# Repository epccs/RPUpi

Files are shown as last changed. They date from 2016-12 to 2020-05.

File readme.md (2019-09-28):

# RPUpi

From <https://github.com/epccs/RPUpi>

## Overview

Shield used to connect a Raspberry Pi Zero (or W) to serial that can be shared (multidrop). The targets presently available are [RPUno], [RPUlux], and [Irrigate7]. The hardware allows the bus to be controlled so the host sees a single target (for bootload) or any number of them.  

A [RPUadpt] shield is also available if the host SBC does not use the Raspberry Pi 40 pin header.

[RPUno]: https://github.com/epccs/RPUno
[RPUlux]: https://github.com/epccs/RPUlux
[Irrigate7]: https://github.com/epccs/Irrigate7
[RPUadpt]: https://github.com/epccs/RPUadpt
[RPUftdi]: https://github.com/epccs/RPUftdi

## Status

[Options](./Hardware#bill-of-materials)

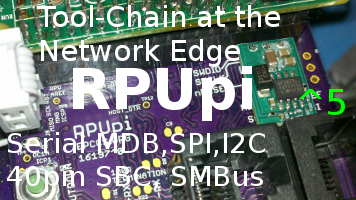
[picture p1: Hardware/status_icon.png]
Status


## [Hardware](./Hardware)

Hardware files include schematic and board images, bill of materials, and my notes on testing, evaluation, and schooling.

## Example

Both the SBC and microcontroller(s) can run simple UART serial communication software (e.g. all the RS232 software I have tried seems to work). I prefer textual commands, so my examples generally use a textual command processor which echoes back the command like an interactive terminal, the commands are used by the firmware command processor to run routines or configure state machines on the bare metal microcontrollers. The SBC host the toolchain so it can compile the firmware from the source which can be managed with git (e.g. GitHub, GitLab...) or anyway the user wishes. The toolchains uploader can be used to send the firmware to the targets bootloader. The result is one or more bare metal targets can receive updates that are compiled from source without the need for a bare metal network stack. This is not an IoT system, it is a computer hosting an operating system and toolchain connected with physical wires to bare metal embedded controllers. It is also not dependent on any cloud-based services.

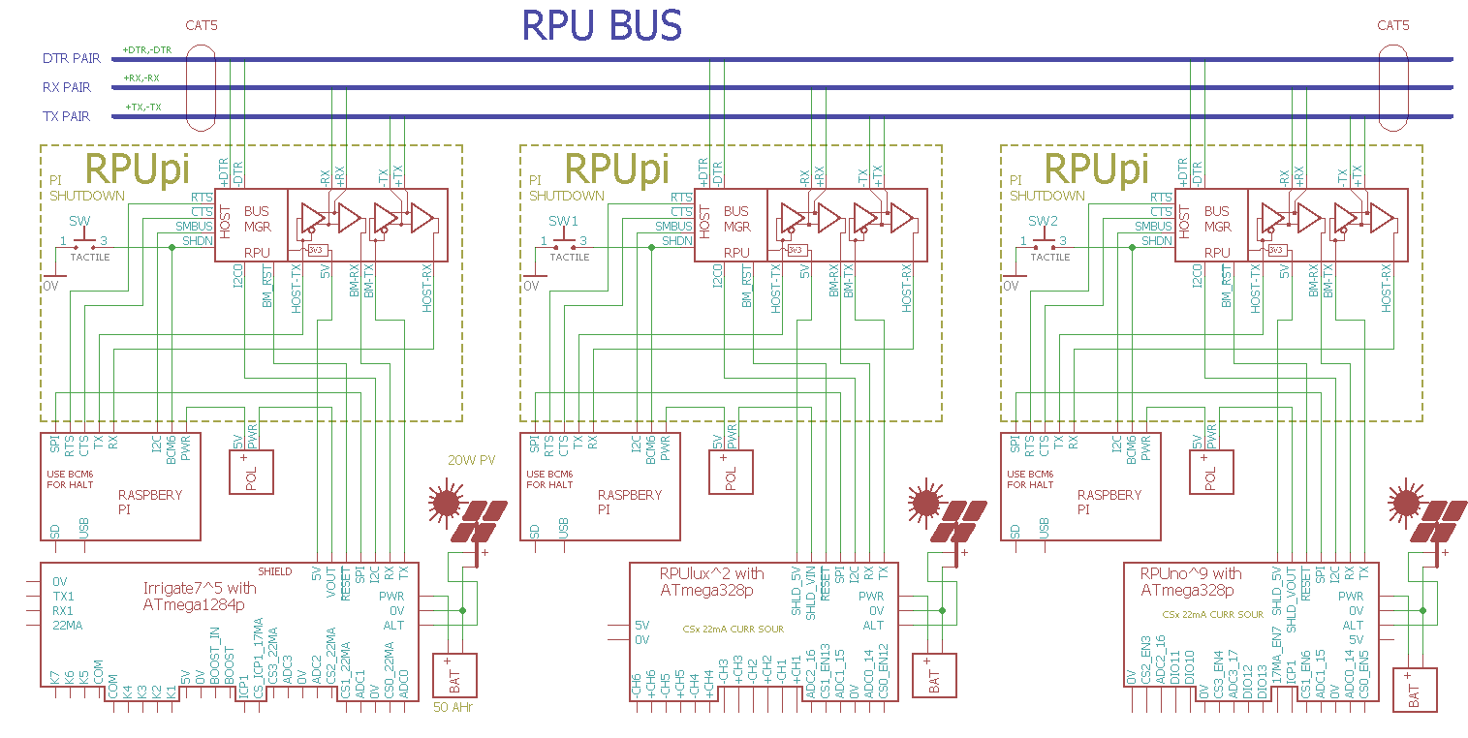
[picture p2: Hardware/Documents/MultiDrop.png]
MultiDrop


To bootload the AVR from the Raspberry Pi hardware serial port it needs to be enabled for [serial] so Linux can use the port, also the [RTS and CTS] pin functions should be enabled since nRTS is used to start the bootloader (in place of the nDTR trick used by an Arduino Uno). 

[serial]: ./Hardware/Testing/linux.md#serial
[RTS and CTS]: ./RPiRtsCts

The Pi Zero also needs a way to [halt] from a push button. When the RPUpi shield is mounted on a target board (e.g. [RPUno]) the VIN pin can be powered off with a [power management] technique.  This allows a manual shutdown and for the local target to request a halt using an I2C command. It should help with redundancy techniques, so two or more SBC's with [failover] can ensure data from the targets keep flowing. 

[failover]: https://en.wikipedia.org/wiki/Failover
[halt]: ./Shutdown
[power management]: https://github.com/epccs/RPUno/tree/master/PwrMgt

## AVR toolchain

The core files for this boards bus manager are in the /lib folder. Each example has its files and a Makefile in its own folder. The toolchain packages that I use are available on Ubuntu and Raspbian. 

```
sudo apt-get install git make gcc-avr binutils-avr gdb-avr avr-libc avrdude
git clone https://github.com/epccs/RPUpi
```

* [gcc-avr](https://packages.ubuntu.com/search?keywords=gcc-avr)
* [binutils-avr](https://packages.ubuntu.com/search?keywords=binutils-avr)
* [gdb-avr](https://packages.ubuntu.com/search?keywords=gdb-avr)
* [avr-libc](https://packages.ubuntu.com/search?keywords=avr-libc)
* [avrdude](https://packages.ubuntu.com/search?keywords=avrdude)

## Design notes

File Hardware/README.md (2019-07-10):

# Hardware

## Overview

This board connects a Pi Zero [W] to a multi-drop serial bus and a control board with a target (e.g. [RPUno], [RPUlux], [RPUicp], [Irrigate7]). 

[RPUno]: https://github.com/epccs/RPUno
[RPUlux]: https://github.com/epccs/RPUlux
[RPUicp]: https://github.com/epccs/RPUicp
[Irrigate7]: https://github.com/epccs/Irrigate7

## Inputs/Outputs/Functions

```
        Pi Zero power is from a 5V SMPS regulator powered by the Vin pin
        Pi Zero UART connects crossover style to the rpubus pairs
        rpubus pairs daisy-chain to other RPUpi or RPUadpt shields
        The UART's from multiple targets may connect to the rpubus pairs 
        An out of band management pair is used to control host to target (P2P) connection.
        SPI is available between SBC and the local target.
```

## Uses

```
        Raspberry Pi with a Raspian Linux instance is a compelling platform.
        Accessing the machine instance with SSH is prefered.
        Serving files with Samba is availalbe, but not prefered.
        The machine instance has a physical serial link (rpubus ) to the bare metal targets.
```

## Notice

```
        If the Pi Zero bootloads its local board (the one under the RPUpi) then 
        the VIN power from the local board must not turn off after a reset 
        (the defaut setup has been tested and works). 
 ```

# Table Of Contents

1. [Status](#status)
2. [Design](#design)
3. [Bill of Materials](#bill-of-materials)
4. [How To Use](#how-to-use)

# Status

Status RPUpi Status

```
        ^5  Done: Design, Layout, BOM, Review*, Order Boards, Assembly, Testing,
            WIP: Evaluation.
            Todo: 
            *during review the Design may change without changing the revision.
            AVR's nSS should goto R-Pi's nCE00 not nCE10.

        ^4  Done: Design, Layout, BOM, Review*, Order Boards, Assembly, Testing,
            WIP: Evaluation.
            Todo: 
            *during review the Design may change without changing the revision.
            IOREF is for I2C and UART
            SPI_IOREF is for SPI only
            Add SPI nSS so the Raspery Pi CE10 can use it, (it was tested with RPUadpt^6)
            remove ADC6 and ADC7.
            remove smd mounts for 100 Ohm pair termination.
            Use TI's 5V THVD1500, wich cost less and has better specs.
            Run Manager at 5V to match trancever's.
            Remove 3V3 regulator, which is no longer needed.
            Change Q1..Q3 to use K1N. 
```

Debugging and fixing problems i.e. [Schooling](./Schooling/)

Setup and methods used for [Evaluation](./Evaluation/)

# Design

The board is 0.063 thick, FR4, two layer, 1 oz copper with ENIG (gold) finish.

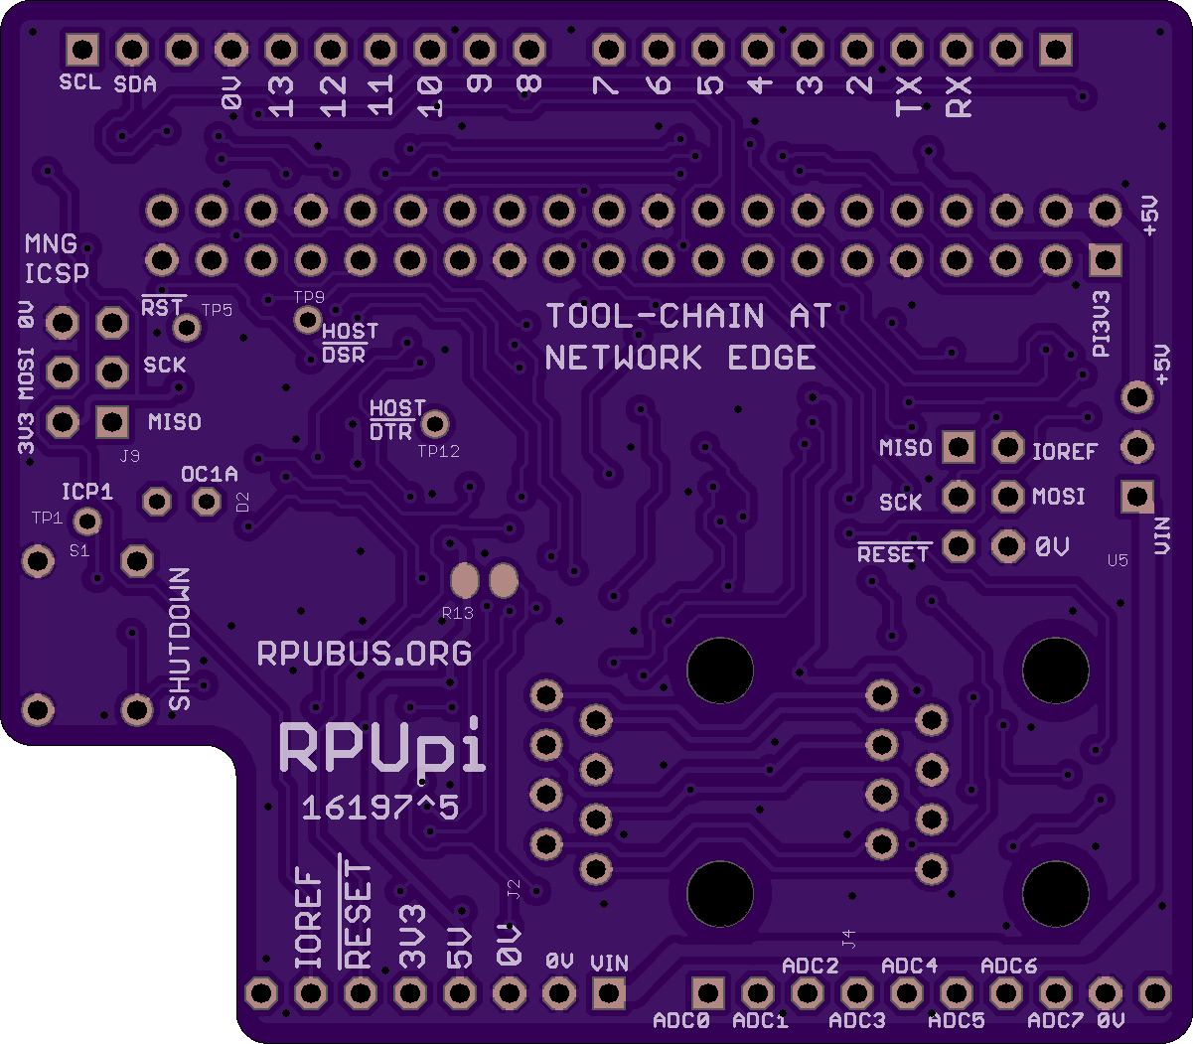
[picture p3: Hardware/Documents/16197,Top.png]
Top RPUpi Top

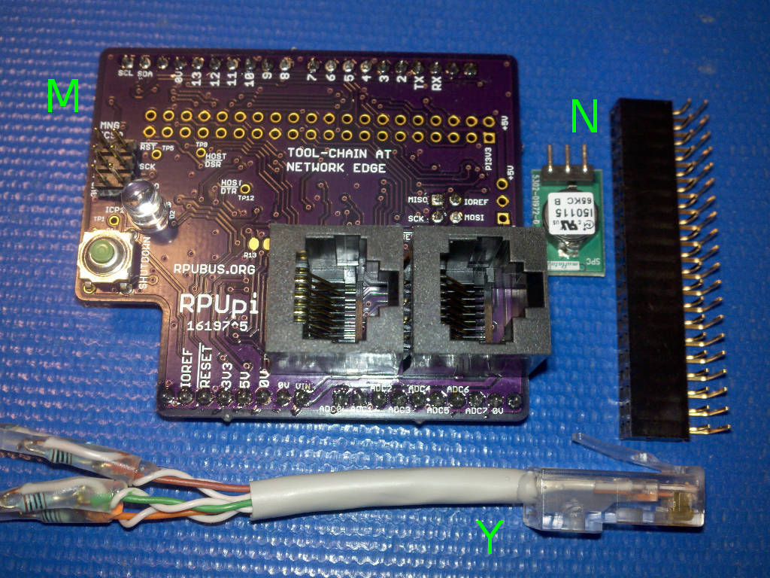
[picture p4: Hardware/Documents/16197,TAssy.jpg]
TAssy RPUpi Top Assy

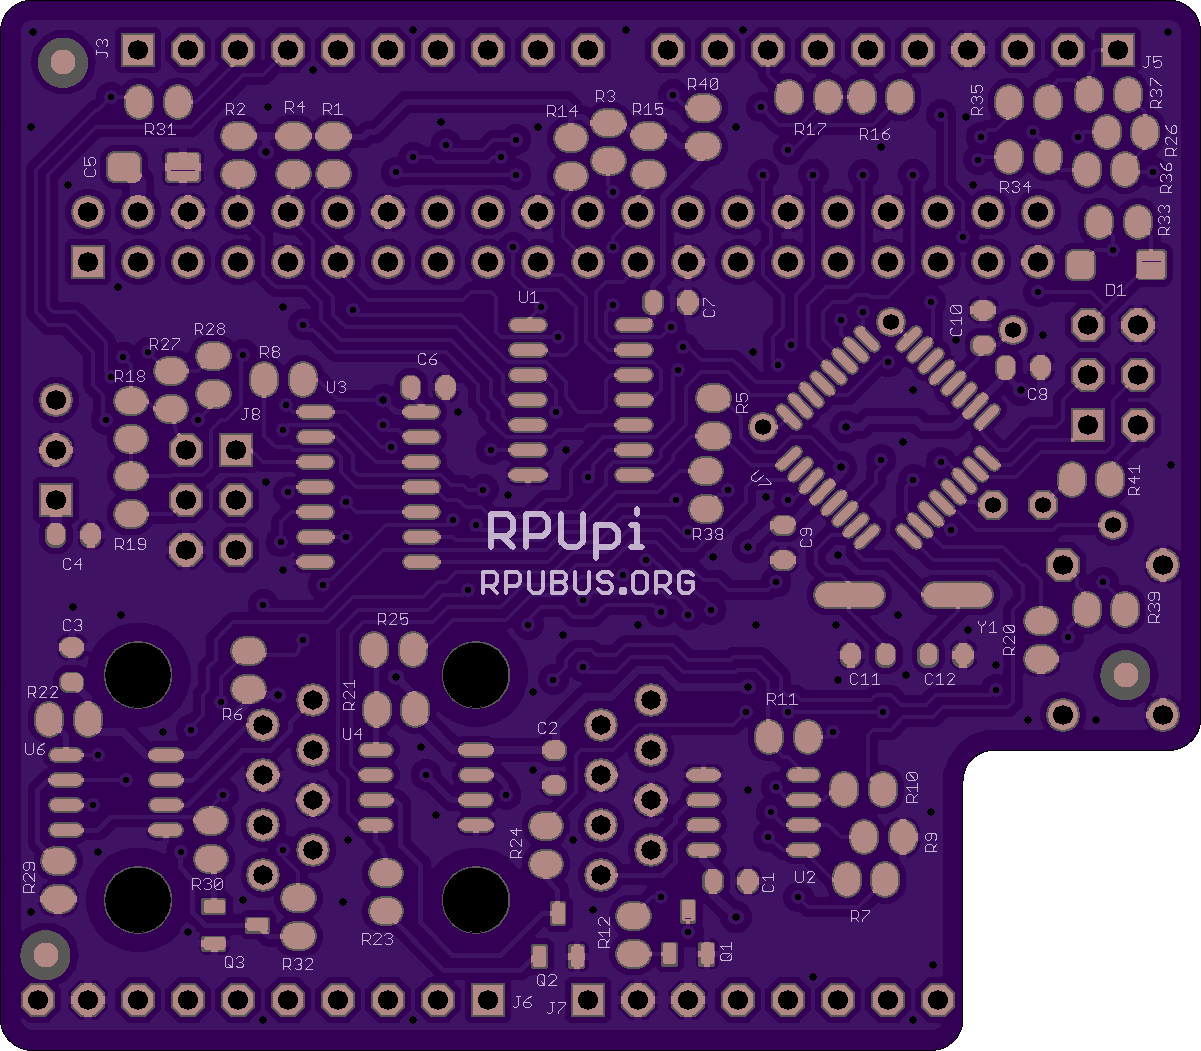
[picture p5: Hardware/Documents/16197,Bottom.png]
Bottom RPUpi Bottom

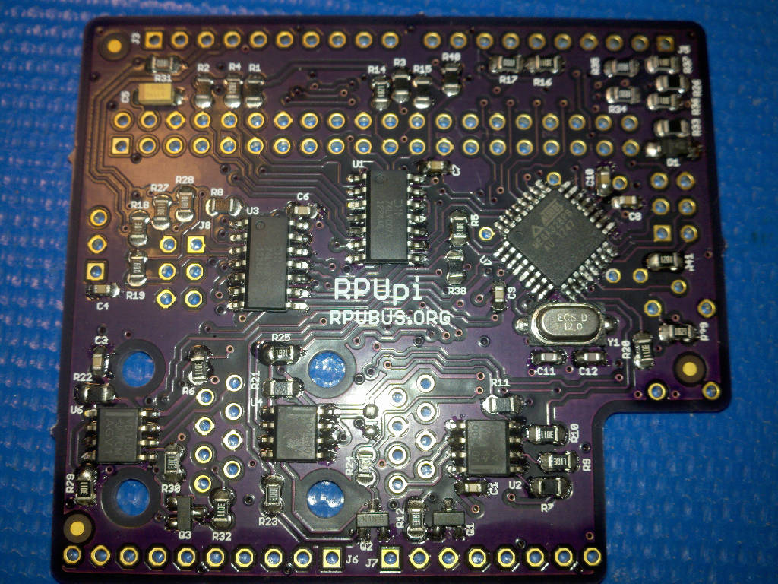
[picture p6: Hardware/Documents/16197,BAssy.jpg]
BAssy RPUpi Bottom Assy


## Electrical Parameters (Typical)

```
        VIN pin needs 7V to 30V (RPUno has 12.8V) at up to 4W for SMPS regulator to power a Pi Zero
        5V pin needs 150mA (RPUno has 1+ Amp) to power RPU_BUS
```

## Mounting

```
        Shield or Mezzanine
```

## Electrical Schematic

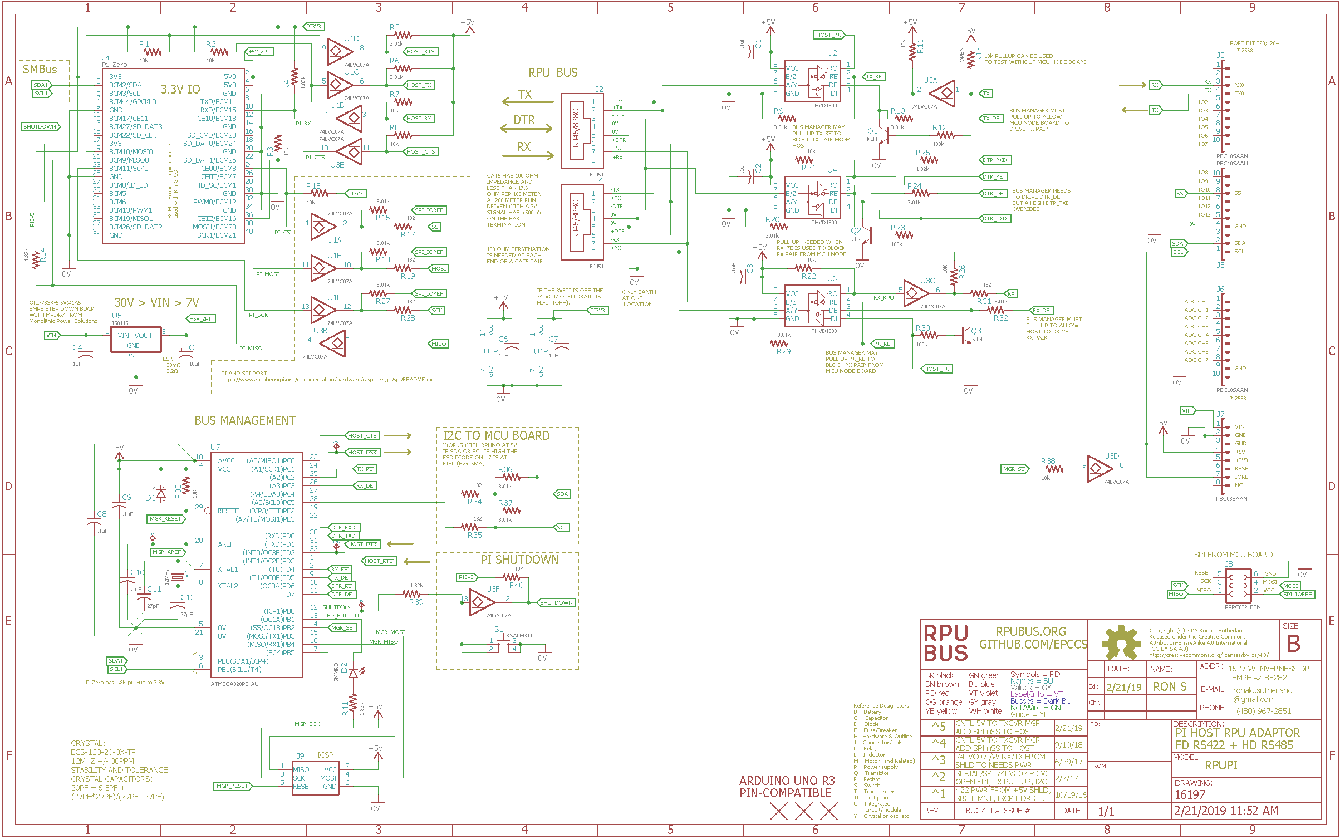
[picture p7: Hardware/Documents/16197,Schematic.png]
Schematic RPUpi Schematic


## Testing

Check correct assembly and function with [Testing](./Testing/)

# Bill of Materials

The BOM is a CVS file, import it into a spreadsheet program like LibreOffice Calc (or Excel), or use a text editor.

Option | BOM's included
----- | ----- 
A. | [BRD] 
M. | [BRD] [SMD] [HDR] 
N. | [BRD] [SMD] [HDR] [POL]
Y. | [BRD] [SMD] [HDR] [POL] [CAT5]

[BRD]: ./Design/16197BRD,BOM.csv
[SMD]: ./Design/16197SMD,BOM.csv
[HDR]: ./Design/16197HDR,BOM.csv
[POL]: ./Design/16197POL,BOM.csv
[CAT5]: ./Design/16197CAT,BOM.csv

[Order Form](https://rpubus.org/Order_Form.html)

# How To Use

Your [Raspberry Pi] is your computer, you are the expert because I am not. Don't buy an RPUpi board and expect that I can help with your computer, I can not. So far I have found that SSH works and the AVR toolchain, so I am able to serial bootload the  ATmega328p, ATmega328pb, and ATmega1284p. I have tested SMBus and found it works but it does not do clock stretching, so let's not call it I2C. I have also tested SPI somewhat. The serial console program I use is picocom, the install package is built to do standard baud rates (e.g. 38.4k bps) so that is what I have been using (250kbps may work with other programs). 

[Raspberry Pi]: https://www.raspberrypi.org/forums/

## Simplified Serial

To allow a hardware UART on a Raspberry Pi Single Board Computer to interface with an AVR UART the following connections can be used. Notice that the AVR is powered by 3.3V.

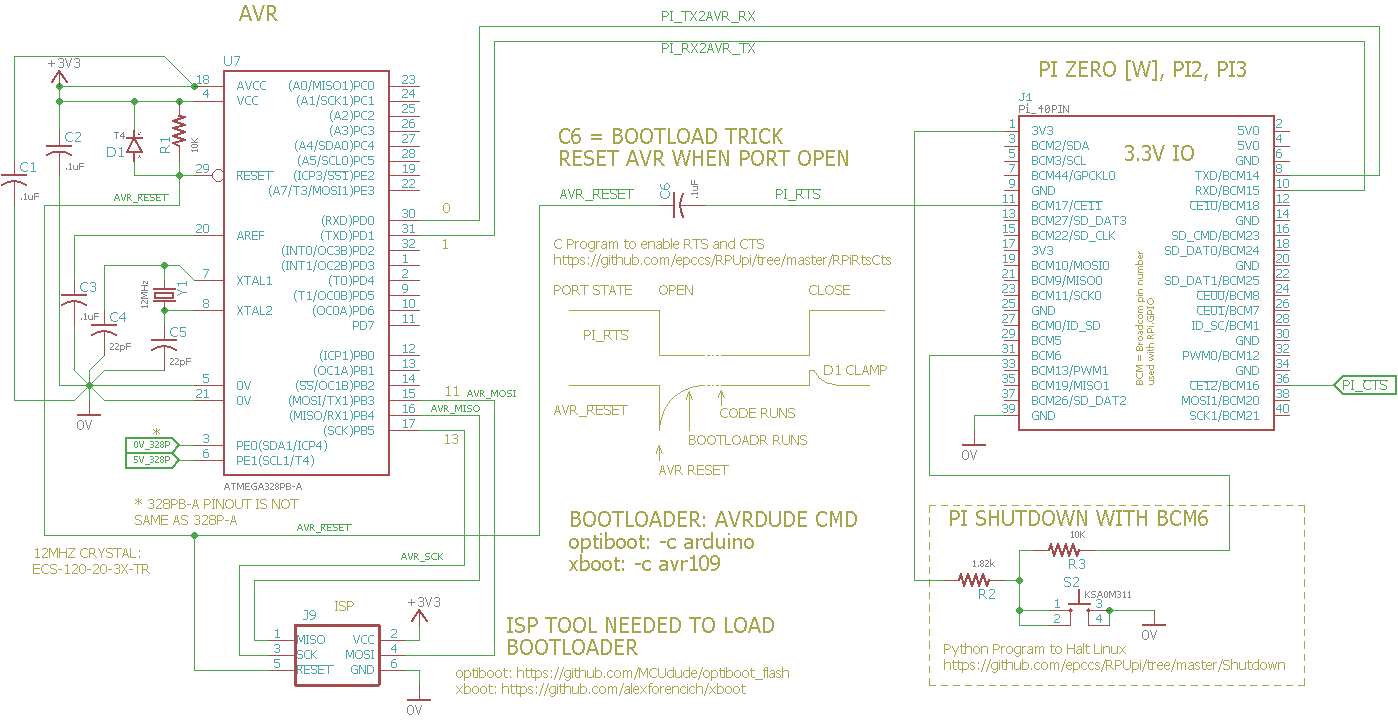
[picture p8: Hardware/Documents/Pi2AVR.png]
Pi2AVR Pi to AVR


Next, lets set things up to use an AVR at 5V. Using a buffer with IOFF for level shifting. Now I can turn off the SBC without locking (pulling down) the serial port lines (e.g. to the USB UART bridge).

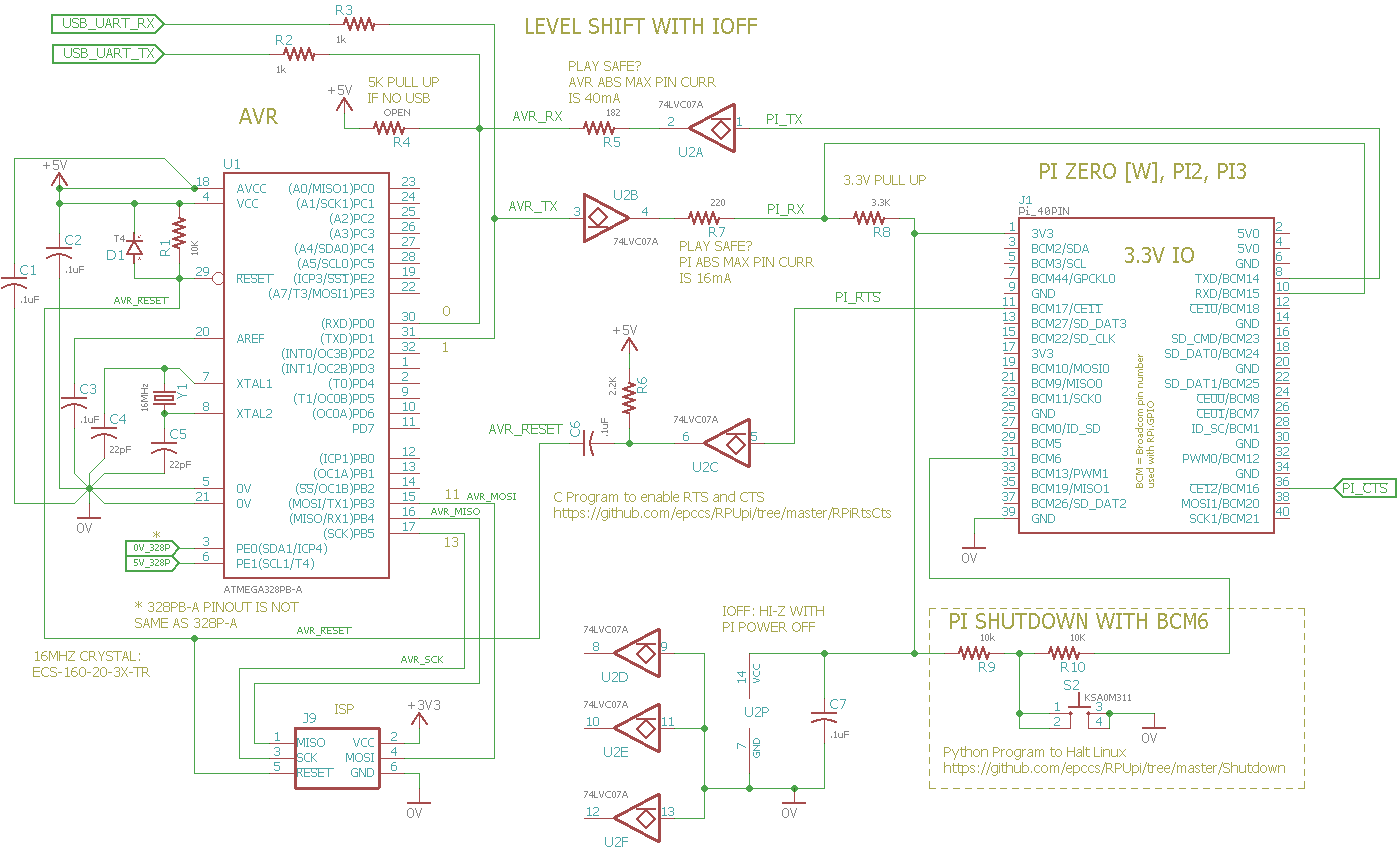
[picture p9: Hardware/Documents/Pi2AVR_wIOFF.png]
Pi2AVR_wIOFF Pi to AVR with IOFF


## ICSP

[ArduinoISP] sketch on an Uno or the [ICSP] tool is what I use to program the bus manager with the [Remote] firmware. I then plug the RPUpi onto a target board and load my application firmware (e.g. target [RPUno] can run [i2c-debug]). The RPUpi's SBC host can communicate via serial with other target boards that have an RPUBUS. The additional boards will need the [Remote] firmware (on there manager) to have a different bus address.

[ArduinoISP]: https://github.com/arduino/Arduino/blob/master/build/shared/examples/11.ArduinoISP/ArduinoISP/ArduinoISP.ino
[ICSP]: https://github.com/epccs/Driver/tree/master/ICSP
[Remote]: https://github.com/epccs/RPUpi/tree/master/Remote
[i2c-debug]: https://github.com/epccs/RPUno/tree/master/i2c-debug

## Pi Zero Setup 

The Pi Zero is a Single Board Computer (SBC) running [Linux]. I use it as a network machine and to run a toolchain at the network edge. It has enough memory and processing power for the AVR toolchain (and others that I have not tested). It also does self-hosted compiling for (e.g. compiles programs to run on itself) and has lots of applications and services. My use is sort of like a headless test bench computer embedded next to the bare metal control boards, I daisy-chain the serial to each target I want to bootload. Is it IoT, no it is not, it is a classic control system (but it is headless), but I can interact with the target boards over an SSH session (e.g. in other words it does what IoT should). 

[Linux]: ./Testing/linux.md

The BCM2835 Broadcom chip used in the Raspberry Pi Zero is an ARM11 running at 1 GHz it has good support with the [Raspbian] distribution. 

[Raspbian]: https://www.raspbian.org/

## Serial

The Pi serial port (RX is BCM 15 and TX is BCM 14) is crossover connected at the transceivers that drive the differential pairs and then connect to the shield's target header for Tx and Rx e.g. BCM Rx goes through a transceiver to the target's Tx pin on the shield. This allows the SBC to talk to the shield's target with serial as is expected as well as being copied to the other transceivers connected to the differential pairs. 

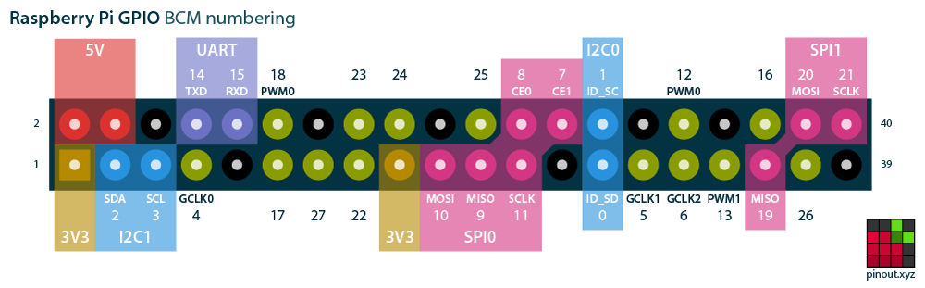
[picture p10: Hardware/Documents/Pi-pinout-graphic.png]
Pi Pinout


The Pi's handshake lines nCTS and nRTS lines are on BCM 16 and 17 when the ALT3 option is active. BCM 17 is on the original 26 pin Pi connector, but BCM 16 is on the new 40 pin connector (e.g. use a 40 pin model). I use this [rpirtscts] program as a command-line utility for enabling hardware flow control on the Pi Zero serial port. 

[rpirtscts]: https://github.com/epccs/RPUpi/tree/master/RPiRtsCts

On the RPUpi board, the Pi Zero serial lines (Rx, Tx, nRTS, and nCTS) have been interfaced through a 74LVC07A buffer which is powered from the Pi's 3V3 power. When the Pi Zero is powered off the IOFF feature of the buffer will hi-z the output (it's an open collector output) which will allow a pull-up to set the proper value on nRTS and the Tx line. This allows the RPUBUS to be used when the Pi Zero is powered off (or not plugged in). Also, a 74LVC07A buffer is used between the transceiver and the controller that the shield is pluged into so it can run at 3.3V or 5V, this buffer is powered from the controller so it works without the SBC.

When the Pi's handshake lines are enabled the nRTS line is used to start a targets bootloader. When avrdude opens the serial port the nRTS goes active, that is it pulls low the bus manager sees this and broadcast a bootload address on the DTR pair causing everything but the bootload device which is also reset to lockout and thus avrdude sees a single target running its serial bootloader. Since picocom does the same thing I have to make sure the target is one I want to reset, and then have to wait for that targets bootloader to timeout and its application to get the bus address from its shield. 

## Full Duplex Serial Management

The shield has a manager that can enable each transceiver's receiver and driver so that the targets can be isolated or connected from the serial bus; the implications are significant. The original intent was to allow boot loading with a point to point full duplex mode (e.g., target with optiboot/xboot and the host running avrdude). It supports boot loading a new executable binary image over a severely goofed up bare metal application; I have tried to retain the nearly bulletproof upload found with RS232 using optiboot and avrdude.

## Transceiver (RS-485)

The transceivers used have a built-in fail-safe bias, which is a little complicated to explain, but it makes an undriven bus (e.g., 0V is the failed condition) a defined logic state (HIGH). That is if I turn off the transceiver driving the bus (only one should steer the bus at any time), it is guaranteed to be in a defined state (e.g., HIGH). I have set up the transceivers to automatically turn off the driver while the UART output is HIGH (its default value). That means the driver will automatically drive the bus only when data is sent, so nothing needs to be done in software to turn on or off the transceivers. The bus manager may override.

## SPI

The SBC's SPI lines (MOSI, SCK, MISO, ^4 adds nSS) are interfaced through a 74LVC07A buffer. The lines MOSI, SCK, and nSS are powered from the SBC 3V3 power. When the SBC is powered off the IOFF feature of the buffer will hi-z its open collector output which will allow a pull-up to set the value on SCK and the MOSI line or allow the MCU to control them. 

Known issues: RPUno has its SPI lines run to user connectors for digital control so make sure those are free if SPI is to be used.

## I2C

The SBC has an SMBus port when it is running Linux. The Raspberry Pi Zero has 1.8k pull-ups to 3.3V, and when it is powered down those resistors pull the I2C lines and lock the bus. That is why the ^4 manager has an ATmega328pb. The second I2C port can talk to the SBC with SMBus commands, and the original I2C port can talk to the target.

## SD

SBC SD Card [corruption] can happen when the SD card is doing wear leveling operations at the time power is removed. It is possible with this setup to push the shutdown button and have that run a [Shutdown] script. Also, the local programmable controller can initiate a power down with [PwrMgt] which monitors power before killing power to the shield (VIN pin). The idea is that wear leveling will draw current somewhat randomly until all the page updates are done. The BCM2835 will be halted, and looping (it is checking one of the I2C pins) and using a steady current draw. So when the current draw is stable, the wear leveling should be done and safe to disconnect the shield VIN.

[Shutdown]: https://github.com/epccs/RPUpi/tree/master/Shutdown
[PwrMgt]: https://github.com/epccs/RPUno/tree/master/PwrMgt
[corruption]: https://hackaday.com/2016/08/03/single-board-revolution-preventing-flash-memory-corruption/

## Security

Do not bootload bare metal over links that can have adversaries in the middle.

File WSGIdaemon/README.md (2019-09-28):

# WSGIdaemon

## ToDo

Improve documentation and references

https://www.fullstackpython.com/wsgi-servers.html

Test on the R-Pi, so far this has only been used on a Ubuntu 18.04 desktop (using an RPUftdi shield).

look at [modern-web-development] ideas

[modern-web-development]: https://www.vrk.dev/2019/07/11/why-is-modern-web-development-so-complicated-a-long-yet-hasty-explanation-part-1/

also look at way to trap a hangup signal

https://hackaday.com/2019/08/26/linux-fu-its-a-trap/

## Overview

Web Server Gateway Interface (WSGI) daemon for serial

The idea is to use the gateway to convert an HTTP request into a command for the serial link, the commands I use resemble "/0/id?". The second character is an address on the serial bus (it is a multi-drop), the command is "id", and the "?" means it is a query.

The daemon has now been set to allow the origin to be from everywhere, which means Cross-Origin Resource Sharing (CORS) does not need turned off in the browser. The reference I used to do this is over seven years old so if someone has a better idea please add an issue and suggest.

## Startup

run at a terminal command line

```
python3 WSGIdaemon.py
```

run in background

```
python3 WSGIdaemon.py &
exit 0
```

run at startup, place the script in /home/my_user_name/bin and make it executable, then tell the system to run it from /etc/rc.local

```
[su my_user_name]
[mkdir bin]
cd bin
wget https://raw.githubusercontent.com/epccs/RPUpi/master/WSGIdaemon/WSGIdaemon.py
chmod ugo+x WSGIdaemon.py
sudo nano /etc/rc.local
```

Follow these rc.local [recommendations].

[recommendations]: https://www.raspberrypi.org/documentation/linux/usage/rc-local.md

To stop the daemon

```
ps aux | grep 'WSGIdaemon'
# the number in second column is the WSGIdaemon-pid
kill -TERM [WSGIdaemon-pid]
# if wsgiref.simple_server.make_server.serve_forever has ignored it
kill -KILL [WSGIdaemon-pid]
```

## Browser as Client

Place URL in a browser (the host I have the WSGIdaemon running on is at 192.168.0.7)

```
http://192.168.0.7:8000/?addr=0&cmd=id&q=true
```

Which sends the command "/0/id?" and I get back this JSON from a board on my test bench.

```
{"id":{"name":"I2Cdebug^1","desc":"RPUno (14140^9) Board /w atmega328p","avr-gcc":"5.4.0"}}
```

Now with arguments (arg1..arg5) have added.

```
http://192.168.0.7:8000/?addr=0&cmd=iaddr&q=false&arg1=41
```

Which sends the command "/0/iaddr 41" and I get back this JSON. 

```
{"address":"0x29"}
```

That is the bus manager I2C address (an I2C slave) on the RPUftdi (same for RPUadpt and RPUpi) shield mounted on the RPUno.  The RPUno is running [i2c-debug] software.

[i2c-debug]: https://github.com/epccs/RPUno/tree/master/i2c-debug

Next open the "client.html" file as a flat stand-alone HTML sourced from the disk with Edge, Chrome, or Firefox. Make sure to modify the HTML file so that the correct host address is used (e.g. it has to match the WSGIdaemon host.

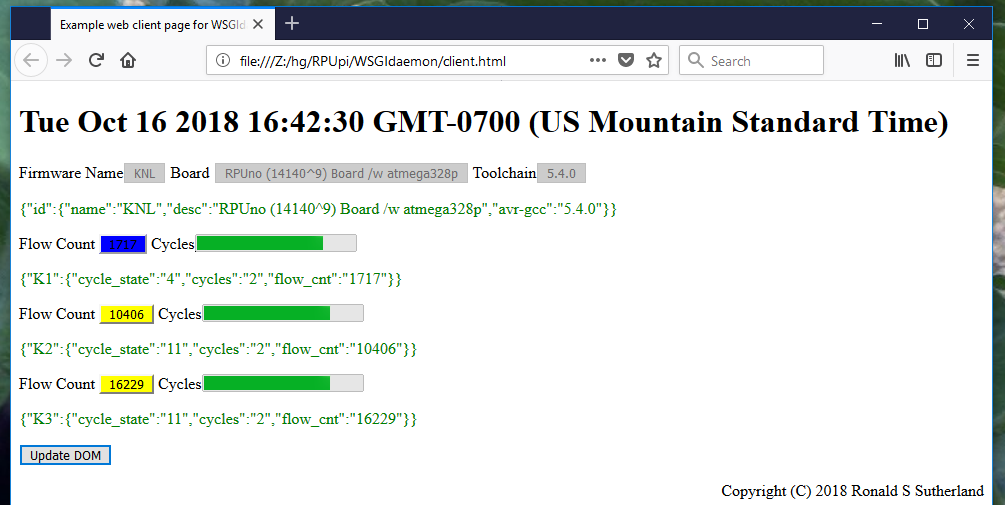
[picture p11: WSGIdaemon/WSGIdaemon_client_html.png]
client_html client html example


the blue button is from cycle_state, which means the irrigation valve is flowing. The flow count is updated as the cycle_state machine advances. The solenoid control cycle_states that are normally reported are 0,4, and 11 but others can show up and that would be like winning the lottery.

https://github.com/epccs/RPUno/blob/028b808fae9b6b1022a0e60a702f900a3815a00d/Solenoid/solenoid.c#L791

## Python as Client

A quick look at Python as the client.

https://2.python-requests.org//en/master/

```Python
#!/usr/bin/env python3
import requests

r = requests.get('http://192.168.0.7:8000/?addr=1&cmd=id&q=true')
if (r.status_code == 200):
    print( str(r.json()) )
    print( "id.name=" + str(r.json()["id"]["name"]))
```

WSGIdaemon turns "?addr=1&cmd=id&q=true" into "/1/id?" and sends that to the AVR. The AVR sends back a JSON reply: {'id': {'name': 'KNL', 'desc': 'RPUno (14140^9) Board /w atmega328p', 'avr-gcc': '5.4.0'}}, which the WSGIdaemon sends back, and requests can turn the json right into a dictionary.

## WSGI Python Referance

[PEP-3333] is a good overview, it is important to read things like that when encode and decode have pushed the wrong buttons. It is unbelievable that this stuff works at all. 

[PEP-3333]: https://www.python.org/dev/peps/pep-3333/

* For WSGI see https://docs.python.org/3.7/library/wsgiref.html
* For CGI see https://docs.python.org/3.7/library/cgi.html

## WSGI Python Frameworks (more referance)

It is not clear to me what these frameworks do, or if thay can act as a serial device gateway.

* For Flask see https://github.com/pallets/flask
* For Bottle see https://github.com/bottlepy/bottle

Flask has a lot a [documentation] and that is probably what I need to use it. If I do work on such a project I will start a separate repository for it. 

[documentation]: https://palletsprojects.com/p/flask/

## WSGI and Cross-Origin Resource Sharing (CORS)

Modern web browsers have implemented the W3C standard [CORS] that allows the browser to have a same-origin policy. This policy means the browser will only allow callbacks from URL's inside a page that has the same origin (scope), that is they have identical schemes, hosts, and ports ([RFC 6454]).

[CORS]: https://www.w3.org/TR/cors/
[RFC 6454]: https://tools.ietf.org/html/rfc6454

* Microsoft notes https://docs.microsoft.com/en-us/aspnet/core/security/cors?view=aspnetcore-2.1
* Mozilla notes https://developer.mozilla.org/en-US/docs/Web/HTTP/CORS
* Google notes https://cloud.google.com/storage/docs/cross-origin

CORS can be turned off in Firefox with this extension (check if a callback works then remove it)

* Cors Everywhere https://github.com/spenibus/cors-everywhere-firefox-addon

The Same-Origin Policy

* http://www.aosabook.org/en/500L/the-same-origin-policy.html

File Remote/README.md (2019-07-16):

# Remote

This firmware is for the bus manager on an RPUpi board, it will watch for a byte matching the local RPU_ADDRESS on the DTR pair and when seen reset the local controller placing it in bootloader mode. A non-matching byte will disconnect the RX and TX lines from the local controller and be in lockout mode until a LOCKOUT_DELAY completes or an RPU_NORMAL_MODE byte is seen on the DTR pair.

## Overview

In normal mode, the RX and TX lines (twisted pairs) are connected through transceivers to the controller board RX and TX pins while the DTR pair is connected to the bus manager UART and is used to set the system-wide bus state.

During lockout mode, the RX and TX serial lines are disconnected at the transceivers from the controller board RX and TX pins. Use LOCKOUT_DELAY to set the time in mSec.

Bootload mode occurs when a byte on the DTR pair matches the RPU_ADDRESS of the shield. It will cause a pulse on the reset pin to activate the bootloader on the local microcontroller board. After the bootloader is done, the local microcontroller will run its application, which, if it reads the RPU_ADDRESS will cause the manager to send an RPU_NORMAL_MODE byte on the DTR pair. The RPU_ADDRESS is read with a command from the controller board. If the RPU_ADDRESS is not read, the bus manager will timeout but not connect the RX and TX transceivers to the local controller board. Use BOOTLOADER_ACTIVE to set the time in mSec; it needs to be less than LOCKOUT_DELAY.

The lockout mode occurs when a byte on the DTR pair does not match the RPU_ADDRESS of the manager. It will cause the lockout condition and last for a duration determined by the LOCKOUT_DELAY or when an RPU_NORMAL_MODE byte is seen on the DTR pair.

When nRTS (or nDTR on RPUadpt) are pulled active the bus manager will connect the HOST_TX and HOST_RX lines to the RX and TX pairs, and pull the nCTS (and nDSR) lines active to let the host know it is Ok to send. If the bus is in use, the host will remain disconnected from the bus. Note the Remote firmware sets a status bit at startup that prevents the host from connecting until it is cleared with an I2C command.

Arduino Mode is a permanent bootload mode so that the Arduino IDE can connect to a specific address (e.g., point to point). It needs to be enabled by I2C or SMBus. The command will cause a byte to be sent on the DTR pair that sets the arduino_mode thus overriding the lockout timeout and the bootload timeout (e.g., lockout and bootload mode are everlasting).

Test Mode. I2C command to swithch to test_mode (save trancever control values). I2C command to recover trancever control bits after test_mode.

## Firmware Upload

Use an ICSP tool connected to the bus manager (set the ISP_PORT in Makefile) run 'make' to compile then 'make isp' to flash the bus manager.

```
sudo apt-get install make git gcc-avr binutils-avr gdb-avr avr-libc avrdude
git clone https://github.com/epccs/RPUpi/
cd /RPUpi/Remote
make
make isp
...
avrdude done.  Thank you.
```

## R-Pi Prep

```
sudo apt-get install i2c-tools python3-smbus
sudo usermod -a -G i2c your_username
# logout for the change to take
```

## Addressing

The Address '1' on the RPU_BUS is 0x31, (e.g., not 0x1 but the ASCII value for the character).

When HOST_nRTS is pulled active from a host trying to connect to the serial bus, the local bus manager will set localhost_active and send the bootloader_address over the DTR pair. If an address received by way of the DTR pair matches the local RPU_ADDRESS the bus manager will enter bootloader mode (marked with bootloader_started), and connect the shield RX/TX to the RS-422 (see connect_bootload_mode() function), all other addresses are locked out. After a LOCKOUT_DELAY time or when a normal mode byte is seen on the DTR pair, the lockout ends and normal mode resumes. The node that has bootloader_started broadcast the return to normal mode byte on the DTR pair when that node has the RPU_ADDRESS read from its bus manager over I2C (otherwise it will time out and not connect the controller RX/TX to serial).

## Bus Manager Modes

In Normal Mode, the RPU bus manager connects the local controller to the RPU bus if it is RPU aware (e.g., ask for RPU_ADDRESS over I2C). Otherwise, it will not attach the local MCU's TX to the bus but does connect RX. The host side of the transceivers connects unless it is foreign (e.g., keep out the locals when foreigners are around).

In bootload mode, the RPU bus manager connects the local controller to the serial bus. Also, the host will be connected unless it is foreign. It is expected that all other nodes are in lockout mode. Note the BOOTLOADER_ACTIVE delay is less than the LOCKOUT_DELAY, but it needs to be in bootload mode long enough to allow uploading. A slow bootloader will require longer delays.

In lockout mode, if the host is foreign, both the local controller and Host are disconnected from the bus. Otherwise, the host remains connected.

## I2C and SMBus Slave

There are two TWI interfaces one acts as an I2C slave and is used to connect with the local microcontroller, while the other is an SMBus slave and connects with the local host (e.g., an R-Pi.) The commands sent are the same in both cases, but Linux does not like repeated starts or clock stretching so the SMBus read is done as a second bus transaction. I'm not sure the method is correct, but it seems to work, I echo back the previous transaction for an SMBus read. The masters sent (slave received) data is used to size the reply, so add a byte after the command for the manager to fill in with the reply. The I2C address is 0x29 (dec 41) and SMBus is 0x2A (dec 42). It is organized as an array of commands. 

[Point To Multi-Point] commands 0..15 (Ox00..0x0F | 0b00000000..0b00001111)

[Point To Multi-Point]: ./PointToMultiPoint.md

0. read the RPU_BUS address and activate normal mode (broadcast if localhost_active).
1. set the RPU_BUS address and write it to EEPROM.
2. read the address sent when DTR/RTS toggles.
3. write the address that will be sent when DTR/RTS toggles
4. read shutdown switch (the ICP1 pin has a weak pull-up and a momentary switch).
5. set shutdown switch (pull down ICP1 for SHUTDOWN_TIME to cause the host to halt).
6. reads status bits [0:DTR readback timeout, 1:twi transmit fail, 2:DTR readback not match, 3:host lockout].
7. writes (or clears) status.

[Point To Point] commands (control unit must not read the manager address or it will set up multi-point) 64..127 (Ox10..0x1F | 0b00010000..0b00011111)

[Point To Point]: ./PointToPoint.md

16. set arduino_mode 
17. read arduino_mode

reserved (for PWR_I, PWR_V reading) 32..47 (Ox20..0x2F | 0b10000000..0b10111111)

test_mode commands 48..63 (Ox30..0x3F | 0b00110000..0b00111111)

48. save trancever control bits HOST_nRTS:HOST_nCTS:TX_nRE:TX_DE:DTR_nRE:DTR_DE:RX_nRE:RX_DE for test_mode.
49. recover trancever control bits after test_mode.
50. read trancever control bits durring test_mode, e.g. 0b11101010 is HOST_nRTS = 1, HOST_nCTS =1, DTR_nRE =1, TX_nRE = 1, TX_DE =0, DTR_nRE =1, DTR_DE = 0, RX_nRE =1, RX_DE = 0.
51. set trancever control bits durring test_mode, e.g. 0b11101010 is HOST_nRTS = 1, HOST_nCTS =1, TX_nRE = 1, TX_DE =0, DTR_nRE =1, DTR_DE = 0, RX_nRE =1, RX_DE = 0.

[Test Mode]: ./TestMode.md

Connect to i2c-debug on an RPUno with an RPU shield using picocom (or ilk). 

``` 
picocom -b 38400 /dev/ttyUSB0
``` 

## RPU /w i2c-debug scan

Scan for the I2C0 slave address of shield and address.

``` 
picocom -b 38400 /dev/ttyUSB0
/1/id?
{"id":{"name":"I2Cdebug^1","desc":"RPUno (14140^9) Board /w atmega328p","avr-gcc":"5.4.0"}}
/1/iscan?
{"scan":[{"addr":"0x29"}]}
```

## Raspberry Pi to scan the shields SMBus address

The I2C1 port is for SMBus access. A Raspberry Pi is set up as follows.

```
i2cdetect 1
WARNING! This program can confuse your I2C bus, cause data loss and worse!
I will probe file /dev/i2c-1.
I will probe address range 0x03-0x77.
Continue? [Y/n] Y
     0  1  2  3  4  5  6  7  8  9  a  b  c  d  e  f
00:          -- -- -- -- -- -- -- -- -- -- -- -- --
10: -- -- -- -- -- -- -- -- -- -- -- -- -- -- -- --
20: -- -- -- -- -- -- -- -- -- -- 2a -- -- -- -- --
30: -- -- -- -- -- -- -- -- -- -- -- -- -- -- -- --
40: -- -- -- -- -- -- -- -- -- -- -- -- -- -- -- --
50: -- -- -- -- -- -- -- -- -- -- -- -- -- -- -- --
60: -- -- -- -- -- -- -- -- -- -- -- -- -- -- -- --
70: -- -- -- -- -- -- -- --
```

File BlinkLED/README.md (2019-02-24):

# BlinkLED

## Overview

Blink the on board LED plus debug the host I2C interface (e.g. the secnond I2C port on ATmega328pb).

## Firmware Upload

Use an ICSP tool connected to the bus manager (set the ISP_PORT in Makefile) run 'make isp' and it should compile and then flash the bus manager.

```
sudo apt-get install make git gcc-avr binutils-avr gdb-avr avr-libc avrdude
git clone https://github.com/epccs/RPUpi/
cd /RPUpi/BlinkLED
make isp
...
avrdude done.  Thank you.
```

## How To Use

The [i2c-debug] firmware on an RPUno can be used to test the I2C host manager interface, its address is at 0x2A. The RPUno controler has its own manager interfac at 0x29. 

[i2c-debug]: https://github.com/epccs/RPUno/tree/master/i2c-debug

```
picocom -b 38400 /dev/ttyUSB0
...
Terminal ready
/0/iscan?
{"scan":[{"addr":"0x29"},{"addr":"0x2A"}]}
/0/iaddr 42
{"address":"0x2A"}
/0/ibuff 0,3
{"txBuffer[2]":[{"data":"0x0"},{"data":"0x3"}]}
/0/iwrite
{"returnCode":"success"}
#blinking has stopped
/0/ibuff 0
{"txBuffer[2]":[{"data":"0x0"}]}
/0/iread? 2
{"rxBuffer":[{"data":"0x0"},{"data":"0xFC"}]}
```

SMBus (???do not asume I have done this is right???): After write_i2c_block_data the 328pb holds the old data. When read_i2c_block_data occures it will put a I2C packet with the address followed by a request to read (which is the active transaction), at whcih point the slave returns the data for the previous write (e.g. the previous transaction). Now have a look at the [Python program] for a Raspery Pi.

[Python program]: https://github.com/epccs/RPUadpt/tree/master/BlinkLED/toggle.py

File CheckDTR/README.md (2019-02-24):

# Check DTR

## Overview

Use during hardware tesing after building a board, this is not an applicaiton.

``` 
delay 4000
set DTR_TXD LOW so U4 DI input has 0V.
set DTR_DE HIGH to drive DTR pair, so R12 has 3.3V.
set DTR_nRE LOW cause U4 to copy DTR pair to RO output
blink 1
test DTR_RXD == LOW
delay 1000
set DTR_TXD HIGH which should cause an undriven pair
blink 2
test DTR_RXD == HIGH
delay 1000
set DTR_DE LOW
set DTR_nRE HIGH to disconned RO so R10 pulls up DTR_RXD
set DTR_TXD LOW to drive pair low
blink 3
test DTR_RXD == HIGH
delay 1000
set DTR_DE  HIGH connect DI from DTR pair.
blink 4
test DTR_RXD == HIGH
loop
``` 

## Firmware Upload

Use an ICSP tool connected to the bus manager (set the ISP_PORT in Makefile) run 'make isp' and it should compile and then flash the bus manager.

```
sudo apt-get install make git gcc-avr binutils-avr gdb-avr avr-libc avrdude
git clone https://github.com/epccs/RPUpi/
cd /RPUpi/CheckDTR
make isp
...
avrdude done.  Thank you.
```

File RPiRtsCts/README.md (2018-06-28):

# rpirtsrtc

[rpirtscts] makes a linux command for enabling the hardware flow control pins for the `ttyAMA0` serial port on a [Raspberry Pi].

[rpirtscts]: https://github.com/mholling/rpirtscts
[Raspberry Pi]: http://www.raspberrypi.org/

## Usage

Building the program:

```
sudo apt-get install git
# I like to put my git repos in a samba share
[mkdir Samba]
[cd Samba]
git clone git://github.com/epccs/RPUpi.git
```

Set the working directory, build the executable, and place it in the bin directory (a convenient place for that sort of stuff):

```
cd RPUpi/RPiRtsCts
make
cp rpirtscts ~/bin/rpirtscts
make clean
cd ~
chmod ugo+x ~/bin/rpirtscts
```

Follow these rc.local [recommendations].

[recommendations]: https://www.raspberrypi.org/documentation/linux/usage/rc-local.md

Startup with RTS handshacking on.

```
/home/rsutherland/bin/rpirtscts on &
exit 0
```

Now when I use picocom or avrdude it will pull RTS active.

```
picocom -b 38400 /dev/ttyAMA0
```

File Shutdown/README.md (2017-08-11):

# Shutdown

## Overview

This program will shutdown the Pi Zero when the switch on BCM6 is pressed.

I place the script in /home/rsutherland/bin and make it executable, then tell the system to run it from /etc/rc.local

```
[su rsutherland]
[mkdir bin]
cd bin
wget https://raw.githubusercontent.com/epccs/RPUpi/master/Shutdown/shutdown-sw.py
chmod ugo+x shutdown-sw.py
sudo nano /etc/rc.local
```

Follow these rc.local [recommendations].

[recommendations]: https://www.raspberrypi.org/documentation/linux/usage/rc-local.md

```
...
python /home/rsutherland/bin/shutdown-sw.py &
exit 0
```

To test run it sudo is needed.

``` 
sudo python /home/rsutherland/bin/shutdown-sw.py &
``` 

## Notes

The bus management on RPUpi should set its PB0 pin to have a weak pull-up (which is about 60k Ohm to +3V3) so it can also see the shutdown switch pressed. It can also actively pull the Pi shutdown low if PB0 is set as an output (LOW).

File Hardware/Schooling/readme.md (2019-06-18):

# Description

Some lessons I learned doing RPUpi.

# Table Of Contents:

1. ^5 SMBus Confusion
1. ^4 Bootload Speed
1. ^4 nSS to CE10 WTF
1. ^3 Connect nSS to SBC CE10
1. ^2 Protect I2C With 182 Ohm 
1. ^2 RS-422 Buffer needs Power
1. ^1 Serial When Powered Down
1. ^1 Pi Zero Placement
1. ^1 Open SCK and MOSI
1. ^1 Pi Tx Pull-Up
1. ^1 I2C
1. ^0 U3 Placed Backward

## ^5 SMBus Confusion

I have been using the Python write_i2c_block_data and read_i2c_block_data. It is from:

https://git.kernel.org/pub/scm/utils/i2c-tools/i2c-tools.git/

at this time the read function is at line 519.

https://git.kernel.org/pub/scm/utils/i2c-tools/i2c-tools.git/tree/py-smbus/smbusmodule.c#n519

Looking at the SMBus_read_i2c_block_data function, I see nothing about an OFFEST; in fact, I see nothing about OFFSET anywhere so I guess that idea was from looking at the smbus2 implementation which does say it is a drop-in replacement. Anyway, it is a command byte, not an offset; it is sent as data just before a repeated start after which the slave address is repeated and data bytes are read back. 

This is an example of reading a 32bit value from an SMBus device with Wire that I found.

```
uint32_t read32u(uint8_t device_comand)
{
	uint32_t registerValue;
      Wire.beginTransmission(I2C_Address);
	Wire.write(device_comand);
	Wire.endTransmission();
	Wire.requestFrom(I2C_Address,4,true);
	registerValue = Wire.read();
        registerValue |= (Wire.read()<<8);
        registerValue |= (Wire.read() << 16);
        registerValue |= (Wire.read() << 24);
	Wire.endTransmission();
        return registerValue;
}
```

My thinking is that a write_i2c_block_data(42, 192, [1]) does this. 

``` 
/1/iaddr 42
{"address":"0x2A"}
/1/ibuff 192,1
{"txBuffer[2]":[{"data":"0xC0"},{"data":"0x01"}]}
/1/iwrite
{"returnCode":"success"}
```

And that read_i2c_block_data(42, 192, 2) does this.

```
/1/ibuff 192
{"txBuffer[2]":[{"data":"0xC0"}]}
/1/iread? 2
{"rxBuffer":[{"data":"0xC0"},{"data":"0x01"}]}
```

Unfortunately, the return value is [64,0x1] shows that clock-stretching has corrupted that data. It is a known bug; the BCM2835 (e.g., R-Pi 0) picks up on a stretched clock only during the second half of the clock cycle. It only work at the end of I2C-read-ACK-phases (after reading ACK/NACK), not at the beginning. 

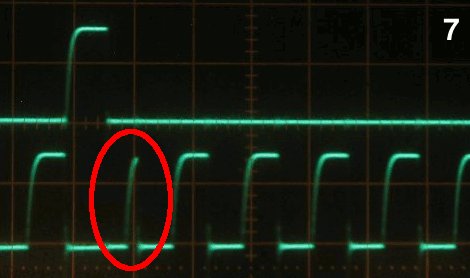
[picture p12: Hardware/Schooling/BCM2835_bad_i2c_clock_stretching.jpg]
RPiBadI2C R-Pi bad clock stretching


Clock-stretching at the end/directly after an I2C-read-ACK-phase only works correctly, if the slave stretches SCL by more than 0.5 I2C clock periods. 

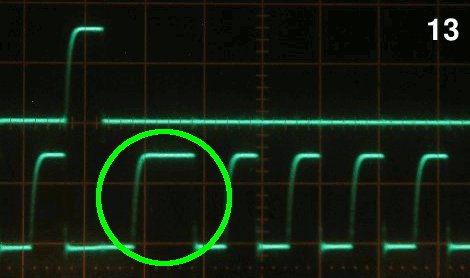
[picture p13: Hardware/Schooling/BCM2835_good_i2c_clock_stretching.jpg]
RPiGoodI2C R-Pi good clock stretching


http://www.advamation.com/knowhow/raspberrypi/rpi-i2c-bug.html

Linux notest:

https://git.kernel.org/pub/scm/linux/kernel/git/torvalds/linux.git/plain/Documentation/i2c/smbus-protocol

https://www.kernel.org/doc/Documentation/i2c/dev-interface

Some R-Pi notes:

https://www.raspberrypi.org/forums/viewtopic.php?f=44&t=15840&start=25

https://www.raspberrypi.org/forums/viewtopic.php?p=146272

Known bug?; the BCM2835 (e.g., R-Pi 0) picks up on a stretched clock only during the second half of the clock cycle. Hmm... so I could try a 10uSec delay in the receive event which is what causes clock stretching. I have an RPUno and RPUpi combination that seems to work over the SMBus, however after adding a delay in the slave events the working one has problems now. 

https://github.com/raspberrypi/firmware/issues/828

```
dtoverlay=i2c1-bcm2708,combine=no
```

```
sudo apt-get install python3-smbus i2c-tools
```

The package i2c-tools, for exampel "i2cdetect -r -y 1" can scan. Its man page is easy to read on the Linux machine but anyway.

https://git.kernel.org/pub/scm/utils/i2c-tools/i2c-tools.git/tree/tools/i2cdetect.8

```
     0  1  2  3  4  5  6  7  8  9  a  b  c  d  e  f
00:          -- -- -- -- -- -- -- -- -- -- -- -- --
10: -- -- -- -- -- -- -- -- -- -- -- -- -- -- -- --
20: -- -- -- -- -- -- -- -- -- -- 2a -- -- -- -- --
30: -- -- -- -- -- -- -- -- -- -- -- -- -- -- -- --
40: -- -- -- -- -- -- -- -- -- -- -- -- -- -- -- --
50: -- -- -- -- -- -- -- -- -- -- -- -- -- -- -- --
60: -- -- -- -- -- -- -- -- -- -- -- -- -- -- -- --
70: -- -- -- -- -- -- -- --
```

and "i2cdetect -F 1" will list of functionalities implemented by the adapter

```
I2C                              yes
SMBus Quick Command              yes
SMBus Send Byte                  yes
SMBus Receive Byte               yes
SMBus Write Byte                 yes
SMBus Read Byte                  yes
SMBus Write Word                 yes
SMBus Read Word                  yes
SMBus Process Call               yes
SMBus Block Write                yes
SMBus Block Read                 no
SMBus Block Process Call         no
SMBus PEC                        yes
I2C Block Write                  yes
I2C Block Read                   yes
```

The next man page I see has "i2cdump -V" and on my R-Pi zero it shows

https://git.kernel.org/pub/scm/utils/i2c-tools/i2c-tools.git/tree/tools/i2cdump.8

```
i2cdump version 3.1.2
```

But I don't see anything that looks like what I think SMBus_read_i2c_block_data does.  This "i2cdump 1 0x2a i" does not send a command byte.

The next man page I see is for "i2cget [-f] [-y] i2cbus chip-address [data-address [mode]]"

https://git.kernel.org/pub/scm/utils/i2c-tools/i2c-tools.git/tree/tools/i2cget.8

```
i2cget 1 0x2a 0x00
WARNING! This program can confuse your I2C bus, cause data loss and worse!
I will read from device file /dev/i2c-1, chip address 0x2a, data address
0x00, using read byte data.
Continue? [Y/n] Y
0x00
```

Another tool is i2ctransfer but it is not yet on the R-Pi.

https://git.kernel.org/pub/scm/utils/i2c-tools/i2c-tools.git/tree/tools/i2ctransfer.8

Also it does not do what I though SMBus_read_i2c_block_data does, sadness.

https://oscarliang.com/raspberry-pi-arduino-connected-i2c/

https://github.com/xmos/vocalfusion-rpi-setup/issues/13

Linux 4.19 will soon be the new OS, but it seems to have new or changed clock stretching problems with these BCM SoC. I need to try and do away with I2C clock stretching. I am going to try interleaving the buffer returned with the receive event, so the user will have to work with it befor the next receive event. The interleaving buffer will need to be added to the twi1.c lib file (e.g., a core file that is complex). While I was struggling with the SMBus, the Linux gurus are dealing with never-ending networking issues. 

https://news.ycombinator.com/item?id=20205566

How long before these updates are on the R-Pi? I don't know, but I do know that the R-Pi and Linux is not my product, and I will not provide support for them. The R-Pi will be the customer's computer, and they are responsible for keeping it up to data and making it work on their network if that sounds like attitude then sorry, guess I struggled with SMBus for too long.

## ^4 Bootload Speed

I have been using Optiboot at 115.2k bps but was not able to do that reliably with picocom (or any other serial). I think it was just on the edge of working with the 3172EIBZ at both ends, but placing the THVD1500 at one end adds to much delay so the THVD1500 and AVR UART clock at 111.1k bps is not able to work reliably with the 3172EIBZ and FTDI UART at 115.2k. 

Changing the AVR to 38.461k is a much better match to the FTDI's speed of 38.4k. I changed the speed for applications serial communication ages ago, and that has been reliable. Communication at 115.2k bps with picocom was getting the wrong values back so I have been confused for some time about the magic trick optiboot and avrdude were doing, I have dug through the source somewhat but did not see anything obvious so this is frankly comforting to see. 

Arduino's Uno is living on a bootload speed edge, I guess it works for them but I want a robust serial link for both communication and bootload. This will make my boards less compatible with Arduino's, but [MiniCore] can be used on there IDE and it has a 38.4k bps Optiboot. Now that I have seen this issue I will move my other boards to this speed also. Note that I am not using the Arduino IDE, the makefile is used in its place, it has the rules used to build the software so I can build the firmware remotely over an SSH login. 

[MiniCore]: https://github.com/MCUdude/MiniCore

## ^4 nSS to CE10 WTF

No no no... that is not what was tested, it was tested with nCE00 the RPUadpt test setup photo clearly shows it was nCE00. So I assembled one ^4 board and will rework it then finish testing.

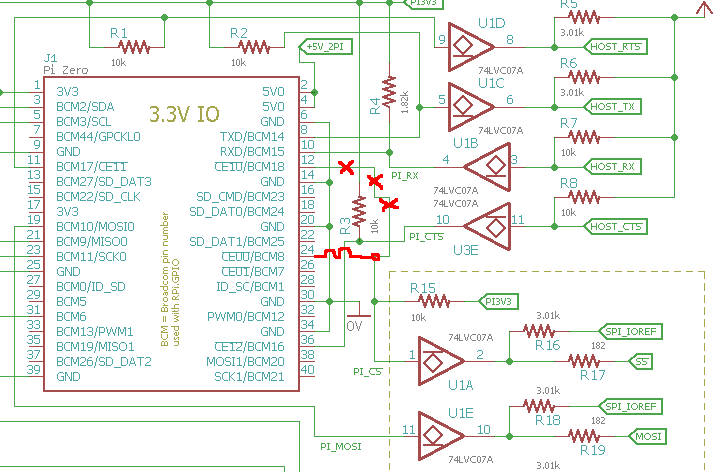
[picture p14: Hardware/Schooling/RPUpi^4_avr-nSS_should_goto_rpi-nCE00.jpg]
AVR-nSS To R-pi nCE00 RPUpi^4 AVR-nSS To R-pi nCE00


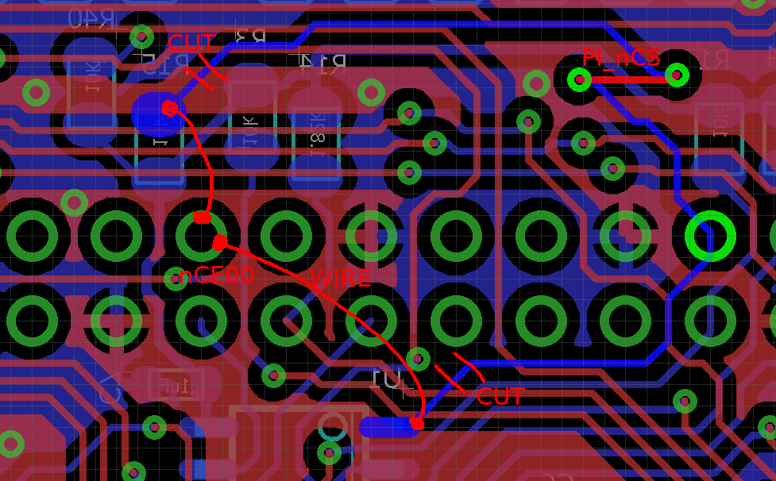
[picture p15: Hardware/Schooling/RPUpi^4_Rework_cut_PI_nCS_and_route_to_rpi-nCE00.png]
RPUpi^4 Rework PI_nCS


## ^3 Connect nSS to SBC CE10

When SPI uses chip enable it tells the slave to start a transaction, and the slave can align the data to the start.

This was tested with RPUadpt^6, and needs added to the next revision.

## ^2 Protect I2C With 182 Ohm

Add 182 Ohm in-line between shield pins and bus manager.

## ^2 RS-422 Buffer needs Power

When U3 (74LVC07) does not have power the serial RX and TX from shield can not reach RS-422 transceivers. 

For testing, I need to cut U3 power from the PI3V3 node and bridge it to +3V3 node.

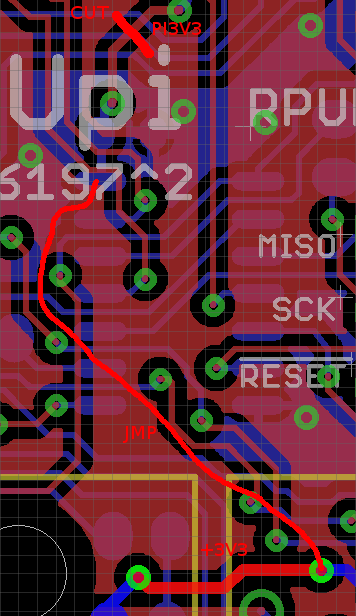
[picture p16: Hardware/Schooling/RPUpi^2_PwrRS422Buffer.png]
Power RS-422 Buffer


If U3E and U3F can be flipped with U1E and U1F that would also be helpful, U3B is fine as is.

## ^1 Serial When Powered Down

When the Pi is powered down the nRTS line, which is active low seems to become active. Also, HOST_TX pulls down and causes a bus lock-up. Finally nCTS, HOST_RX sinks too much current from the transceivers without some sort of protection when Pi is powered down.

 Another 74LVC07 with Pi as target is needed to fix all this.

## ^1 Pi Zero Placement

The Pi Zero fits but if it can be moved in that would be helpful. I think the SMPS can rotate and I can ditch the SWD port.

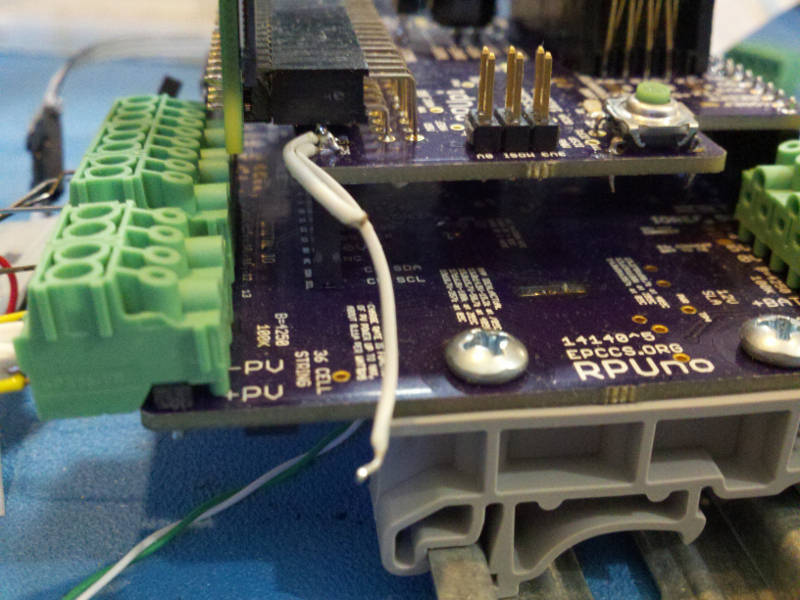
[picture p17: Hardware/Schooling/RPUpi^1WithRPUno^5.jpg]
Pi Zero Placement


## ^1 Target Should Power 74LVC07 

In this case the Pi is the target, and it should power the 74LVC07 buffer I used for level shifting. If the target is off it disables the IC (and the open drain is hi-z). If the target has 3.3V the IC is on and tolerant of 5V on its inputs. The outputs can be pulled up to 5V or 3.3V as needed. Also the inputs are tolerant of 5V when power is off.

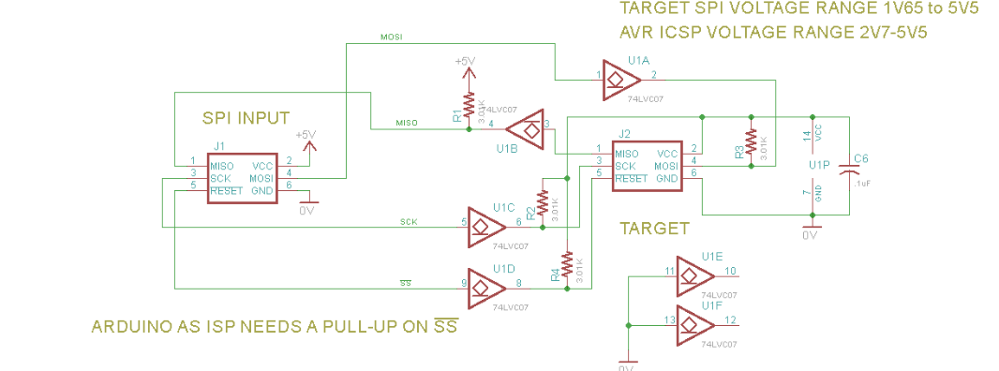
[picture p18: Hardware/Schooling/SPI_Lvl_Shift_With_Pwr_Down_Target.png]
SPI Level Shift SPI Level Shift With Power Down Target


Note: I am using the term target sort of like how I view ICSP, which is to say the thing that will get powered off. In this case oddly enough the bare metal  board (RPUno) will not power off, and is therefor not what I'm calling the target (I need to find a better way to say this...).

## ^1 Open SCK and MOSI

The 74LVC07 can damage the AVR by sinking current, therefore I need to open these traces and place a 10k Ohm resistor. This will allow the AVR to drive without causing damage when the 74LVC07's open drain output is sinking.

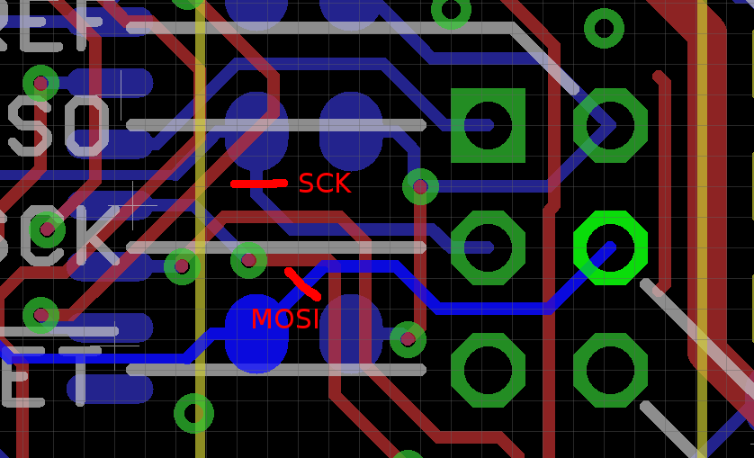
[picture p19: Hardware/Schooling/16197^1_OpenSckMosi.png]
Open SCK MOSI


Some nasty rework to add the 10k for more evaluation.

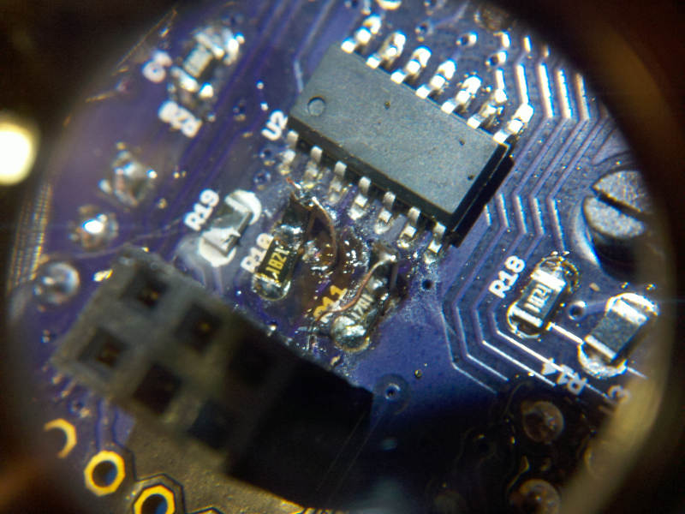
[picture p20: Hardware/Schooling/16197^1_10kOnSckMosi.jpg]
10k ON SCK MOSI


## ^1 Pi Tx Pull-Up

Add a 10k pull up to the Pi Zero Tx line. This will automatically disable the transceiver driver when the Pi is not powered or is absent.

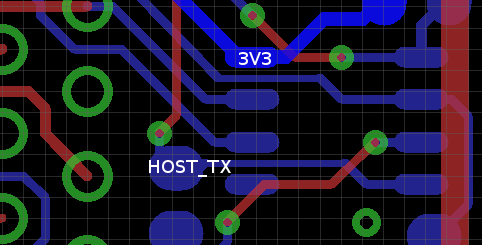
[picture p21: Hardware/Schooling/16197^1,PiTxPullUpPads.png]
Pi Tx Pull Up Pads

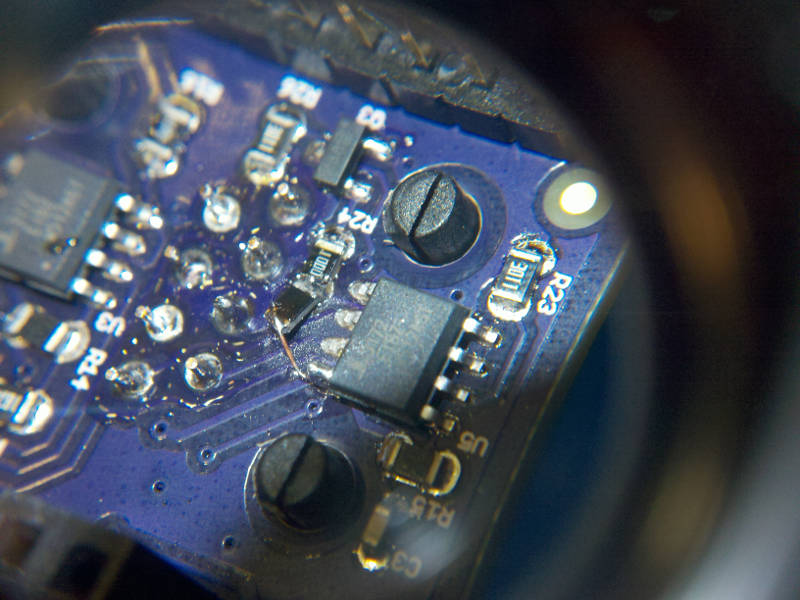
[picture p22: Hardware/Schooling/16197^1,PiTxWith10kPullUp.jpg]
Pi Tx With 10k Pull Up


## ^1 I2C

Cut I2C from Pi Zero and use a 1.8k pull-up to the bus manager 3V3. I am using I2C between the RPUno and bus manager to pass the rpu_bus address, I would prefer the RPUno programs work with an RPUpi shield without change. So the I2C from Pi to bus manager needs removed. Also when the RPUno kills power to the Pi that will pull down the I2C lines and block the bus manager from I2C communication with the RPUno.

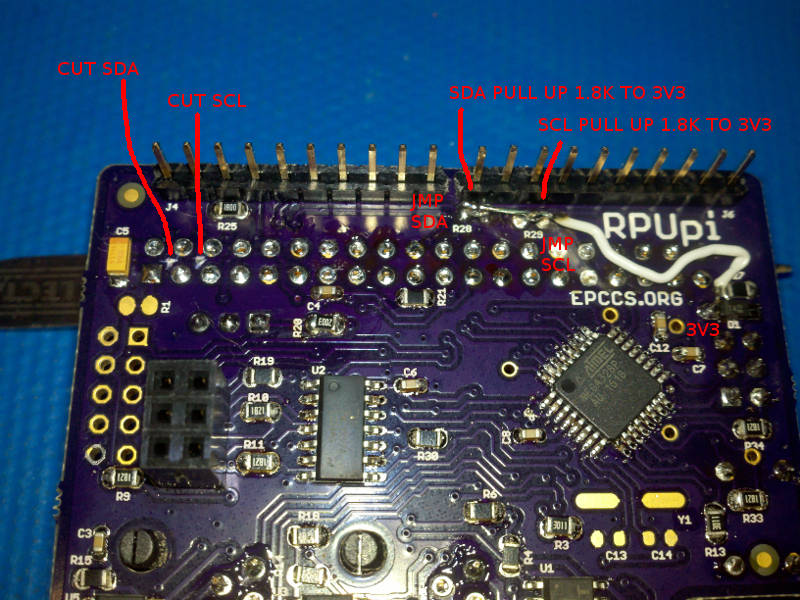
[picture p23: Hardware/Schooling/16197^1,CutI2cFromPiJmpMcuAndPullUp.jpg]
Cut I2C Cut I2C From Pi


## ^0 U3 Placed Backward

I though the via was my mark for pin one, need to fix the packages so this does not happen again.

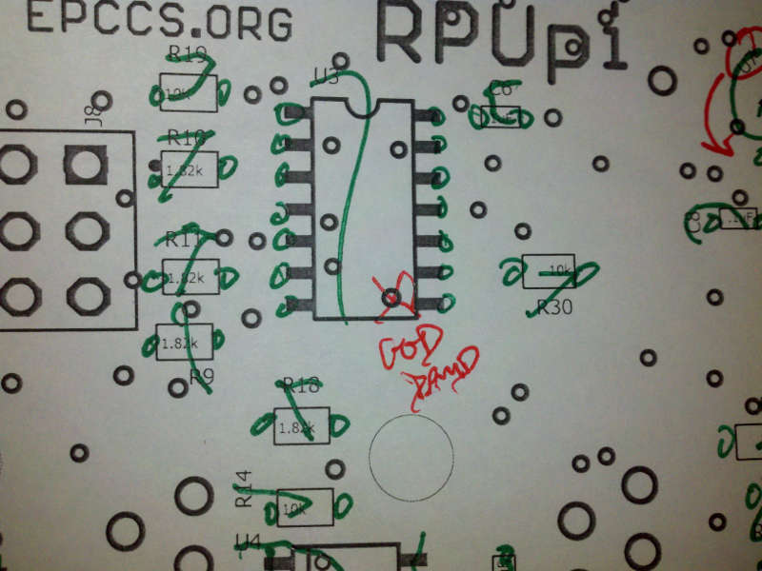
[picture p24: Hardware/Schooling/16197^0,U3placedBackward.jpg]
Via vs Pin Mark


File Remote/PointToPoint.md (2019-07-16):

# Point To Point Commands

16..31 (Ox10..0x1F | 0b00010000..0b00011111)

16. set arduino_mode 
17. read arduino_mode

## Cmd 16 from a controller /w i2c-debug set p2p mode

set arduino_mode so LOCKOUT_DELAY and BOOTLOADER_ACTIVE last forever when the host RTS toggles active. Arduino IDE can then make p2p connections to the bootload address.

``` 
picocom -b 38400 /dev/ttyUSB0
/1/iaddr 41
{"address":"0x29"}
/1/ibuff 16,1
{"txBuffer[2]":[{"data":"0x10"},{"data":"0x01"}]}
/1/iread? 2
{"rxBuffer":[{"data":"0x10"},{"data":"0x01"}]}
``` 

That was silly since i2c-debug will read the RPUbus address over I2C and cause the manager to send a normal mode (e.g., point to multi-point) on the DTR pair. 

## Cmd 16 from a Raspberry Pi set p2p mode

An R-Pi host can do it with SMBus, lets try with two RPUpi boards.

``` 
python3
import smbus
bus = smbus.SMBus(1)
#write_i2c_block_data(I2C_ADDR, I2C_COMMAND, DATA)
#read_i2c_block_data(I2C_ADDR, I2C_COMMAND, NUM_OF_BYTES)
# what is the bootload address
bus.write_i2c_block_data(42, 2, [255])
bus.read_i2c_block_data(42, 2, 2)
[2, 48]
# what is my address
bus.write_i2c_block_data(42, 0, [255])
bus.read_i2c_block_data(42, 0, 2)
[0, 50]
# set the bootload address to my address
bus.write_i2c_block_data(42, 3, [ord('2')])
bus.read_i2c_block_data(42, 3, 2)
[3, 50]
# clear the host lockout status bit so serial from this host can work
bus.write_i2c_block_data(42, 7, [0])
print(bus.read_i2c_block_data(42, 7, 2))
[7, 0]
exit()
# on an RPUno load the blinkLED application which does not read the bus address
git clone https://github.com/epccs/RPUno
cd /RPUno/BlinkLED
make
make bootload
# now back to 
python3
import smbus
bus = smbus.SMBus(1)
# and set the arduino_mode
bus.write_i2c_block_data(42, 16, [1])
print(bus.read_i2c_block_data(42, 16, 2))
[16, 1]
# the R-Pi host can now connect by serial so LOCKOUT_DELAY and BOOTLOADER_ACTIVE last forever
``` 

Now the R-Pi can connect to serial in P2P mode.

``` 
picocom -b 38400 /dev/ttyAMA0
``` 

At this time, the point to point mode persists, I will sort out more details when they are needed.

## Cmd 17 from a Raspberry Pi read p2p mode

An R-Pi host can use SMBus to check for p2p mode.

```
python3
import smbus
bus = smbus.SMBus(1)
#write_i2c_block_data(I2C_ADDR, I2C_COMMAND, DATA)
#read_i2c_block_data(I2C_ADDR, I2C_COMMAND, NUM_OF_BYTES)
# is it in p2p mode (a zero shows that the running app has read the rpubus address)
bus.write_i2c_block_data(42, 17, [255])
print(bus.read_i2c_block_data(42, 17, 2))
[65, 0]
```

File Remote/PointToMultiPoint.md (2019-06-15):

# Point To Multi-Point Commands

0..15 (Ox00..0xF | 0b00000000..0b00001111)

0. read the shields RPU_BUS address and activate normal mode (broadcast if localhost_active).
1. set the shields RPU_BUS address and write it to EEPROM.
2. read the address sent when RTS toggles active (e.g. the bootload address).
3. write the address that will be sent when RTS toggles active (e.g. the bootload address).
4. read RPUpi shutdown detected (it is from the ICP1 pin which has a weak pull-up to a momentary switch).
5. set RPUpi shutdown (pull down the ICP1 pin for SHUTDOWN_TIME to cause the host to halt, set shutdown detected).
6. reads status bits [0:DTR readback timeout, 1:twi transmit fail, 2:DTR readback not match, 3:host lockout].
7. writes (or clears) status.

## Cmd 0 from a controller /w i2c-debug read the shield address

The local RPU address can be read.

``` 
picocom -b 38400 /dev/ttyUSB0
/1/iaddr 41
{"address":"0x29"}
/1/ibuff 0,255
{"txBuffer[2]":[{"data":"0x0"},{"data":"0xFF"}]}
/1/iread? 2
{"rxBuffer":[{"data":"0x0"},{"data":"0x31"}]}
``` 

## Cmd 0 from a Raspberry Pi read the shield address

The host can read the local RPU_ADDRESS with the I2C1 port.

``` 
python3
import smbus
bus = smbus.SMBus(1)
#write_i2c_block_data(I2C_ADDR, I2C_COMMAND, DATA)
#read_i2c_block_data(I2C_ADDR, I2C_COMMAND, NUM_OF_BYTES)
bus.write_i2c_block_data(42, 0, [255])
print(bus.read_i2c_block_data(42, 0, 2))
[0, 49]
``` 

## Cmd 1 from a controller /w i2c-debug set RPU_BUS address

__Warning:__ this changes eeprom, flashing with ICSP does not clear eeprom due to fuse setting.

Using an RPUno and an RPUftdi shield, connect another RPUno with i2c-debug firmware to the RPUpi shield that needs its address set. The default RPU_BUS address can be changed from '1' to any other value. 

``` 
picocom -b 38400 /dev/ttyUSB0
/1/iaddr 41
{"address":"0x29"}
/1/ibuff 1,50
{"txBuffer[2]":[{"data":"0x1"},{"data":"0x32"}]}
/1/iread? 2
{"rxBuffer":[{"data":"0x1"},{"data":"0x32"}]}
``` 

The RPU program normally reads the address during setup in which case it needs a reset to get the update. The reset can be done by setting its bootload address (bellow).

```
/2/id?
{"id":{"name":"I2Cdebug^1","desc":"RPUno (14140^9) Board /w atmega328p","avr-gcc":"5.4.0"}}
``` 

## Cmd 2 from a controller /w i2c-debug read the address sent when DTR/RTS toggles

I2C0 can be used by the RPU to Read the local bootload address that it will send when a host connects to it.

``` 
picocom -b 38400 /dev/ttyUSB0
/1/iaddr 41
{"address":"0x29"}
/1/ibuff 2,255
{"txBuffer[2]":[{"data":"0x2"},{"data":"0xFF"}]}
/1/iread? 2
{"rxBuffer":[{"data":"0x2"},{"data":"0x30"}]}
``` 

Address 0x30 is ascii '0' so the RPU at that location will be reset and connected to the serial bus when a host connects to the shield at address '1'. 

## Cmd 2 from a Raspberry Pi read the address sent when DTR/RTS toggles

I2C1 can be used by the host to Read the local bootload address that it will send when a host connects to it.

``` 
python3
import smbus
bus = smbus.SMBus(1)
#write_i2c_block_data(I2C_ADDR, I2C_COMMAND, DATA)
#read_i2c_block_data(I2C_ADDR, I2C_COMMAND, NUM_OF_BYTES)
bus.write_i2c_block_data(42, 2, [255])
print(bus.read_i2c_block_data(42, 2, 2))
[2, 48]
``` 

Address 48 is 0x30 or ascii '0' so the RPU at that location will be reset and connected to the serial bus when the Raspberry Pi connects to the shield at this location (use command 1 to find the local address).

## Cmd 3 from a controller /w i2c-debug set the bootload address

__Note__: this valuse is not saved in eeprom so a power loss will set it back to '0'.

I2C0 can be used by the RPU to set the local bootload address that it will send when a host connects to it. When DTR/RTS toggles send ('2' is 0x32 is 50).

```
picocom -b 38400 /dev/ttyUSB0
/1/iaddr 41
{"address":"0x29"}
/1/ibuff 3,50
{"txBuffer[2]":[{"data":"0x3"},{"data":"0x32"}]}
/1/iread? 2
{"rxBuffer":[{"data":"0x3"},{"data":"0x32"}]}
``` 

exit picocom with C-a, C-x. 

Connect with picocom again. 

``` 
picocom -b 38400 /dev/ttyUSB0
``` 

This will toggle RTS on the RPUpi shield and the manager will send 0x32 on the DTR pair. The RPUpi shield should blink slow to indicate a lockout, while the shield with address '2' blinks fast to indicate bootloader mode. The lockout timeout LOCKOUT_DELAY can be adjusted in firmware.

## Cmd 3 from a Raspberry Pi set the bootload address

__Note__: this valuse is not saved in eeprom so a power loss will set it back to '0'.

I2C1 can be used by the host to set the local bootload address that it will send when a host connects to it. When DTR/RTS toggles send ('2' is 0x32 is 50).

``` 
python3
import smbus
bus = smbus.SMBus(1)
#write_i2c_block_data(I2C_ADDR, I2C_COMMAND, DATA)
#read_i2c_block_data(I2C_ADDR, I2C_COMMAND, NUM_OF_BYTES)
bus.write_i2c_block_data(42, 3, [50])
print(bus.read_i2c_block_data(42, 3, 2))
[3, 50]
``` 

## Cmd 4 from a controller /w i2c-debug read if HOST shutdown detected

To check if host got a manual hault command (e.g. if the shutdown button got pressed) send the I2C shutdown command 4 (first byte), with place holder data (second byte). This clears shutdown_detected flag that was used to keep the LED_BUILTIN from blinking.

``` 
picocom -b 38400 /dev/ttyUSB0
/1/iaddr 41
{"address":"0x29"}
/1/ibuff 4,255
{"txBuffer[2]":[{"data":"0x4"},{"data":"0xFF"}]}
/1/iread? 2
{"rxBuffer":[{"data":"0x4"},{"data":"0x1"}]}
/1/ibuff 4,255
{"txBuffer[2]":[{"data":"0x4"},{"data":"0xFF"}]}
/1/iread? 2
{"rxBuffer":[{"data":"0x4"},{"data":"0x0"}]}
``` 

The above used a remote host and shield.

Second value in rxBuffer has shutdown_detected value 0x1, it is cleared after reading.

## Cmd 5 from a controller /w i2c-debug set HOST to shutdown

To hault the host send the I2C shutdown command 5 (first byte), with data 1 (second byte) which sets shutdown_started, clears shutdown_detected and pulls down the SHUTDOWN (ICP1) pin. The shutdown_started flag is also used to stop blinking of the LED_BUILTIN to reduce power usage noise so that the host power usage can be clearly seen.

``` 
picocom -b 38400 /dev/ttyUSB0
/1/iaddr 41
{"address":"0x29"}
/1/ibuff 5,1
{"txBuffer[2]":[{"data":"0x5"},{"data":"0x1"}]}
/1/iread? 2
{"rxBuffer":[{"data":"0x5"},{"data":"0x1"}]}
``` 

The above used a remote host and shield.

## Cmd 6 from a controller /w i2c-debug read status bits

I2C0 can be used by the RPU to read the local status bits.

0. DTR readback timeout
1. twi transmit fail 
2. DTR readback not match
3. host lockout

``` 
picocom -b 38400 /dev/ttyUSB0
/1/iaddr 41
{"address":"0x29"}
/1/ibuff 6,255
{"txBuffer[2]":[{"data":"0x6"},{"data":"0xFF"}]}
/1/iread? 2
{"rxBuffer":[{"data":"0x6"},{"data":"0x8"}]}
``` 

## Cmd 6 from a Raspberry Pi read status bits

I2C1 can be used by the host to read the local status bits.

0. DTR readback timeout
1. twi transmit fail 
2. DTR readback not match
3. host lockout

``` 
python3
import smbus
bus = smbus.SMBus(1)
#write_i2c_block_data(I2C_ADDR, I2C_COMMAND, DATA)
#read_i2c_block_data(I2C_ADDR, I2C_COMMAND, NUM_OF_BYTES)
bus.write_i2c_block_data(42, 6, [255])
print(bus.read_i2c_block_data(42, 6, 2))
[6, 8]
``` 

Bit 3 is set so the host can not connect until that has been cleared.

## Cmd 7 from a controller /w i2c-debug set status bits

I2C0 can be used by the RPU to set the local status bits.

0. DTR readback timeout
1. twi transmit fail 
2. DTR readback not match
3. host lockout

``` 
picocom -b 38400 /dev/ttyUSB0
/1/iaddr 41
{"address":"0x29"}
/1/ibuff 7,8
{"txBuffer[2]":[{"data":"0x7"},{"data":"0x0"}]}
/1/iread? 2
{"rxBuffer":[{"data":"0x7"},{"data":"0x0"}]}
``` 

## Cmd 7 from a Raspberry Pi sets status bits

I2C1 can be used by the host to set the local status bits.

0. DTR readback timeout
1. twi transmit fail 
2. DTR readback not match
3. host lockout

``` 
python3
import smbus
bus = smbus.SMBus(1)
#write_i2c_block_data(I2C_ADDR, I2C_COMMAND, DATA)
#read_i2c_block_data(I2C_ADDR, I2C_COMMAND, NUM_OF_BYTES)
bus.write_i2c_block_data(42, 7, [0])
print(bus.read_i2c_block_data(42, 7, 2))
[7, 0]
exit()
picocom -b 38400 /dev/ttyAMA0
...
Terminal ready
/1/id?
# C-a, C-x.
``` 

The Raspberry Pi can bootload a target on the RPU serial bus.

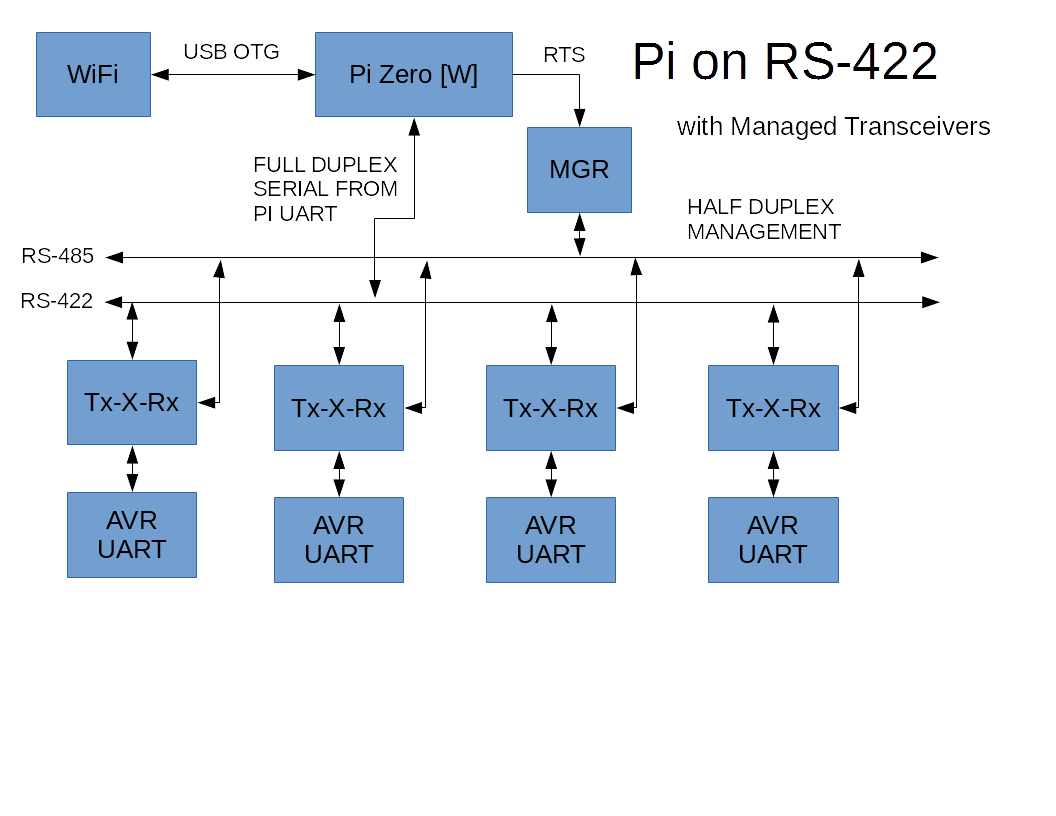
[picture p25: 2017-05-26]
Hardware/Documents/SimplifiedBlockDiag.png

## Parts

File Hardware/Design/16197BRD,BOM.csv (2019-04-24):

LINE | REF | QTY | TYP | PN | MFG@PN | DESCRIPTION | NOTES | COST EA | LINE COST | BIN
 |  |  |  |  |  | RPUpi Board |  |  | TOTAL
 |  |  |  |  |  | 4/8/19 (16197^5) |  |  | =SUM(J5:J100)
1 |  | =1/3 | BOARD | OSHPARK |  | PCB 2 LAYER ENIG 3 COPY | () | 25.20 | =C5*I5 | RPUPI
 |  |  |  |  |  | NOTES

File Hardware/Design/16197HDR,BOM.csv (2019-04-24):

LINE | REF | QTY | TYP | PN | MFG@PN | DESCRIPTION | NOTES | COST EA | LINE COST | BIN
 |  |  |  |  |  | RPUpi Headers |  |  | TOTAL
 |  |  |  |  |  | 4/8/19 (16197^5) |  |  | =SUM(J5:J100)
1 | D2 | 1 | D-LED | 5MMRD | CREE@C503B-RCN-CW0Z0AA1 | LED RED 5MM 2.1V@20MA | (1) | 0.129 | =C5*I5 | ONESHOT
2 | J2 J4 | 2 | J-RJ45 | RJ45J | WSW@A-2014-2-4-R | JACK MODULAR VERT PCB 8P8C UNSHIELD | (1) | 0.6164 | =C6*I6 | ADPT
3 | J3 J5 J6 | =3*10/36 | J-HDR2.54mm | PBC36SAAN | SULLINS@PBC36SAAN | HEADER MALE BRKWAY .1IN AA 36POS 3 SETS OF 10 | (1 4) | 2.091 | =C7*I7 | SHLD
4 | J7 | =1*8/36 | J-HDR2.54mm | PBC36SAAN | SULLINS2PBC36SAAN | HEADER MALE BRKWAY .1IN AA 36POS 1 SET OF 8 | (1 4) | 2.091 | =C8*I8 | SHLD
5 | J8 | 1 | J-HDR2.54mm | PPPC032LFBN | SULLINS@PPPC032LFBN-RC | CONN HEADER FEMALE .1IN 3X2POS | (1) | .5968 | =C9*I9 | RPUPI
6 | J9 | =1*3/36 | J-HDR2.54mm | PBC36DAAN | SULLINS@PBC36DAAN | CONN HEADER MALE BRKWAY .1IN AA 36X2POS 1 SET OF 3X2 | (1 4) | 3.774 | =C10*I10 | IRRIGATE7
7 | S1 | 1 | S-TACTILE | KSA0M311 | C&K@KSA0M311LFT | SWITCH TACTILE SEALED SPST-NO 50MA 32V THRU | (1) | 0.54 | =C11*I11 | RPUPI
 |  |  |  |  |  | NOTES
 |  |  |  |  |  | (1) Alternate part with same or better rating allowed
 |  |  |  |  |  | (4) Cut 36 pin to needed size

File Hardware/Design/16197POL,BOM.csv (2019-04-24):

LINE | REF | QTY | TYP | PN | MFG@PN | DESCRIPTION | NOTES | COST EA | LINE COST | BIN
 |  |  |  |  |  | RPUpi POL |  |  | TOTAL
 |  |  |  |  |  | 4/8/19 (16197^5) |  |  | =SUM(J5:J100)
1 | J1 | 1 | J-HDR2.54mm | PPPC202LJBN | SULLINS@PPPC202LJBN-RC | CONN HEADER FEMALE RIGHT ANGLE 20X2POS .1IN | (1) | 2.466 | =C5*I5 | RPUPI
2 | U5 | 1 | U-DCDC | I50115H | MURATA PS@OKI-78SR-5/1.5-W36-C | SMPS 5V 1500MA H SIP3 | (1) | 4.26 | =C6*I6 | RPUPI
 |  |  |  |  |  | NOTES
 |  |  |  |  |  | (1) Alternate part with same or better rating allowed
 |  |  |  |  |  | (4) Cut 36 pin to needed size

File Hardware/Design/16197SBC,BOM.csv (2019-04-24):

LINE | REF | QTY | TYP | PN | MFG@PN | DESCRIPTION | NOTES | COST EA | LINE COST | BIN
 |  |  |  |  |  | RPUpi SBC |  |  | TOTAL
 |  |  |  |  |  | 4/8/19 (16197^5) |  |  | =SUM(J5:J100)
1 |  | 1 |  | 3708 | ADAFRUIT@3708 | SBC BCM2835 512MB 40PIN PI ZERO WH | (4) | 14.0 | =C5*I5 | RPUPI
2 |  | 0 |  | 814 | ADAFRUIT@814 | USB WIFI FOR PI | (1) | 11.95 | =C6*I6 | RPUPI
3 |  | 0 |  | 1099 | ADAFRUIT@1099 | USB OTG HOST CABLE | (1) | 2.50 | =C7*I7 | RPUPI
4 |  | 0 |  | 3446 | ADAFRUIT@3446 | SBC CASE PI ZERO | (1) | 5.95 | =C8*I8 | RPUPI
 |  |  |  |  |  | NOTES
 |  |  |  |  |  | (1) parts may be needed with PI ZERO e.g. without WiFi
 |  |  |  |  |  | (4) ADAFRUIT@2885 without WiFi | ADAFRUIT@3400 with WiFi

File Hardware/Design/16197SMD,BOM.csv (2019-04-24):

LINE | REF | QTY | TYP | PN | MFG@PN | DESCRIPTION | NOTES | COST EA | LINE COST | BIN
 |  |  |  |  |  | RPUpi SMD |  |  | TOTAL
 |  |  |  |  |  | 4/8/19 (16197^5) |  |  | =SUM(J5:J100)
1 | C1 C2 C3 C4 C6 C7 C8 C9 C10 | 9 | C-C | 0603X7R50V104K | TDK@C1608X7R1H104K080AA | CAP CER 0.1UF 50V 10% X7R 0603 | (1) | 0.0055 | =C5*I5 | ADPT
2 | C5 | 1 | C-T | 106A | AVX@TPSA106K010R0900 | CAP TANT 10UF 10V 10% ESR .9OHM 1206 | (1) | 0.3575 | =C6*I6 | ADPT
3 | C11 C12 | 2 | C-C | 0603NPO50V270J | SAMSUNG@CL10C270JB8NNNC | CAP CER 27PF 50V 5% NPO 0603 | (1) | 0.0067 | =C7*I7 | RPUNO
4 | D1 | 1 | D-GP | T4 | DIODES@1N4148W-7-F | DIODE SWITCH 100V 0.15A SOD123 | (1) | 0.0601 | =C8*I8 | CC01
5 | Q1 Q2 Q3 | 3 | Q-NPN | K1N | DIODES@MMBT3904-7-F | TRANSISTOR NPN GP 40V 200MA SOT23 | (1) | 0.0204 | =C9*I9 | IRRIGATE7
6 | R1 R2 R3 R7 R8 R11 R15 R21 R22 R26 R33 R38 R40 | 13 | R-C | 0805KX1002 | YAGEO@RC0805FR-0710KL | RESISTOR CHIP 1% 10KOHM 0805 | (1) | 0.0025 | =C10*I10 | ADPT
7 | R4 R14 R25 R39 R41 | 5 | R-C | 0805KX1821 | YAGEO@RC0805FR-071K82L | RESISTOR CHIP 1% 1K82OHM 0805 | (1) | 0.0064 | =C11*I11 | RPUPI
8 | R5 R6 R9 R10 R16 R18 R20 R24 R27 R29 R32 R36 R37 | 13 | R-C | 0805KX3011 | YAGEO@RC0805FR-073K01L | RESISTOR CHIP 1% 3K01OHM 0805 | (1) | 0.0064 | =C12*I12 | ADPT
9 | R12 R23 R30 | 3 | R-C | 0805KX1003 | YAGEO@RC0805FR-07100KL | RESISTOR CHIP 1% 100KOHM 0805 | (1) | 0.0025 | =C13*I13 | IRRIGATE7
10 | R13 | 0 | R-C | OPEN |  |  | () | 0.0 | =C14*I14 | NA
11 | R17 R19 R28 R31 R34 R35 | 6 | R-C | 0805KX182R | YAGEO@RC0805FR-07182RL | RESISTOR CHIP 1% 182OHM 0805 | (1) | 0.0025 | =C15*I15 | IRRIGATE7
12 | U1 U3 | 2 | U-7400 | 74LVC07A | DIODES@74LVC07AS14-13 | LOGIC BUFFER OPEN DRAIN 14SOIC | (1) | 0.1978 | =C16*I16 | ADPT
13 | U2 U4 U6 | 3 | U-TRANSCEIVER | THVD1500 | TI@THVD1500DR | TRANSCEIVER RS485 5V HALFDPLX 8SOIC | (1) | 1.2567 | =C17*I17 | RPUPI
14 | U7 | 1 | U-AVR | ATMEGA328PB | ATMEL@ATMEGA328PB-AU | MCU AVR8 32KB FLASH 20MHZ 32TQFP | (1) | 1.27 | =C18*I18 | ADPT
15 | Y1 | 1 | Y-XTL | 12MHZ20 | ECS@ECS-120-20-3X-TR | CRYSTAL 12MHZ 20PF 30PPM CSM-3X | (1) | 0.315 | =C19*I19 | ADPT
 |  |  |  |  |  | NOTES
 |  |  |  |  |  | (1) Alternate part with same or better rating allowed

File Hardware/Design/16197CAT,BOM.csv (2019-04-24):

LINE | REF | QTY | TYP | PN | MFG@PN | DESCRIPTION | NOTES | COST EA | LINE COST | BIN
 |  |  |  |  |  | RPUpi CAT5 Term |  |  | TOTAL
 |  |  |  |  |  | 4/8/19 (16197^5) |  |  | =SUM(J5:J100)
1 |  | 3 | R-MF | 18FD100R | STACKPOLE@RNF18FTD100R | RES METAL FILM 1% 100ROHM | (1 4) | 0.0171 | =C5*I5 | ADPT
2 |  | 1 | J-RJ45 | RJ45P | WSW@A-MO 8/8 F50 | PLUG 8P8C | (1 4) | 0.2852 | =C6*I6 | ADPT
 |  |  |  |  |  | NOTES
 |  |  |  |  |  | (1) Alternate part with same or better rating allowed
 |  |  |  |  |  | (4) bus termination

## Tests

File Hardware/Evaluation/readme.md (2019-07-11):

# Description

This shows the setup and methods used for evaluation of RPUpi.

# Table of References

# Table Of Contents:

1. ^5 Test Mode Self-Test Style From RPUno
1. ^5 Test Mode
1. ^5 Point To Point Mode
1. ^4 I2C1 Checked With Raspberry Pi Zero
1. ^4 SPI 2MHz Checked With Raspberry Pi Zero
1. ^3 Life Test
1. ^3 SPI Interface
1. ^3 Power Data
1. ^3 Bootload Remote AVR
1. ^2 Clearance IDE Connector For ICSP Tool
1. ^2 Clearance Between Pi and Plugable
1. ^1 Vertical Mounting
1. ^0 Mounting

## ^5 Test Mode Self-Test Style From RPUno

If the RPUpi were to be integrated onto an RPUno, I would want it tested with a self-test.

https://github.com/epccs/RPUno/tree/master/XcvrTest

That was a lot of effort; the good news is that it should mostly copy to my other boards which I plan to gradually integrate this into (and then ditch all sorts of headers). The 40 pin R-Pi interface will be my path forward, I have grown comfortable with what the R-Pi foundation is doing. 

```
picocom -b 38400 /dev/ttyUSB0
picocom v2.2
...
Terminal ready
RPUpi Transceiver Test date: Jul 11 2019
avr-gcc --version: 5.4.0
I2C provided address 0x31 from manager
SMBUS cmd 0 provided address 49 from manager
MISO loopback to MOSI == HIGH
MISO loopback to MOSI == LOW
SCK with Shutdown loopback == HIGH
I2C Shutdown cmd is clean {5, 1}
SCK with Shutdown loopback == LOW
I2C Shutdown Detect cmd is clean {4, 1}

Testmode: default trancever control bits
I2C Start Test Mode cmd was clean {48, 1}
I2C End Test Mode hex is Xcvr cntl bits {49, 0xD5}
Testmode: read  Xcvr cntl bits {50, 0xE2}
PWR_I /w no load using INTERNAL_1V1: 0.024 A

Testmode: nCTS loopback to nRTS
I2C Start Test Mode cmd was clean {48, 1}
I2C End Test Mode hex is Xcvr cntl bits {49, 0xD5}
Testmode: set  Xcvr cntl bits {51, 0xA2}
Testmode: read  Xcvr cntl bits {50, 0x22}

Testmode: Enable TX pair driver
I2C Start Test Mode cmd was clean {48, 1}
I2C End Test Mode hex is Xcvr cntl bits {49, 0xD5}
Testmode: set  Xcvr cntl bits {51, 0xF2}
Testmode: read  Xcvr cntl bits {50, 0xF2}
PWR_I /w TX pair load: 0.044 A

Testmode: Enable TX & RX(loopback) pair drivers
I2C Start Test Mode cmd was clean {48, 1}
I2C End Test Mode hex is Xcvr cntl bits {49, 0xD5}
Testmode: set  Xcvr cntl bits {51, 0xD1}
Testmode: read  Xcvr cntl bits {50, 0xD1}
PWR_I /w TX and RX pairs loaded: 0.066 A
RX loopback checked

Testmode: Enable DTR pair driver
I2C Start Test Mode cmd was clean {48, 1}
I2C End Test Mode hex is Xcvr cntl bits {49, 0xD5}
Testmode: set  Xcvr cntl bits {51, 0xE6}
Testmode: read  Xcvr cntl bits {50, 0xE6}
PWR_I /w DTR pair load: 0.044 A
[PASS]
```

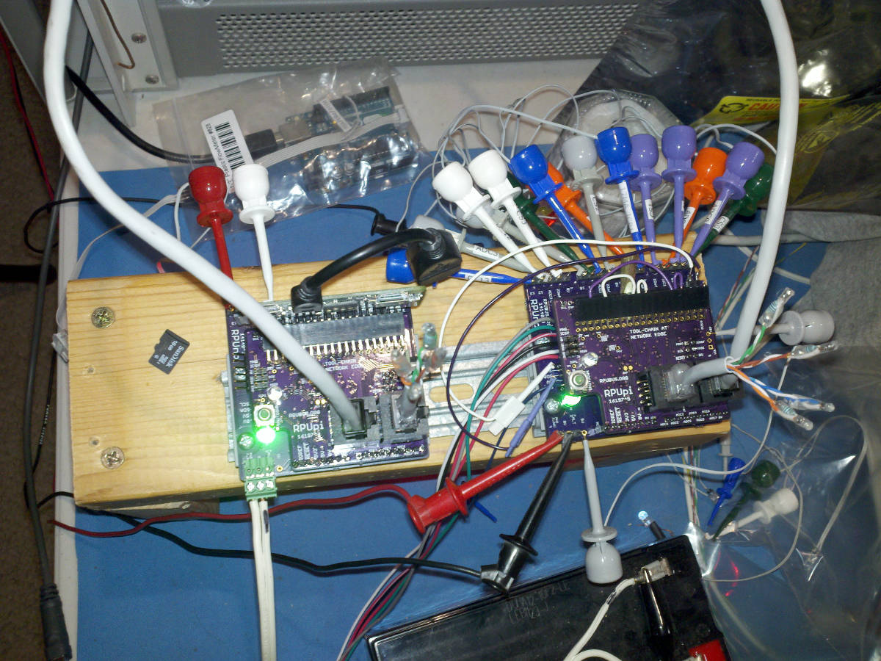
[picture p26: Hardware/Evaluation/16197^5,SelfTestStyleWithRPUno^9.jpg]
RPUpi^5 Self-Test Style RPUpi^5 Self-Test Style With RPUno^9


## ^5 Test Mode

The test mode commands from an RPUno's I2C running i2c-test

```
/1/iaddr 41
{"address":"0x29"}
/1/ibuff 48,1
{"txBuffer[2]":[{"data":"0x30"},{"data":"0x1"}]}
/1/iread? 2
{"rxBuffer":[{"data":"0x30"},{"data":"0x1"}]}
/1/ibuff 49,1
{"txBuffer[2]":[{"data":"0x31"},{"data":"0x1"}]}
/1/iread? 2
{"rxBuffer":[{"data":"0x31"},{"data":"0x15"}]}
/1/ibuff 48,1
{"txBuffer[2]":[{"data":"0x30"},{"data":"0x1"}]}
/1/iread? 2
{"rxBuffer":[{"data":"0x30"},{"data":"0x1"}]}
/1/ibuff 50,255
{"txBuffer[2]":[{"data":"0x32"},{"data":"0xFF"}]}
/1/iread? 2
{"rxBuffer":[{"data":"0x32"},{"data":"0x22"}]}
/1/ibuff 51,38
{"txBuffer[2]":[{"data":"0x33"},{"data":"0x26"}]}
/1/iread? 2
{"rxBuffer":[{"data":"0x33"},{"data":"0x26"}]}
```

The test mode commands from an RPUno's I2C running i2c-test on the SMBus interface.

```
/0/id?
{"id":{"name":"I2Cdebug^1","desc":"RPUno (14140^9) Board /w atmega328p","avr-gcc":"5.4.0"}}
/0/iscan?
{"scan":[{"addr":"0x2A"}]}
/0/iaddr 42
{"address":"0x2A"}
/0/ibuff 48,1
{"txBuffer[2]":[{"data":"0x30"},{"data":"0x1"}]}
/0/iwrite
{"returnCode":"success"}
/0/ibuff 48
{"txBuffer[1]":[{"data":"0x30"}]}
/0/iread? 2
{"rxBuffer":[{"data":"0x30"},{"data":"0x1"}]}
/0/ibuff 49,1
{"txBuffer[2]":[{"data":"0x31"},{"data":"0x1"}]}
/0/iwrite
{"returnCode":"success"}
/0/ibuff 49
{"txBuffer[1]":[{"data":"0x31"}]}
/0/iread? 2
{"rxBuffer":[{"data":"0x31"},{"data":"0x15"}]}
/0/ibuff 48,1
{"txBuffer[2]":[{"data":"0x30"},{"data":"0x1"}]}
/0/iwrite
{"returnCode":"success"}
/0/ibuff 48
{"txBuffer[1]":[{"data":"0x30"}]}
/0/iread? 2
{"rxBuffer":[{"data":"0x30"},{"data":"0x1"}]}
/0/ibuff 50,255
{"txBuffer[2]":[{"data":"0x32"},{"data":"0xFF"}]}
/0/iwrite
{"returnCode":"success"}
/0/ibuff 50
{"txBuffer[1]":[{"data":"0x32"}]}
/0/iread? 2
{"rxBuffer":[{"data":"0x32"},{"data":"0x22"}]}
/0/ibuff 51,38
{"txBuffer[2]":[{"data":"0x33"},{"data":"0x26"}]}
/0/iwrite
{"returnCode":"success"}
/0/ibuff 51
{"txBuffer[1]":[{"data":"0x33"}]}
/0/iread? 2
{"rxBuffer":[{"data":"0x33"},{"data":"0x26"}]}
```

The SMBus test mode commands from a R-Pi Zero mounted on the RPUpi itself.

```
>>> import smbus
>>> bus = smbus.SMBus(1)
>>> bus.write_i2c_block_data(42, 0, [255])
>>> bus.read_i2c_block_data(42, 0, 2)
[0, 50]
>>> bus.write_i2c_block_data(42, 48, [1])
>>> print(bus.read_i2c_block_data(42, 48, 2))
[48, 1]
>>> bus.write_i2c_block_data(42, 49, [1])
>>> print(bus.read_i2c_block_data(42, 49, 2))
[49, 21]
>>> bus.write_i2c_block_data(42, 48, [1])
>>> print(bus.read_i2c_block_data(42, 48, 2))
[48, 1]
>>> bus.write_i2c_block_data(42, 50, [255])
>>> print(bus.read_i2c_block_data(42, 50, 2))
[50, 34]
>>> bus.write_i2c_block_data(42, 51, [38])
>>> print(bus.read_i2c_block_data(42, 51, 2))
[51, 38]
>>> bus.write_i2c_block_data(42, 49, [1])
>>> print(bus.read_i2c_block_data(42, 49, 2))
[49, 21]
>>> exit()
```

## ^5 Point To Point Mode

An arduino_mode so LOCKOUT_DELAY and BOOTLOADER_ACTIVE last forever when the host RTS toggles active. At this time an R-Pi is needed.

``` 
python3
import smbus
bus = smbus.SMBus(1)
#write_i2c_block_data(I2C_ADDR, I2C_COMMAND, DATA)
#read_i2c_block_data(I2C_ADDR, OFFSET, NUM_OF_BYTES)
# OFFSET is not implemented
# what is the bootload address
bus.write_i2c_block_data(42, 2, [255])
print("'"+chr(bus.read_i2c_block_data(42, 0, 2)[1])+"'" )
'0'
# what is my address
bus.write_i2c_block_data(42, 0, [255])
print("'"+chr(bus.read_i2c_block_data(42, 0, 2)[1])+"'" )
'2'
# set the bootload address to my address
bus.write_i2c_block_data(42, 3, [ord('2')])
print("'"+chr(bus.read_i2c_block_data(42, 0, 2)[1])+"'" )
'2'
# clear the host lockout status bit so serial from this host can work
bus.write_i2c_block_data(42, 7, [0])
print(bus.read_i2c_block_data(42,0, 2))
[7, 0]
exit()
# on an RPUno load the blinkLED application which does not read the bus address
git clone https://github.com/epccs/RPUno
cd /RPUno/BlinkLED
make
make bootload
# now back to 
python3
import smbus
bus = smbus.SMBus(1)
# and set the arduino_mode
bus.write_i2c_block_data(42, 64, [1])
print(bus.read_i2c_block_data(42, 0, 2))
[64, 1]
# the R-Pi host can now connect by serial so LOCKOUT_DELAY and BOOTLOADER_ACTIVE last forever
``` 

Now the R-Pi can connect to serial in P2P mode.

``` 
picocom -b 38400 /dev/ttyAMA0
``` 

## ^4 I2C1 Checked With Raspberry Pi Zero

Scan the smbus (I2C1) with Raspberry Pi.

```
sudo apt-get install i2c-tools python3-smbus
sudo usermod -a -G i2c rsutherland
# logout for the change to take
i2cdetect 1
WARNING! This program can confuse your I2C bus, cause data loss and worse!
I will probe file /dev/i2c-1.
I will probe address range 0x03-0x77.
Continue? [Y/n] Y
     0  1  2  3  4  5  6  7  8  9  a  b  c  d  e  f
00:          -- -- -- -- -- -- -- -- -- -- -- -- --
10: -- -- -- -- -- -- -- -- -- -- -- -- -- -- -- --
20: -- -- -- -- -- -- -- -- -- -- 2a -- -- -- -- --
30: -- -- -- -- -- -- -- -- -- -- -- -- -- -- -- --
40: -- -- -- -- -- -- -- -- -- -- -- -- -- -- -- --
50: -- -- -- -- -- -- -- -- -- -- -- -- -- -- -- --
60: -- -- -- -- -- -- -- -- -- -- -- -- -- -- -- --
70: -- -- -- -- -- -- -- --
```

The [Remote] firmware has the host (Raspberry Pi Zero) locked out from using the serial connection, but with I2C1 it can be enabled. One of the status bits is for host lockout. The SMBus command 7 is used to set that status bit.

[Remote]: https://github.com/epccs/RPUpi/tree/master/Remote

``` 
python3
import smbus
bus = smbus.SMBus(1)
# use SMBus command 0 to show the local address 
#write_i2c_block_data(I2C_ADDR, I2C_COMMAND, DATA)
bus.write_i2c_block_data(42, 0, [0])
#read_i2c_block_data(I2C_ADDR, OFFSET, NUM_OF_BYTES)
#OFFSET is not implemented
chr(bus.read_i2c_block_data(42,0, 2)[1])
'1'
# use SMBus command 2 to show the bootload address 
bus.write_i2c_block_data(42, 2, [0])
chr(bus.read_i2c_block_data(42,0, 2)[1])
'0'
# use SMBus command 3 to change the bootload address (49 is ascii '1')
bus.write_i2c_block_data(42, 3, [49])
chr(bus.read_i2c_block_data(42,0, 2)[1])
'1'
# use SMBus command 7 to clear the lockout bit in the status bits that was set at power up.
bus.write_i2c_block_data(42, 7, [0])
print(bus.read_i2c_block_data(42,0, 2))
[7, 0]
exit()
picocom -b 38400 /dev/ttyAMA0
...
Terminal ready
/1/id?
# C-a, C-x.
``` 

Once the host lockout is clear the Raspberry Pi can bootload the address set with command 3 (see [Remote]). The Raspberry Pi will need to use its [RTS] handshack lines for avrdude to work.

[RTS]: https://github.com/epccs/RPUpi/tree/master/RPiRtsCts

## ^4 SPI 2MHz Checked With Raspberry Pi Zero

Note: AVR's nSS that went to Pi's nCE10 was changed to nCE00 for this test, it needs to be fixed on next board version.

The unit under test is at address '1'. So first I need to bootload its controller (an RPUno^9) with [SpiSlv].

[SpiSlv]:https://github.com/epccs/RPUno/tree/master/SpiSlv

To do that I set the booload address on the shield that is connected to the host which will build [SpiSlv] and upload the firmware. 

``` 
# first set user premision to use the SPI port
sudo usermod -a -G spi rsutherland
# logout for the change to take
# Write the address '1' (0x31) that will be sent when nRTS enables.
# Next clear the lockout bit to alow the Pi Zero to use the RPUBUS as a host (e.g. from the Pi Zero in sneaky mode)
picocom -b 38400 /dev/ttyAMA0
...
Terminal ready
/1/iaddr 41
{"address":"0x29"}
/1/ibuff 3,49
{"txBuffer[2]":[{"data":"0x3"},{"data":"0x31"}]}
/1/iread? 2
{"rxBuffer":[{"data":"0x3"},{"data":"0x31"}]}
/1/ibuff 7,0
{"txBuffer[2]":[{"data":"0x7"},{"data":"0x0"}]}
/1/iread? 2
# ASCII character glitch may show now since the local controller has just reset
# C-a, C-x.

# next check that RPU '1' is blinking fast
picocom -b 38400 /dev/ttyAMA0
...
Terminal ready
# C-a, C-x.

# now change the working directory to where SpiSlv is and then build and upload
cd ~/wher_you_told_git_to_clone/RPUno/SpiSlv
make bootload
...
avrdude done.  Thank you.

# 
gcc -o spidev_test spidev_test.c
chmod ugo+x ./spidev_test
# trun on the RPU SPI port
picocom -b 38400 /dev/ttyAMA0
...
Terminal ready
/1/id?
{"id":{"name":"SpiSlv","desc":"RPUno (14140^9) Board /w atmega328p","avr-gcc":"5.4.0"}}
/1/spi UP
{"SPI":"UP"}
# C-a, C-x.
# test with
./spidev_test -s 1000 -D /dev/spidev0.0
./spidev_test -s 10000 -D /dev/spidev0.0
./spidev_test -s 100000 -D /dev/spidev0.0
./spidev_test -s 250000 -D /dev/spidev0.0
./spidev_test -s 500000 -D /dev/spidev0.0
./spidev_test -s 1000000 -D /dev/spidev0.0
./spidev_test -s 2000000 -D /dev/spidev0.0
# 4MHz fails on this RPUpi^4 setup with nCE10 swaped to nCE00.
```

The test output should look like this

```
spi mode: 0
bits per word: 8
max speed: 500000 Hz (500 KHz)

0D FF FF FF FF FF
FF 40 00 00 00 00
95 FF FF FF FF FF
FF FF FF FF FF FF
FF FF FF FF FF FF
FF DE AD BE EF BA
AD F0
``` 

The maximum speed seen is 2MegHz.

## ^3 Life Test

A Pi Zero has been in operation on a RPUlux from April 2018 to March 2019. 

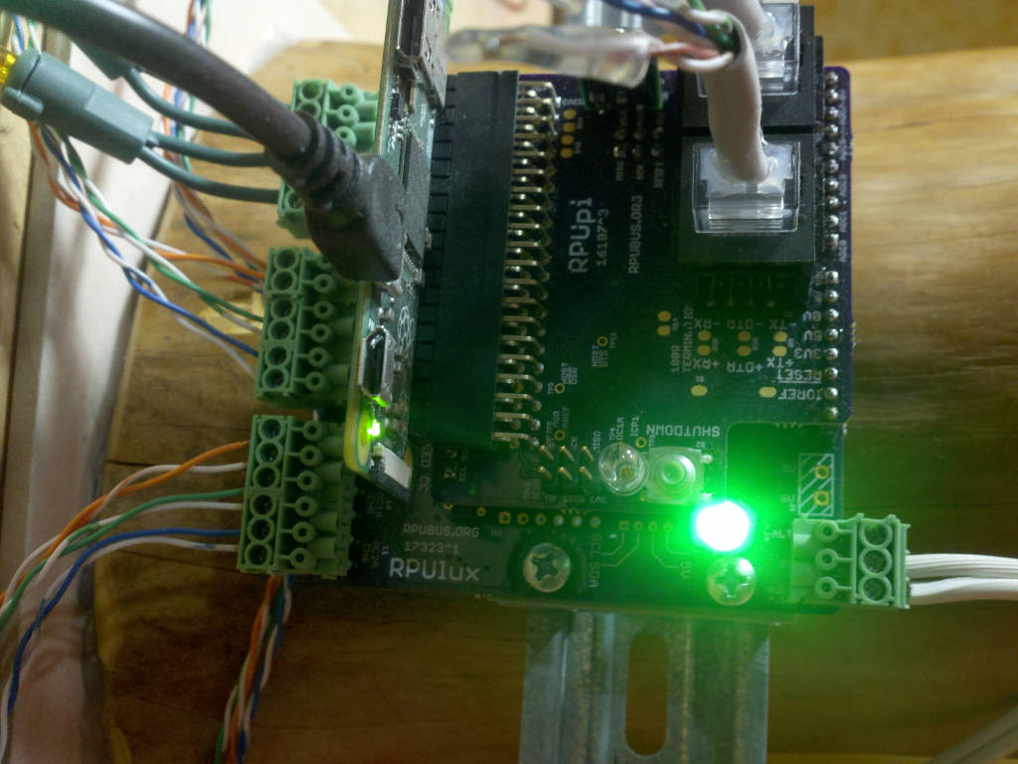
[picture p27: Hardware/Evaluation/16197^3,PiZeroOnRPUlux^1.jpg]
RPUpi^3 with Zero on RPUlux


An SD card failed after an OS update in June 2018 but it was replaced and has operated fine since. The card was a PNY 16GB Prime microSD with marking C10 and A0577 (PN:P-SDU16GU160G-GE)

https://www.newegg.com/Product/Product.aspx?Item=9SIAJ628HH6760

It was a low cost SD card.

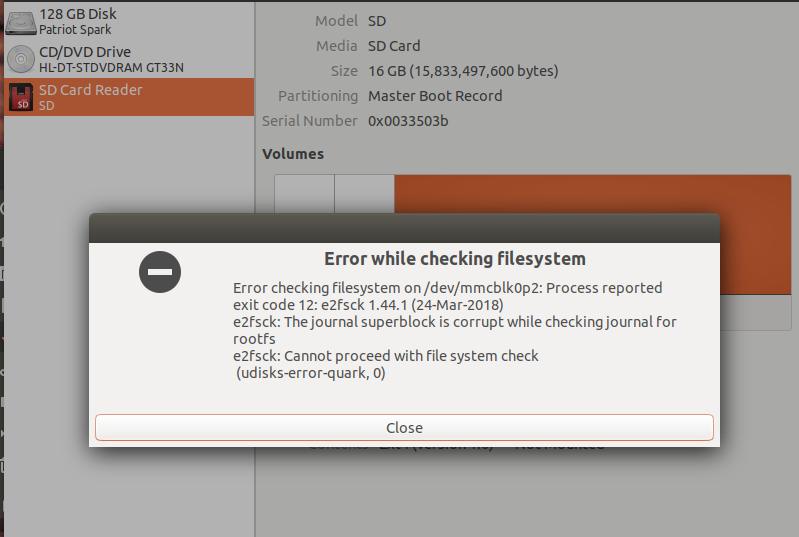
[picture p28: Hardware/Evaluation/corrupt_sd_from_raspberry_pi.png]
Corrupt SD


There are industrially rated SD cards if needed, but as a rule, don't use the single board computer to keep important data. Figure out a way to push the data into a reliable data storage system. Another option may be to use redundant SBC and keep the data on them synchronizing.

## ^3 SPI Interface

Firmware [SpiSlv] is used to enable the SPI port on a RPUno (ATmega328p).

[SpiSlv]: https://github.com/epccs/RPUno/tree/master/SpiSlv

After loading the firmware on an RPUno and enabling the AVR's SPI I next need the Raspberry Pi [SPI] hardware setup. Raspian needs its interface master driver enabled (e.g. [raspi-config]).

[SPI]: https://www.raspberrypi.org/documentation/hardware/raspberrypi/spi/README.md
[raspi-config]: https://www.raspberrypi.org/documentation/configuration/raspi-config.md

Raspibin has an spi group setup in /etc/udev/rules.d/99-com.rules. So I can add my user name to that group for the system to allow me to use the interface.

``` 
sudo usermod -a -G spi rsutherland
# logout for the change to take
``` 

Next I compile and run spidev_test.c on the Pi with:

``` 
wget https://raw.githubusercontent.com/raspberrypi/linux/rpi-3.10.y/Documentation/spi/spidev_test.c
gcc -o spidev_test spidev_test.c
# run with
./spidev_test -s 100000 -D /dev/spidev0.0
./spidev_test -s 500000 -D /dev/spidev0.0
./spidev_test -s 1000000 -D /dev/spidev0.0
./spidev_test -s 2000000 -D /dev/spidev0.0

spi mode: 0
bits per word: 8
max speed: 500000 Hz (500 KHz)

0D FF FF FF FF FF
FF 40 00 00 00 00
95 FF FF FF FF FF
FF FF FF FF FF FF
FF FF FF FF FF FF
FF DE AD BE EF BA
AD F0
``` 

Note: The output is offset a byte since it was sent back from the AVR. I see errors at 1MHz and 2MHz. The RPUpi^3 has a 74LVC07 buffer that pulls down through a 10kOhm resistor on SCK and MOSI. The circuit between that resistor and the AVR has some capacitance which will limit the speed (if there is a need for higher speed it may be possible to swap in a 1k resistor).

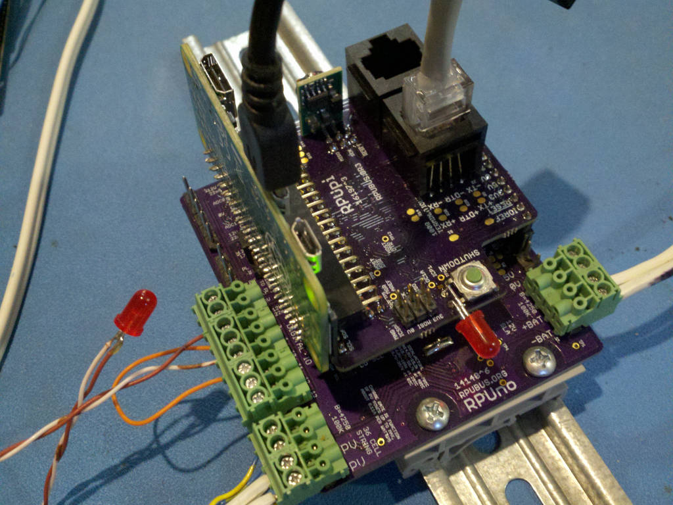
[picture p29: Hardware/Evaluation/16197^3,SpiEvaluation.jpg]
SPI Evaluation


## ^3 Power Data

PV input to RPUno is at 200mA in Constant Current mode

```
/1/analog? 7,6,3,2
{"PWR_V":"14.15","PV_V":"16.88","DISCHRG_A":"0.003","CHRG_A":"0.024"}
{"PWR_V":"14.15","PV_V":"16.88","DISCHRG_A":"0.000","CHRG_A":"0.052"}
{"PWR_V":"14.15","PV_V":"16.85","DISCHRG_A":"0.000","CHRG_A":"0.036"}
{"PWR_V":"14.15","PV_V":"16.83","DISCHRG_A":"0.000","CHRG_A":"0.030"}
{"PWR_V":"14.15","PV_V":"16.93","DISCHRG_A":"0.000","CHRG_A":"0.030"}
{"PWR_V":"14.15","PV_V":"16.85","DISCHRG_A":"0.000","CHRG_A":"0.039"}
{"PWR_V":"14.10","PV_V":"16.93","DISCHRG_A":"0.000","CHRG_A":"0.062"}
{"PWR_V":"14.16","PV_V":"16.83","DISCHRG_A":"0.000","CHRG_A":"0.080"}
{"PWR_V":"14.15","PV_V":"16.88","DISCHRG_A":"0.000","CHRG_A":"0.066"}
{"PWR_V":"14.15","PV_V":"16.88","DISCHRG_A":"0.000","CHRG_A":"0.014"}
```

Readings were taken every 30 seconds, this should give an idea how the Pi Zero power usage fluctuates.

PV to RPUno is now turned off so all power is from the 12 SLA Battery (18Ahr AGM). Note 20mA is used on some status LED's controlled by DIO 4 and DIO 13. 

```
/1/analog? 7,6,3,2
{"PWR_V":"13.91","PV_V":"0.16","DISCHRG_A":"0.142","CHRG_A":"0.000"}
{"PWR_V":"13.78","PV_V":"0.36","DISCHRG_A":"0.123","CHRG_A":"0.000"}
{"PWR_V":"13.69","PV_V":"0.34","DISCHRG_A":"0.122","CHRG_A":"0.000"}
{"PWR_V":"13.68","PV_V":"0.29","DISCHRG_A":"0.154","CHRG_A":"0.000"}
{"PWR_V":"13.62","PV_V":"0.31","DISCHRG_A":"0.162","CHRG_A":"0.000"}
{"PWR_V":"13.58","PV_V":"0.31","DISCHRG_A":"0.156","CHRG_A":"0.000"}
{"PWR_V":"13.53","PV_V":"0.31","DISCHRG_A":"0.175","CHRG_A":"0.000"}
{"PWR_V":"13.49","PV_V":"0.31","DISCHRG_A":"0.154","CHRG_A":"0.000"}
{"PWR_V":"13.44","PV_V":"0.34","DISCHRG_A":"0.136","CHRG_A":"0.000"}
```

Readings were taken every 30 seconds.

The [PwrMgt] firmware running on the board under RPUpi can show how many mAHr is used from the battery.

[PwrMgt]: https://github.com/epccs/RPUno/tree/master/PwrMgt

```
/1/charge?
{"CHRG_mAHr":"316.96","DCHRG_mAHr":"19.99","RMNG_mAHr":"0.00","ACCUM_Sec":"14884.78"}
{"CHRG_mAHr":"316.96","DCHRG_mAHr":"21.86","RMNG_mAHr":"0.00","ACCUM_Sec":"14944.78"}
{"CHRG_mAHr":"316.96","DCHRG_mAHr":"23.73","RMNG_mAHr":"0.00","ACCUM_Sec":"15004.78"}
{"CHRG_mAHr":"316.96","DCHRG_mAHr":"25.61","RMNG_mAHr":"0.00","ACCUM_Sec":"15064.78"}
{"CHRG_mAHr":"316.96","DCHRG_mAHr":"27.49","RMNG_mAHr":"0.00","ACCUM_Sec":"15124.78"}
# I ran this befor going out to do some work in the garden, but this is a far as it got.
# Did the AVR mcu reset? 
# The mcu seems to have lost the CHRG mAHr thought the ssh connection never broke
# I bet this has to do with the Night_AttachWork callback that is not implemented 
/1/charge?
{"CHRG_mAHr":"0.00","DCHRG_mAHr":"549.85","RMNG_mAHr":"0.00","ACCUM_Sec":"16483.48"}
{"CHRG_mAHr":"0.00","DCHRG_mAHr":"551.86","RMNG_mAHr":"0.00","ACCUM_Sec":"16543.48"}
{"CHRG_mAHr":"0.00","DCHRG_mAHr":"553.86","RMNG_mAHr":"0.00","ACCUM_Sec":"16603.48"}
{"CHRG_mAHr":"0.00","DCHRG_mAHr":"555.87","RMNG_mAHr":"0.00","ACCUM_Sec":"16663.48"}
{"CHRG_mAHr":"0.00","DCHRG_mAHr":"557.88","RMNG_mAHr":"0.00","ACCUM_Sec":"16723.48"}
{"CHRG_mAHr":"0.00","DCHRG_mAHr":"559.88","RMNG_mAHr":"0.00","ACCUM_Sec":"16783.48"}
{"CHRG_mAHr":"0.00","DCHRG_mAHr":"561.89","RMNG_mAHr":"0.00","ACCUM_Sec":"16843.48"}
{"CHRG_mAHr":"0.00","DCHRG_mAHr":"563.89","RMNG_mAHr":"0.00","ACCUM_Sec":"16903.48"}
{"CHRG_mAHr":"0.00","DCHRG_mAHr":"565.90","RMNG_mAHr":"0.00","ACCUM_Sec":"16963.48"}
{"CHRG_mAHr":"0.00","DCHRG_mAHr":"567.90","RMNG_mAHr":"0.00","ACCUM_Sec":"17023.48"}
{"CHRG_mAHr":"0.00","DCHRG_mAHr":"569.91","RMNG_mAHr":"0.00","ACCUM_Sec":"17083.48"}
{"CHRG_mAHr":"0.00","DCHRG_mAHr":"571.91","RMNG_mAHr":"0.00","ACCUM_Sec":"17143.48"}
{"CHRG_mAHr":"0.00","DCHRG_mAHr":"573.92","RMNG_mAHr":"0.00","ACCUM_Sec":"17203.48"}
{"CHRG_mAHr":"0.00","DCHRG_mAHr":"575.93","RMNG_mAHr":"0.00","ACCUM_Sec":"17263.48"}
/1/analog? 7,6,3,2
{"PWR_V":"12.92","PV_V":"0.31","DISCHRG_A":"0.152","CHRG_A":"0.000"}
```

Charge readings were taken every 60 seconds. The ACCUM Sec is about 4.8 Hr during which it used .6 AHr. That is more power than I would like it to use, but it seems reasonable based on the static current readings. The best charge I've seen so far is about .3AHr per day for a Watt of PV so this is saying I need a minim of 10 Watt of PV to run the Pi, and it needs to always be the best day for charging that I've seen the data for.

These were all done over SSH and WiFi (ohterwise the Pi had no load)

```
sudo iwlist wlan0 scan
TBD
```
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

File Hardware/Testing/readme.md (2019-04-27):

# Description

This is a list of Test preformed on each RPUpi after assembly.

# Table of References

# Table Of Contents:

1. Basics
2. Assembly check
3. IC Solder Test
4. Bias +5V
5. Set MCU Fuse
6. Load CheckDTR Firmware
7. Check Differential Bias
8. Differential Loopback with TX Driver
9. Differential Loopback with RX Driver
10. Bias VIN and Check +5V_2PI from SMPS
11. Host Lockout
12. Pi Zero without SD card
13. Boot Headless Pi Zero
14. SPI 

## Basics

These tests are for an assembled RPUpi board 16197^4 which may be referred to as a Unit Under Test (UUT). If the UUT fails and can be reworked then do so, otherwise it needs to be scraped. 

**Warning: never use a soldering iron to rework ceramic capacitors due to the thermal shock.**
    
Items used for test.

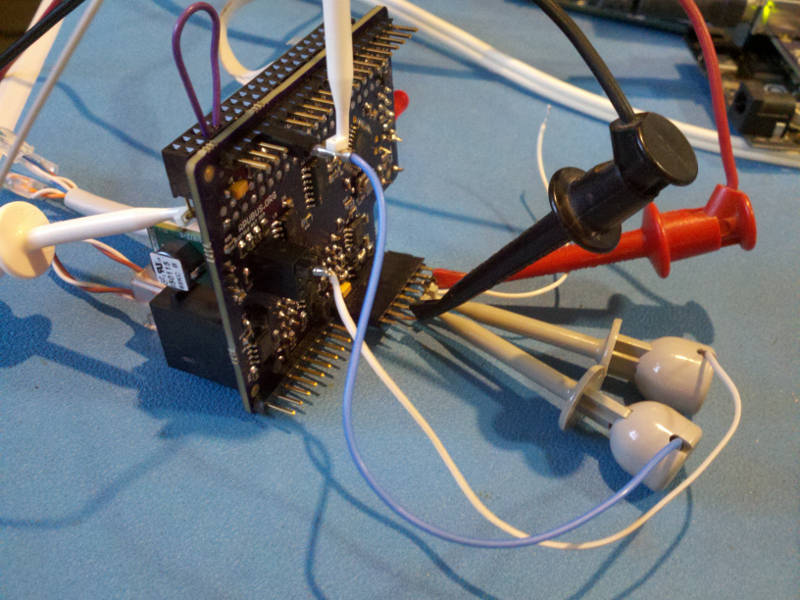
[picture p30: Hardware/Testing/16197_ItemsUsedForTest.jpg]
ItemsUsedForTest RPUpi Items Used For Test


## Assembly check

After assembly check the circuit carefully to make sure all parts are soldered and correct. The device marking is used as the part name on the schematic and assembly drawing. Check the bill of materials to figure out what the device is.

## IC Solder Test

Check continuity between pin and pad by measuring the reverse body diode drop from 0V (aka ground) and all other IC pads not connected to 0V. This value will vary somewhat depending on what the pin does, but there is typically an ESD diode to ground or sometimes a body diode (e.g. open drain MOSFET), thus a value of .4V to .7V is valid to indicate a solder connection. Note the RS485 drivers will show high impedance on the differential lines, so skip those.

## Bias +5V

Apply a 30mA current limited (CC mode) supply set at 5V to the +5V (J7 pin 4) and 0V (J7 pin 2) header pins. Check that the input current is for the blank MCU. Turn off power.

```
^5 
{  "I_IN_BLANKMCU_mA":[4.2,] }
^4 removed LDO
{  "I_IN_BLANKMCU_mA":[5.2,] }
^3
{  "I_IN_BLANKMCU_mA":[2.1,1.8,2.2,2.2,],
    "LDO_V":[3.302,3.282,3.276,3.292,] }
```

## Set MCU Fuse

Install Git and AVR toolchain on Ubuntu (I use 18.04). 

```
sudo apt-get install git make gcc-avr binutils-avr gdb-avr avr-libc avrdude
```

Clone the RPUpi repository.

```
git clone https://github.com/epccs/RPUpi
cd RPUpi/Bootload
```

Connect a 5V supply with CC mode set at 30mA to the +5V (J7 pin 4) and  0V (J7 pin 2). Connect the ICSP tool (J9). The MCU needs its fuses set, so run the Makefile rule to do that. 

```
make fuse
```

Note: There is not a bootloader, it just sets fuses.

Disconnect the ICSP tool and measure the input current for 12Mhz crystal. It takes a long time to settle.

```
^5
{  "I_IN_MCU_12MHZ_LP-CRYSTAL_mA":[13.8,]}
^4
{  "I_IN_MCU_12MHZ_LP-CRYSTAL_mA":[14.9,]}
^3
{  "I_IN_MCU_12MHZ_LP-CRYSTAL_mA":[4.9,5.1,5.0,5.1,]}
```

## Load CheckDTR Firmware

Plug a header (or jumper) onto the +5V pin so that IOREF is jumpered to +5V, also jumper it to SPI_IOREF (J8 pin 2) with ez-hook. Connect TX pin to IOREF to pull it up (the RPUno/Irrigate7 normaly does his). Plug a CAT5 RJ45 stub with 100 Ohm RX, TX and DTR pair terminations. Connect the 5V supply with CC mode set at 90mA to the +5V (J7 pin 4) and  0V (J7 pin 2). Connect the ICSP tool (J9).

Use the command line to select the CheckDTR source working directory. Run the makefile rule used to load CheckDTR firmware that verifies DTR control is working:

```
cd ~RPUpi/CheckDTR
make isp
```

The program loops through the test. It blinks the red LED to show which test number is setup. If it keeps repeating a test then that test has failed.

As the firmware loops, the input current can be measured, it should have two distinct levels, one when the DTR pair is driven low and one when the DTR pair is not driven. The blinking LED leaves the DMM unsettled. Turn off the power.

```
^5
{  "DTR_HLF_LD_mA":[49.7,],
    "DTR_NO_LD_mA":[21.4,] }
^4
{  "DTR_HLF_LD_mA":[35.6,],
    "DTR_NO_LD_mA":[19.9,] }
^3
{  "DTR_HLF_LD_mA":[33.4,33.8,33.6,33.7,],
    "DTR_NO_LD_mA":[10.0,10.5,10.5,10.5,] }
```

Note: the ICSP tool is pluged in and has some pullups with the level shift.

## Check Differential Bias

Plug a header (or jumper) onto the +5V pin so that IOREF is jumpered to +5V. Plug a CAT5 RJ45 stub with 100 Ohm RX, TX and DTR pair terminations. Connect TX pin to 0V to pull it down to simulate the MCU sending data. Connect a 5V supply with CC mode set at 100mA to the +5V that was jumpered to IOREF (J8 pin 2) and 0V (J7 pin 2).

Hold down the shutdown switch while running the CheckDTR firmware to set TX_DE and RX_DE high.

Check  that the input current is cycling with a lower value and higher value. At the higher value is when the TX driver is driving the TX pair with half load and DTR driver is driving the DTR pair with a half load, while ony the TX pair is driven at the lower value. 

```
^5
{  "DTR_TX_HLF_LD_mA":[78.9,],
    "TX_HLF_LD_mA":[50.1,] }
^4
{  "DTR_TX_HLF_LD_mA":[50.5,],
    "TX_HLF_LD_mA":[35.0,] }
^3
{  "DTR_TX_HLF_LD_mA":[56.0,56.9,57.0,56.8,],
    "TX_HLF_LD_mA":[33.0,33.7,33.7,33.7,] }
```

## Differential Loopback with TX Driver

Plug a header (or jumper) onto the +5V pin so that IOREF is jumpered to +5V. Plug a CAT5 RJ45 stub with 100 Ohm RX, TX and DTR pair terminations. Connect TX pin to 0V to pull it down to simulate the MCU sending data. Connect a 5V supply with CC mode set at 130mA to the +5V that was jumpered to IOREF (J8 pin 2) and 0V (J7 pin 2).

NOTE: IOREF J7 pin 4 is not connected

Connect a RJ45 loopback connector to allow the TX differential pair to drive RX differential pair and measure the input current. The TX driver is now driving 50 Ohms, which is the normal load. Verify that RX has 0V on it now.

```
^5
{  "DTR_HLF_LD_TX_FL_LD_mA":[97.9,],
    "TX_FL_LD_mA":[69.3,] }
^4
{  "DTR_HLF_LD_TX_FL_LD_mA":[60.8,],
    "TX_FL_LD_mA":[45.7,] }
^3
{  "DTR_HLF_LD_TX_FL_LD_mA":[72.4,73.9,74.0,74.3,],
    "TX_FL_LD_mA":[49.1,50.7,50.9,51.0,] }
```

Turn off power.

## Differential Loopback with RX Driver

Continuing from previous test, now disconnect TX from ground and Connect it to IOREF, which will disable the TX driver (U2) so that the RX driver (U6) can operate through the RJ45 loopback. Keep the CAT5 RJ45 stub with 100 Ohm RX, TX and DTR pair terminations and the RJ45 loopback connector so the TX pair is looped back to the RX pair. 

Bias PI3V3 (J1 pin 1) with IOREF (The Pi will power this with 3.3V but it will work with the 5V on IOREF).

Connect PI_TX (J1 pin 8) to 0V (J1 pin 6) to cause the RX driver to drive the RX pair. 

ItemsUsedForTest9 RPUpi Items Used For Test 9

Power on 5V supply at 100mA. Hold down the shutdown switch while running the CheckDTR firmware to set TX_DE and RX_DE high.

Measure the supply current when RX is driven and when a DTR half load is added.

```
^4
{  "DTR_HLF_LD_RX_FL_LD_mA":[107.7,],
    "RX_FL_LD_mA":[79.7,] }
^4
{  "DTR_HLF_LD_RX_FL_LD_mA":[67.8,],
    "RX_FL_LD_mA":[52.0,] }
^3
{  "DTR_HLF_LD_RX_FL_LD_mA":[83.3,88.0,88.3,88.0,],
    "RX_FL_LD_mA":[60.0,65.0,65.1,65.0,] }
```

Turn off power. Disconnect everything.

## Bias VIN and Check +5V_2PI from SMPS

Apply a 30mA current limited (CC mode) supply set at 12.8V to the VIN (J7 pin 1) and 0V (J7 pin 3) header pins. Measure the SMPS providing +5V_2PI (J1 pin 2). Check that the input current is for no load. Turn off power.

```
^5
TBD
^4
{  "VIN@NOLD_mA":[0.2,],
    +5V2PI_V":[4.97*,] }
^3 * same SMPS
{  "VIN@NOLD_mA":[0.2,0.2,0.2,0.2,],
    +5V2PI_V":[4.97*,4.99,5.00,5.00,] }
```

## Host Lockout

The Remote firmware will ignore the host nRTS signal until the status bit is cleared.

Plug an [RPUftdi] shield with [Host2Remote] firmware onto an [RPUno] or Uno board (not the UUT but a separate board) connect the USB to computer and load [I2C-Debug] on it. Note that the default bootload address allows this to work.

[RPUftdi]: https://github.com/epccs/RPUftdi
[Host2Remote]: https://github.com/epccs/RPUftdi/tree/master/Host2Remote
[RPUno]: https://github.com/epccs/RPUno
[I2C-Debug]: https://github.com/epccs/RPUno/tree/master/i2c-debug

```
cd ~RPUno/i2c-debug
make bootload
```

Use picocom to set the bootload address. The RPUftdi is at address 0x30 and the UUT will be at address 0x31.

```
picocom -b 38400 /dev/ttyUSB0
...
Terminal ready
/0/iaddr 41
{"address":"0x29"}
/0/ibuff 3,49
{"txBuffer":[{"data":"0x3"},{"data":"0x31"}]}
/0/iread? 2
{"rxBuffer":[{"data":"0x3"},{"data":"0x31"}]}
```

Exit picocom (Cntl^a and Cntl^x). 

Plug the UUT (the [RPUpi] shield) onto a second RPUno board. Connect the ICSP tool to UUT (J9). Power the RPUno (e.g. connect supply set with 12.8V at 180mA CC).

Load the Remote firmware onto UUT. Use the command line to select the source working directory for the UUT bus manager firmware to use (i.e. [Remote]). Run the makefile rule used to load it:

[Remote]: https://github.com/epccs/RPUadpt/tree/master/Remote

```
cd ~RPUpi/Remote
make isp
```

The UUT RPU_ADDRESS defaults to 0x31 with that firmware, so the RPUno under the UUT will bootload when the computer opens the serial port on the RPUftdi. Now install [PwrMgt] on the RPUno under UUT. 

[PwrMgt]: https://github.com/epccs/RPUno/tree/master/PwrMgt

```
cd ~RPUno/PwrMgt
make bootload
```

Read the status byte from I2C with command 6, and check that it shows the host lockout bit 3 is set. A dumy byte (255) is put in the buffer to tell the slave to size the reply with one data byte.

```
picocom -b 38400 /dev/ttyUSB0
...
Terminal ready
/1/iaddr 41
{"address":"0x29"}
/1/ibuff 6,255
{"txBuffer":[{"data":"0x6"},{"data":"0xFF"}]}
/1/iread? 2
{"rxBuffer":[{"data":"0x6"},{"data":"0x8"}]}
```

Measure the analog values. The charge data is accumulated from the time the RPUno started.

```
/1/analog? 6,7
{"PWR_I":"0.017","PWR_V":"12.76"}
/1/charge?
{"CHRG_mAHr":"1.06","ACCUM_Sec":"224.58"}
```

Disconnect the Power.

## Pi Zero without SD card

Plug in a Pi Zero without an SD card. Power the RPUno with 12.8V and 250mA.

The Pi Zero takes about 15mA for a second and then 23mA without an SD card. Verify the Pi's zero used for test has a 3V3 output.

Note: pi-bench is 3.309V,

Measure the analog values from Ubuntu host over the RPUftid connection.

```
picocom -b 38400 /dev/ttyUSB0
...
Terminal ready
/1/analog? 6,7
{"PWR_I":"0.043","PWR_V":"12.66"}
```

Turn off the VIN pin

```
/1/vin DOWN
{"VIN":"ALT_DWN?"}
{"VIN":"I2C_HAULT"}
{"VIN":"AT_HAULT_CURR"}
{"VIN":"DELAY"}
{"VIN":"WEARLEVELINGCLEAR"}
{"VIN":"DOWN"}
/1/analog? 6,7
{"PWR_I":"0.017","PWR_V":"12.66"}
```

The Pi Zero is using about 26mA from 12.8V (which is converted to 5V befor going to the Pi Zero).

## Boot Headless Pi Zero

Connect a 12V8@250mA power supply to an RPUno (not yet on). Plug a Pi Zero into the RPUpi board. Plug an SD card setup with Raspbian and these headless [Linux] settings (e.g. pi2.local was pi-bench). Power the RPUno. Wait for the green LED on the Pi Zero to be uninterrupted.

[Linux]: ./linux.md

```
ssh pi2.local
```

The [RTS/CTS] functions should enable if these [Linux] settins have been used (e.g. pi-bench).

[RTS/CTS]: https://github.com/epccs/RPUpi/tree/master/RPiRtsCts

```
sudo ./bin/rpirtscts on
Pi Zero Rev 1.3 with 40 pin GPIO header detected
Enabling CTS0 and RTS0 on GPIOs 16 and 17
```

Write the address '1' (0x31) that will be sent when nRTS enables. Next clear the lockout bit to alow the Pi Zero to use the RPUBUS as a host (e.g. from the Pi Zero in sneaky mode).

```
picocom -b 38400 /dev/ttyAMA0
...
Terminal ready
/1/iaddr 41
{"address":"0x29"}
/1/ibuff 3,49
{"txBuffer[2]":[{"data":"0x3"},{"data":"0x31"}]}
/1/iread? 2
{"rxBuffer":[{"data":"0x3"},{"data":"0x31"}]}
/1/ibuff 7,0
{"txBuffer[2]":[{"data":"0x7"},{"data":"0x0"}]}
/1/iread? 2
# ASCII character glitch may show now since the local controller has just reset
```

After the local bus manager is at address '1' and will reset its local controler. Wait for the RPUBUS to start working again and then measure the analog values.

```
/1/analog? 6,7
{"PWR_I":"0.099","PWR_V":"12.62"}
/1/charge?
{"CHRG_mAHr":"15.12","ACCUM_Sec":"551.90"}
```

exit picocom

```
Ctrl-a and Ctrl-x
Thanks for using picocom
```

## SPI

Now install [SpiSlv] on the RPUno under the UUT (note bus manager was setup to broadcast its own bootload address in the previous test).

[SpiSlv]: https://github.com/epccs/RPUno/tree/master/SpiSlv

```
cd ~RPUno/SpiSlv
make bootload
```

Enable the AVR SPI interface and exit picocom

```
picocom -b 38400 /dev/ttyAMA0
...
Terminal ready
/1/spi UP
{"SPI":"UP"}
Ctrl-a and Ctrl-x
Thanks for using picocom
```

Compile spidev_test.c and run it (see [SpiSlv]) on the Pi Zero:

```
gcc -o spidev_test spidev_test.c
./spidev_test -s 500000 -D /dev/spidev0.0

spi mode: 0
bits per word: 8
max speed: 500000 Hz (500 KHz)

00 FF FF FF FF FF
FF 40 00 00 00 00
95 FF FF FF FF FF
FF FF FF FF FF FF
FF FF FF FF FF FF
FF DE AD BE EF BA
AD F0

./spidev_test -s 500000 -D /dev/spidev0.0

spi mode: 0
bits per word: 8
max speed: 500000 Hz (500 KHz)

0D FF FF FF FF FF
FF 40 00 00 00 00
95 FF FF FF FF FF
FF FF FF FF FF FF
FF FF FF FF FF FF
FF DE AD BE EF BA
AD F0
``` 

Note the SPI output is offset a byte since it was sent back from the AVR. Close SSH.

```
exit
```

Press the shutdown button and wait for the green LED on the Pi Zero to be off uninterrupted. For referance another host (e.g. from a RPUftdi or another RPUpi) can take the RPUBUS and use it to restart this Pi Zero (but it needs [PwrMgt] on the local controller). 

```
picocom -b 38400 /dev/ttyUSB0
...
Terminal ready
/1/vin DOWN
{"VIN":"ALT_DWN?"}
{"VIN":"I2C_HAULT"}
{"VIN":"AT_HAULT_CURR"}
{"VIN":"DELAY"}
{"VIN":"WEARLEVELINGCLEAR"}
{"VIN":"DOWN"}
/1/in
/1/vin UP
{"VIN":"UP"}
Ctrl-a and Ctrl-x
Thanks for using picocom
# wait for Pi led to be uninterrupted
ssh pi-bench.local
```

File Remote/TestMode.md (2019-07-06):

# Test Mode Commands

48..63 (Ox30..0x3F | 0b00110000..0b00111111)

48. save trancever control bits HOST_nRTS:HOST_nCTS:TX_nRE:TX_DE:DTR_nRE:DTR_DE:RX_nRE:RX_DE for test_mode.
49. recover trancever control bits after test_mode.
50. read trancever control bits durring test_mode, e.g. 0b11101010 is HOST_nRTS = 1, HOST_nCTS =1, DTR_nRE =1, TX_nRE = 1, TX_DE =0, DTR_nRE =1, DTR_DE = 0, RX_nRE =1, RX_DE = 0.
51. set trancever control bits durring test_mode, e.g. 0b11101010 is HOST_nRTS = 1, HOST_nCTS =1, TX_nRE = 1, TX_DE =0, DTR_nRE =1, DTR_DE = 0, RX_nRE =1, RX_DE = 0.

## Cmd 48 from a controller /w i2c-debug set transceiver test mode

Set test_mode, use the bootload port interface since the RPUbus transceivers are turned off.

``` 
picocom -b 38400 /dev/ttyUSB0
/1/iaddr 41
{"address":"0x29"}
/1/ibuff 48,1
{"txBuffer[2]":[{"data":"0x30"},{"data":"0x1"}]}
/1/iread? 2
{"rxBuffer":[{"data":"0x30"},{"data":"0x1"}]}
``` 

on the second I2C channel that is for SMBus's i2c block commands

``` 
picocom -b 38400 /dev/ttyUSB0
/0/iaddr 42
{"address":"0x2A"}
/0/ibuff 48,1
{"txBuffer[2]":[{"data":"0x30"},{"data":"0x1"}]}
/0/iwrite
{"returnCode":"success"}
/0/ibuff 48
{"txBuffer[1]":[{"data":"0x30"}]}
/0/iread? 2
{"rxBuffer":[{"data":"0x30"},{"data":"0x1"}]}
```

The first read does a write. SMBus then does a second write with the command and then a repeated start followed by reading the data. I am using a old buffer to supply the data from the first write. The command byte needs to match to setup the old buffer data for use by the transmit event callback. 

## Cmd 48 from a Raspberry Pi set transceiver test mode

Set test_mode with an R-Pi over SMBus.

``` 
python3
import smbus
bus = smbus.SMBus(1)
#write_i2c_block_data(I2C_ADDR, I2C_COMMAND, DATA)
#read_i2c_block_data(I2C_ADDR, I2C_COMMAND, NUM_OF_BYTES)
# what is my address
bus.write_i2c_block_data(42, 0, [255])
bus.read_i2c_block_data(42, 0, 2)
[0, 50]
# set the bootload address to my address
bus.write_i2c_block_data(42, 3, [50])
bus.read_i2c_block_data(42, 3, 2)
[3, 50]
# clear the host lockout status bit so serial from this host can work
bus.write_i2c_block_data(42, 7, [0])
print(bus.read_i2c_block_data(42,7, 2))
[7, 0]
exit()
# on an RPUno load the blinkLED application which uses the UART
git clone https://github.com/epccs/RPUno
cd /RPUno/BlinkLED
make
make bootload
# now back to 
python3
import smbus
bus = smbus.SMBus(1)
# and set the test_mode
bus.write_i2c_block_data(42, 48, [1])
print(bus.read_i2c_block_data(42, 48, 2))
[48, 1]
``` 

I had picocom in another SSH connection to see how the test mode was working (e.g., it turns off the transceivers and serial stops operating). 

``` 
picocom -b 38400 /dev/ttyAMA0
a

``` 

Use  command 50 to set the transceiver control bits and check them with picocom.

## Cmd 49 from a controller /w i2c-debug recover after transceiver test

Recover trancever control bits after test_mode.

data returned is the recoverd trancever control bits: HOST_nRTS:HOST_nCTS:TX_nRE:TX_DE:DTR_nRE:DTR_DE:RX_nRE:RX_DE

``` 
picocom -b 38400 /dev/ttyUSB0
/1/iaddr 41
{"address":"0x29"}
/1/ibuff 49,1
{"txBuffer[2]":[{"data":"0x31"},{"data":"0x1"}]}
/1/iread? 2
{"rxBuffer":[{"data":"0x31"},{"data":"0x15"}]}
``` 

on the second I2C channel that is for SMBus's i2c block commands

``` 
picocom -b 38400 /dev/ttyUSB0
/0/iaddr 42
{"address":"0x2A"}
/0/ibuff 49,1
{"txBuffer[2]":[{"data":"0x31"},{"data":"0x1"}]}
/0/iwrite
{"returnCode":"success"}
/0/ibuff 49
{"txBuffer[1]":[{"data":"0x31"}]}
/0/iread? 2
{"rxBuffer":[{"data":"0x31"},{"data":"0x15"}]}
``` 

The read has the old buffer from the write command, it show data that can be seen after power up e.g., 0x15 or 0b00010101. The trancever control bits are: HOST_nRTS:HOST_nCTS:TX_nRE:TX_DE:DTR_nRE:DTR_DE:RX_nRE:RX_DE

## Cmd 49 from a Raspberry Pi recover after transceiver test

Set test_mode with an R-Pi over SMBus.

``` 
python3
import smbus
bus = smbus.SMBus(1)
#write_i2c_block_data(I2C_ADDR, I2C_COMMAND, DATA)
#read_i2c_block_data(I2C_ADDR, I2C_COMMAND, NUM_OF_BYTES)
# end the test_mode data byte is replaced with the recoverd trancever control
bus.write_i2c_block_data(42, 49, [1])
print(bus.read_i2c_block_data(42, 49, 2))
[49, 21]
bin(21)
'0b10101'
``` 

The trancever control bits are: HOST_nRTS:HOST_nCTS:TX_nRE:TX_DE:DTR_nRE:DTR_DE:RX_nRE:RX_DE

So everything was enabled, it is sort of a stealth mode after power-up, and can allow a host to talk to new controllers on the bus if they don't toggle there RTS lines (e.g., the test case is an R-Pi on an RPUpi shield on an RPUno, all freshly powered.) Stealth mode ends when a byte is seen on the DTR pair, that is what will establish an accurate bus state, so stealth mode is an artifact of laziness after power up and may need to change. 

## Cmd 50 from a controller /w i2c-debug read trancever control bits

Read trancever control bits (HOST_nRTS:HOST_nCTS:TX_nRE:TX_DE:DTR_nRE:DTR_DE:RX_nRE:RX_DE) durring test_mode on bootload port with i2c-debug.

``` 
picocom -b 38400 /dev/ttyUSB0
/1/iaddr 41
{"address":"0x29"}
/1/ibuff 50,255
{"txBuffer[2]":[{"data":"0x32"},{"data":"0xFF"}]}
/1/iread? 2
{"rxBuffer":[{"data":"0x32"},{"data":"0x22"}]}
``` 

on the second I2C channel that is for SMBus's i2c block commands

``` 
picocom -b 38400 /dev/ttyUSB0
/0/iaddr 42
{"address":"0x2A"}
/0/ibuff 50,255
{"txBuffer[2]":[{"data":"0x32"},{"data":"0xFF"}]}
/0/iwrite
{"returnCode":"success"}
/0/ibuff 50
{"txBuffer[1]":[{"data":"0x32"}]}
/0/iread? 2
{"rxBuffer":[{"data":"0x32"},{"data":"0x22"}]}
```

## Cmd 50 from a Raspberry Pi read trancever control bits

Read trancever control bits (HOST_nRTS:HOST_nCTS:TX_nRE:TX_DE:DTR_nRE:DTR_DE:RX_nRE:RX_DE) durring test_mode with an R-Pi over SMBus.

``` 
python3
import smbus
bus = smbus.SMBus(1)
#write_i2c_block_data(I2C_ADDR, I2C_COMMAND, DATA)
#read_i2c_block_data(I2C_ADDR, I2C_COMMAND, NUM_OF_BYTES)
# end the test_mode data byte is replaced with the recoverd trancever control
bus.write_i2c_block_data(42, 50, [255])
print(bus.read_i2c_block_data(42, 50, 2))
[50, 34]
``` 

## Cmd 51 from a controller /w i2c-debug set trancever control bits

Set trancever control bits (HOST_nRTS:HOST_nCTS:TX_nRE:TX_DE:DTR_nRE:DTR_DE:RX_nRE:RX_DE) durring test_mode on bootload port with i2c-debug.

``` 
picocom -b 38400 /dev/ttyUSB0
/1/iaddr 41
{"address":"0x29"}
/1/ibuff 51,38
{"txBuffer[2]":[{"data":"0x33"},{"data":"0x26"}]}
/1/iread? 2
{"rxBuffer":[{"data":"0x33"},{"data":"0x26"}]}
``` 

0x26 = HOST_nRTS==0:HOST_nCTS=0:TX_nRE==1:TX_DE==0:DTR_nRE==0:DTR_DE==1:RX_nRE==1:RX_DE==0 e.g., DTR trancever is on.

on the second I2C channel that is for SMBus's i2c block commands

``` 
picocom -b 38400 /dev/ttyUSB0
/0/iaddr 42
{"address":"0x2A"}
/0/ibuff 51,38
{"txBuffer[2]":[{"data":"0x33"},{"data":"0x26"}]}
/0/iwrite
{"returnCode":"success"}
/0/ibuff 51
{"txBuffer[1]":[{"data":"0x33"}]}
/0/iread? 2
{"rxBuffer":[{"data":"0x33"},{"data":"0x26"}]}
```

## Cmd 51 from a Raspberry Pi read trancever control bits

Set trancever control bits (HOST_nRTS:HOST_nCTS:TX_nRE:TX_DE:DTR_nRE:DTR_DE:RX_nRE:RX_DE) durring test_mode with an R-Pi over SMBus.

``` 
python3
import smbus
bus = smbus.SMBus(1)
#write_i2c_block_data(I2C_ADDR, I2C_COMMAND, DATA)
#read_i2c_block_data(I2C_ADDR, I2C_COMMAND, NUM_OF_BYTES)
# end the test_mode data byte is replaced with the recoverd trancever control
bus.write_i2c_block_data(42, 51, [38])
print(bus.read_i2c_block_data(42, 51, 2))
[51, 38]
```

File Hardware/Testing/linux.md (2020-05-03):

# Description

This is a list of notes regarding Raspbin (Linux) things for RPUpi.

# Table Of Contents:

1. Prepare SD Card
1. Headless Setup
1. Network Setup
1. SSH
1. Samba
1. Web Server
1. Python 3
1. Serial
1. Packages used for the AVR toolchain
1. SPI, I2C and IO
1. WiFi Dropout
1. Package Updates
1. Editor

## Prepare SD Card

Download the latest [Raspbin] image.
        
[Raspbin]: https://www.raspberrypi.org/downloads/raspbian/

Download [Etcher] (note, I have only used this on Ubuntu)
        
[Etcher]: https://etcher.io/

or new Pi [Imager]
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

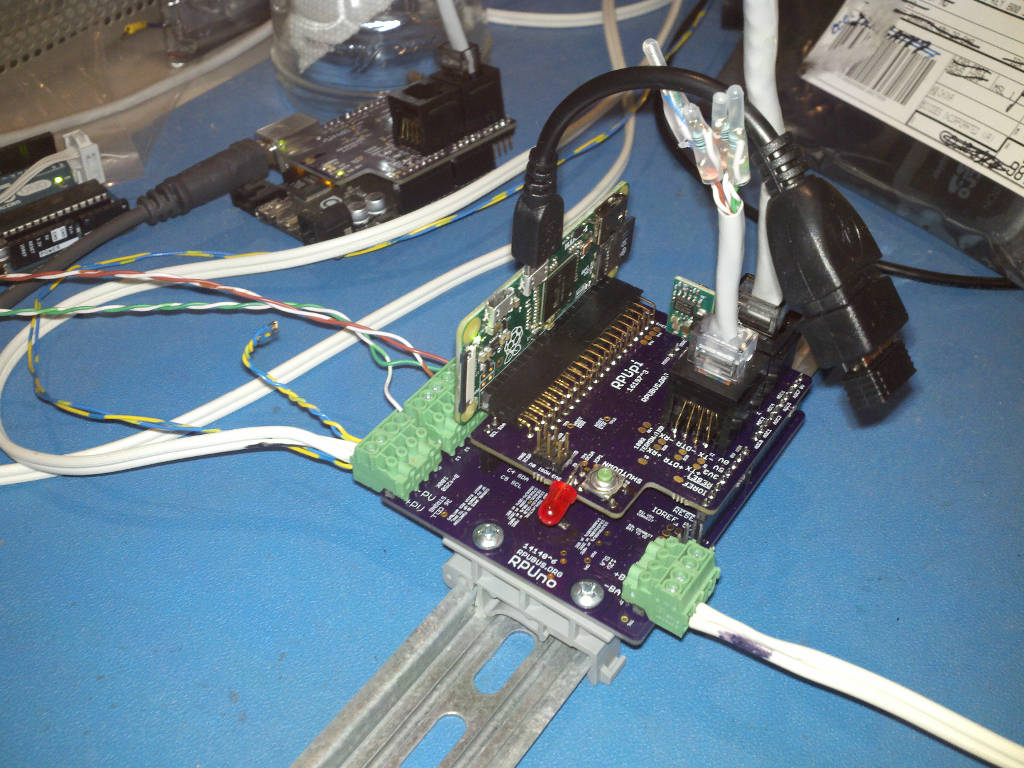
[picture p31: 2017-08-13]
Hardware/Evaluation/16197^3,PiZeroUsedToBootloadATmega328pUnderRPUftdi^4.jpg

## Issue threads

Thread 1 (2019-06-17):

Clock-stretching has corrupted SMBus data.

epccs, 2019-06-17:
The twi1 interface of the Atmega328pb is connected to the R-Pi Zero host. I am using write_i2c_block_data(42, 48, [1]) and read_i2c_block_data(42, 48, 2) python commands which are from:

https://git.kernel.org/pub/scm/utils/i2c-tools/i2c-tools.git/tree/py-smbus

The problem with R-Pi (BCM2835) and clock-stretching is well known.

http://www.advamation.com/knowhow/raspberrypi/rpi-i2c-bug.html

epccs, 2019-06-17:
Interleaving between two buffers (A and B) within the ISR used by SMBus seems to have done the trick.

https://github.com/epccs/RPUpi/commit/089455a040c1aaae76031a735f9558047b78a573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

The buffer used by the ISR is swapped after passing it to the user (e.g., with receive callback function). The user receive function runs within the ISR context, but now it can be concise (e.g., save the pointer and byte count). Then all the work can be done outside of ISR context since the buffer is no longer in the risk of being changed, at least until a subsequent receive event when it will be swapped back into service.

https://github.com/epccs/RPUpi/commit/089455a040c1aaae76031a735f9558047b78a573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

The quick receive event seems to be tolerated by the R-Pi's clock, but more testing is needed. The handle_smbus function is run in the main loop if there are SMBus bytes available.

I have read about a lot of I2C problems over the years; I guess it is difficult to do the hardware.

epccs, 2019-08-09:
A fair amount of SMBus commands have been sent without any errors, so I am going to call this fixed.

Closed 2019-08-09.

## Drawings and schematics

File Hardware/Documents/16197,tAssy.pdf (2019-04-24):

5V IN | uUSB | HDMI

# uSD

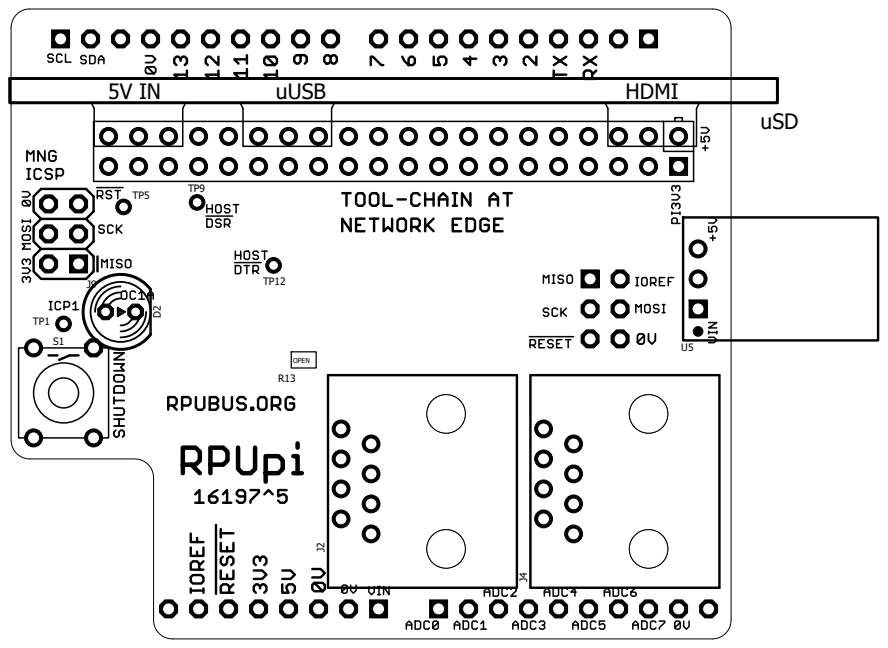
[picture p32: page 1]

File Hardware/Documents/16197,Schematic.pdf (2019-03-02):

# RPU_BUS

TX

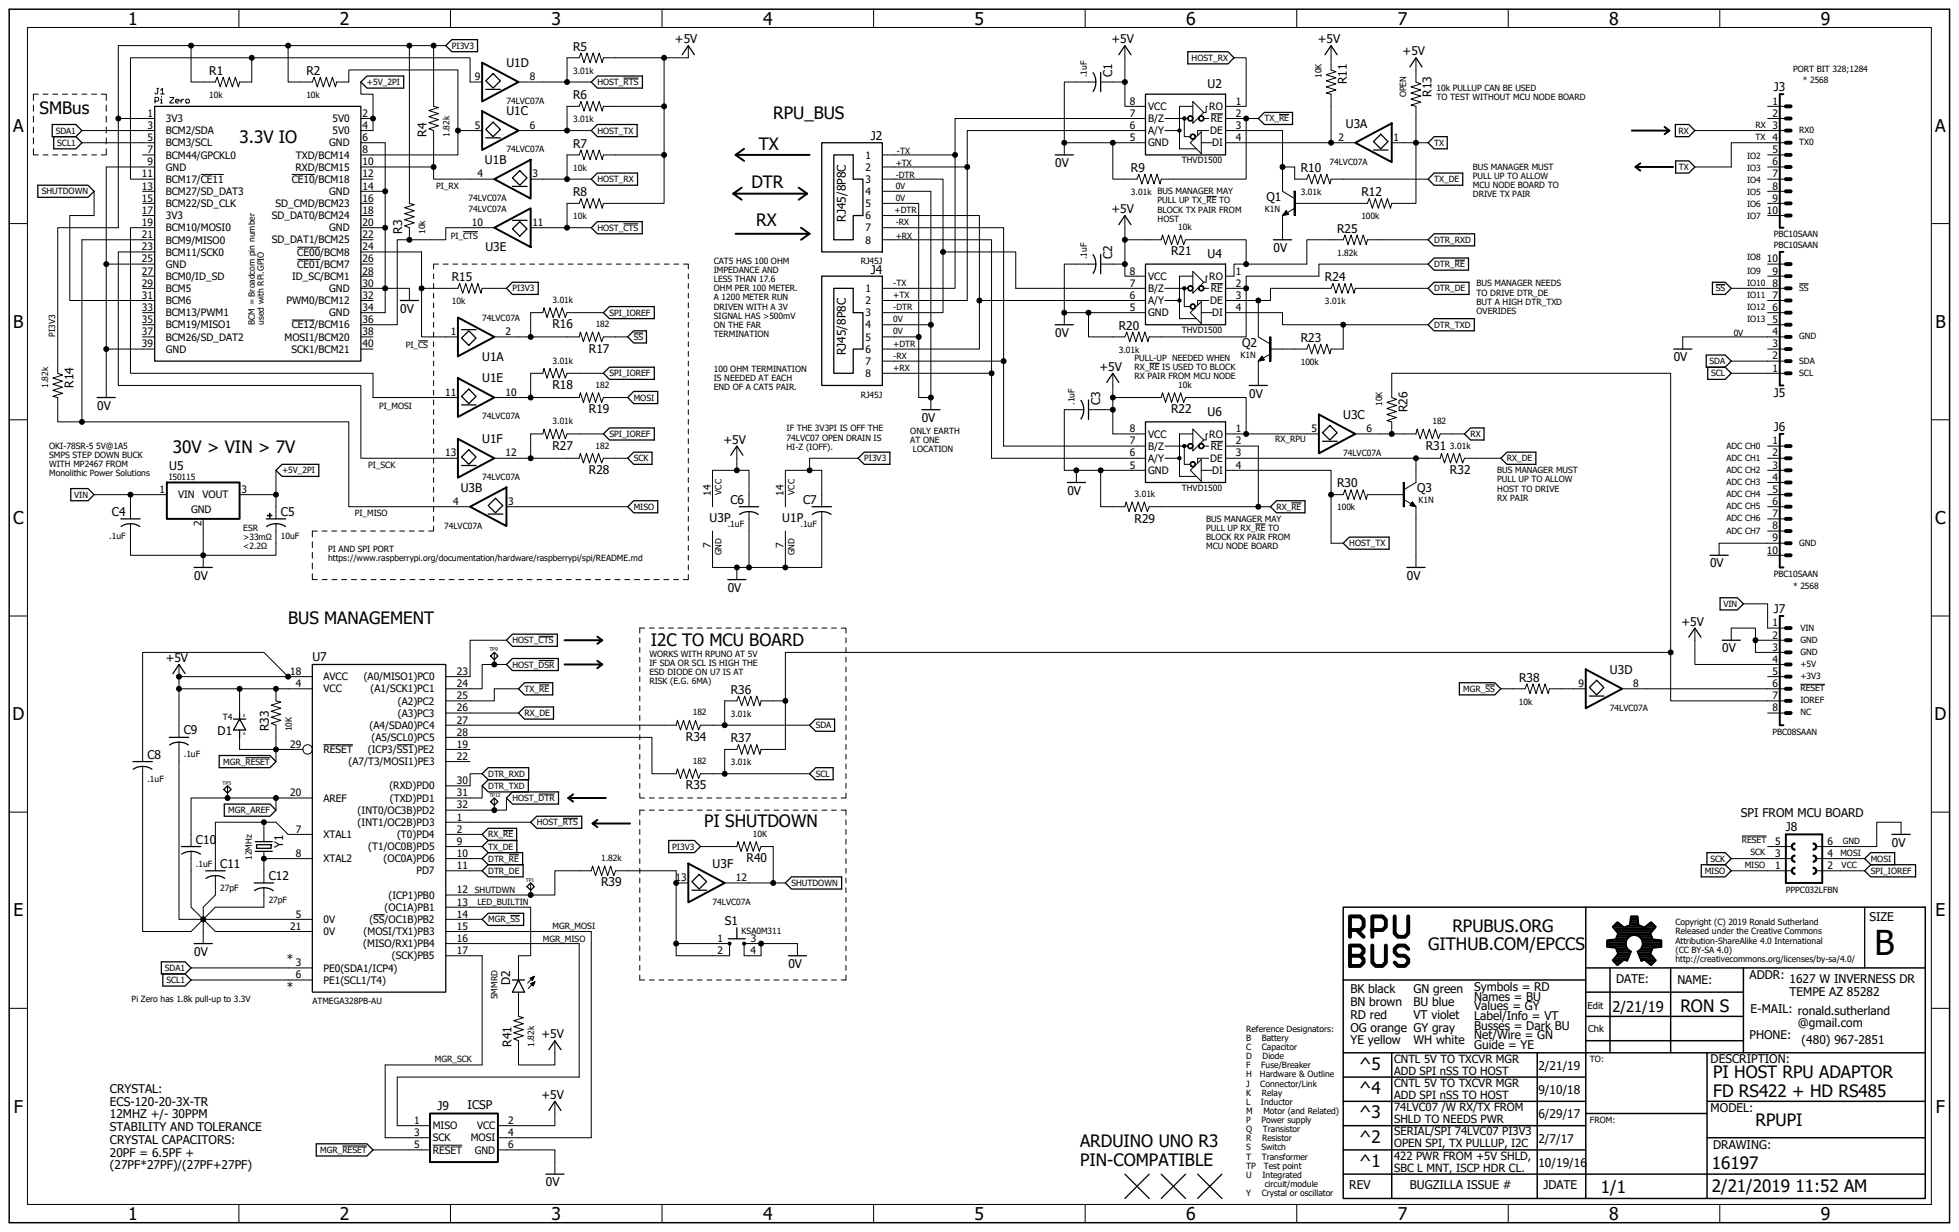
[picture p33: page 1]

10k PULLUP CAN BE USED
TO TEST WITHOUT MCU NODE BOARD

BUS MANAGER MUST
PULL UP TO ALLOW
MCU NODE BOARD TO
DRIVE TX PAIR

BCM = Broadcom pin number

used with RPi.GPIO

100 OHM TERMINATION
IS NEEDED AT EACH
END OF A CAT5 PAIR.

RX_RE IS USED TO BLOCK
RX PAIR FROM MCU NODE

IF THE 3V3PI IS OFF THE
74LVC07 OPEN DRAIN IS
HI-Z (IOFF).

OKI-78SR-5 5V@1A5
SMPS STEP DOWN BUCK
WITH MP2467 FROM
Monolithic Power Solutions

HOST TO DRIVE
RX PAIR

BUS MANAGER MAY
PULL UP RX_RE TO
BLOCK RX PAIR FROM
MCU NODE BOARD

PI AND SPI PORT
https://www.raspberrypi.org/documentation/hardware/raspberrypi/spi/README.md

I2C TO MCU BOARD
WORKS WITH RPUNO AT 5V
IF SDA OR SCL IS HIGH THE
ESD DIODE ON U7 IS AT
RISK (E.G. 6MA)

SPI FROM MCU BOARD

Copyright (C) 2019 Ronald Sutherland
Released under the Creative Commons
Attribution-ShareAlike 4.0 International
http://creativecommons.org/licenses/by-sa/4.0/

Pi Zero has 1.8k pull-up to 3.3V

Edit | 2/21/19 | RON S

Chk

^5 | CNTL 5V TO TXCVR MGR ADD SPI nSS TO HOST | 2/21/19 | TO: | DESCRIPTION: PI HOST RPU ADAPTOR FD RS422 + HD RS485
^4 | CNTL 5V TO TXCVR MGR ADD SPI nSS TO HOST | 9/10/18
^3 | 74LVC07 /W RX/TX FROM SHLD TO NEEDS PWR | 6/29/17 | | MODEL: RPUPI

^1 | 422 PWR FROM +5V SHLD, SBC L MNT, ISCP HDR CL. | 10/19/16

REV | BUGZILLA ISSUE # | JDATE

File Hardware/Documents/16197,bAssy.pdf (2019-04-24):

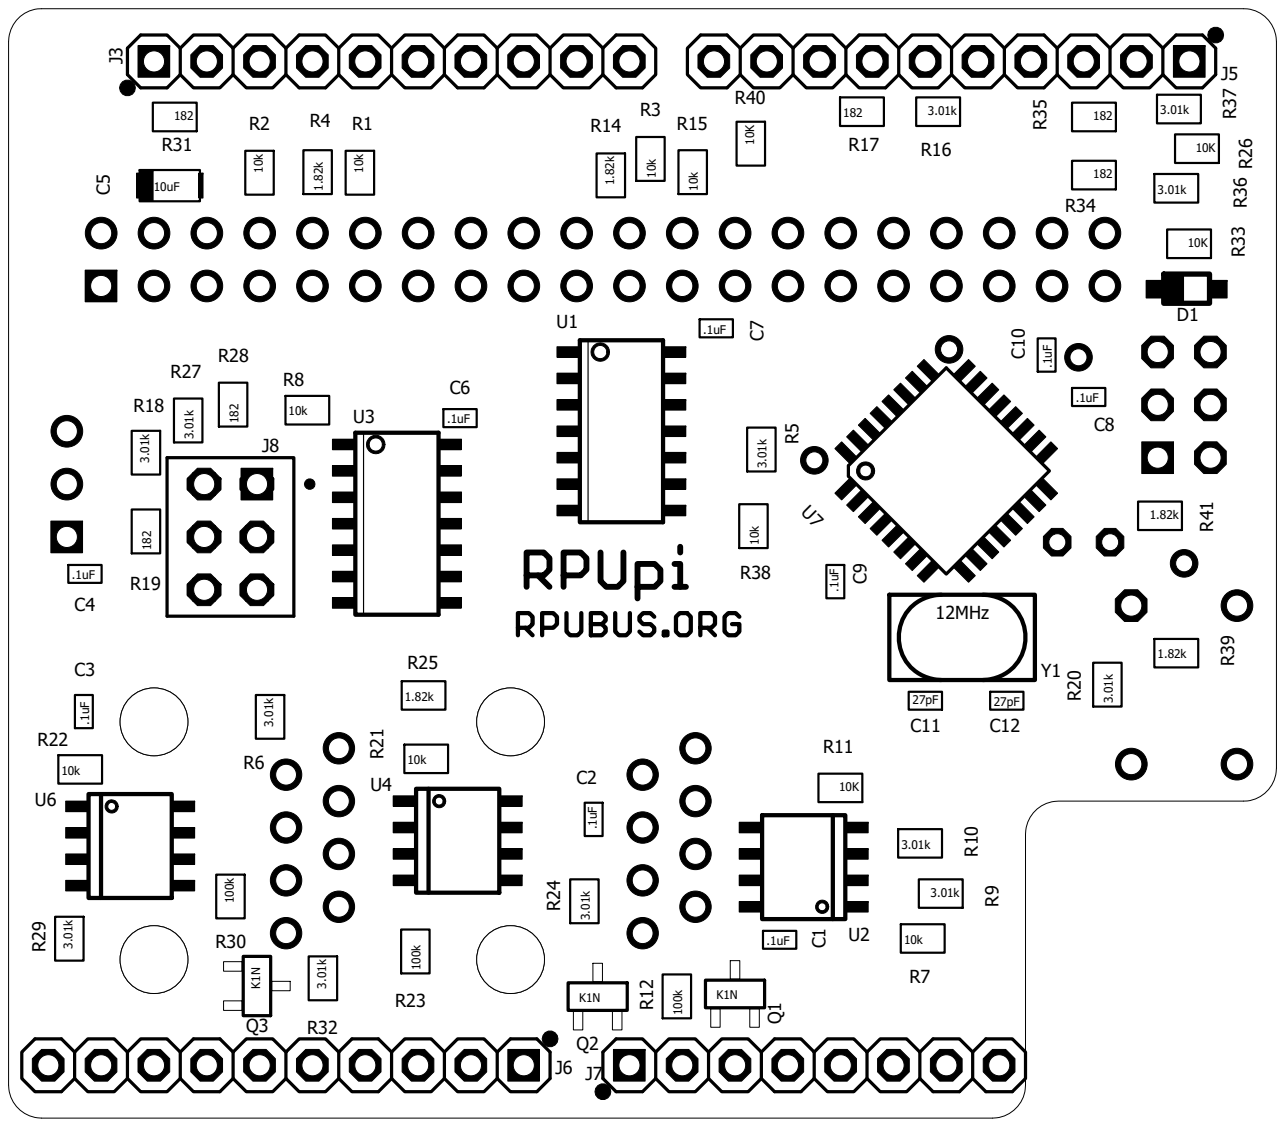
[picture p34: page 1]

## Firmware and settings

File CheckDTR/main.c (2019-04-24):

/* CheckDTR for hardware testing on RPUpi
 Copyright (C) 2016 Ronald Sutherland

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
For a copy of the GNU General Public License use
http://www.gnu.org/licenses/gpl-2.0.html
 
story: first RPUadpt^3 board had a little bridge of solder between DTR_RXD and DTR_TXD
three days was spent chasing the ghost.
*/ 

#include <util/delay.h>
#include <avr/io.h>
#include "../lib/timers.h"
#include "../lib/pin_num.h"
#include "../lib/pins_board.h"

static unsigned long blink_started_at;
static uint8_t Check_Diff_Bias;

void blink(uint8_t count)
{
    unsigned long kRuntime;
    
    for (uint8_t i=0 ;i<count; i++)
    {
        digitalToggle(LED_BUILTIN);
        kRuntime = 0;
        blink_started_at = millis();
        while (kRuntime <= 300) // wait for 1/10 second
        {
            kRuntime = millis() - blink_started_at;
        }
        digitalToggle(LED_BUILTIN);
        kRuntime = 0;
        blink_started_at = millis();
        while (kRuntime <= 300) // wait for 1/10 second
        {
            kRuntime = millis() - blink_started_at;
        }
    }
}

int main(void)
{
    pinMode(LED_BUILTIN,OUTPUT);
    digitalWrite(LED_BUILTIN,LOW);

    // setup RTS/CTS so they are disabled
    pinMode(HOST_nRTS, INPUT);
    digitalWrite(HOST_nRTS, HIGH); // with AVR when the pin DDR is set as an input setting pin high will trun on a weak pullup 
    pinMode(HOST_nCTS, OUTPUT);
    digitalWrite(HOST_nCTS, HIGH);

    // setup DTR/DSR, they are just test points on RPUpi
    pinMode(HOST_nDTR, INPUT);
    digitalWrite(HOST_nDTR, HIGH); // another weak pullup 
    pinMode(HOST_nDSR, OUTPUT);
    digitalWrite(HOST_nDSR, LOW);

    // setup DTR transceiver
    pinMode(DTR_TXD,OUTPUT);
    digitalWrite(DTR_TXD,LOW);
    pinMode(DTR_DE,OUTPUT);
    digitalWrite(DTR_DE, LOW);  // yep there is startup glitch, so disallow DTR pair driver until after the UART is running.
    pinMode(DTR_nRE,OUTPUT);
    digitalWrite(DTR_nRE,LOW);

    // setup TX and RX transceiver so both the host and node are locked out from the differential pairs 
    pinMode(RX_DE, OUTPUT);
    digitalWrite(RX_DE, LOW);  // disallow RX pair driver to enable if FTDI_TX is low
    pinMode(RX_nRE, OUTPUT);
    digitalWrite(RX_nRE, HIGH);  // disable RX pair recevior to output to local MCU's RX input
    pinMode(TX_DE, OUTPUT);
    digitalWrite(TX_DE, LOW); // disallow TX pair driver to enable if TX (from MCU) is low
    pinMode(TX_nRE, OUTPUT);
    digitalWrite(TX_nRE, HIGH);  // disable TX pair recevior to output to FTDI_RX input

    // do not use this firmware with a node board, or a Pi Zero 
    pinMode(nSS, OUTPUT); // nSS is connected to a open collector buffer used to pull the node's MCU nRESET low
    digitalWrite(nSS, LOW); 
    pinMode(SHUTDOWN, INPUT);
    digitalWrite(SHUTDOWN, HIGH); // weak pull-up. This is used to remove RX/TX lockout

    initTimers(); //Timer0 Fast PWM mode, Timer1 & Timer2 Phase Correct PWM mode.

    sei(); // Enable global interrupts to start TIMER0

    // the UART has a startup glitch... this should keep it from the DTR pair.
    // NOTE UART is not initalized for this program, but will keep the logic.
    _delay_ms(10);
    digitalWrite(DTR_DE, HIGH); 

    while (1) 
    {
        _delay_ms(4000);

        // set DTR transceiver DI input with 0V.
        digitalWrite(DTR_TXD,LOW);
        // set DTR transceiver DTR_DE HIGH to drive DTR pair, R12 has 3.3V.
        digitalWrite(DTR_DE,HIGH);
        // set DTR_nRE LOW cause transceiver to copy DTR pair to RO output
        digitalWrite(DTR_nRE,LOW);
        
        // DTR pair should be driven LOW by DI and copy its value to RO
        do
        {    
            blink(1);
            _delay_ms(1000);
        } while (digitalRead(DTR_RXD) != LOW);

        // set DTR transceiver DI input with 3.3V should cause an undriven pair
        digitalWrite(DTR_TXD,HIGH);

        // a High on DTR_TXD causes Q2 to pull down DTR_DE so the
        // DTR pair should be undriven which is seen at RO as a HIGH 
        do
        {    
            blink(2);
            _delay_ms(1000);
        } while(digitalRead(DTR_RXD) != HIGH);
 
        digitalWrite(DTR_DE,LOW);
        // set DTR_nRE HIGH to disconnect transceiver so R10 pulls up RO output
        digitalWrite(DTR_nRE,HIGH);
        digitalWrite(DTR_TXD,LOW);

        // DTR pair should be driven LOW but RO is disconnected and should pull-up to PASS
        do
        {    
            blink(3);
            _delay_ms(1000);
        } while (digitalRead(DTR_RXD) != HIGH);

        // set DTR_DE HIGH to copy DI onto DTR pair.
        digitalWrite(DTR_DE,HIGH);

        // DTR pair should not be driven and RO is disconnected and should pull-up to PASS
        do
        {    
            blink(4);
            _delay_ms(1000);
        } while (digitalRead(DTR_RXD) != HIGH);
        uint8_t shutdown_now = !digitalRead(SHUTDOWN);

        // if the shutdown switch is pressed then remove RX/TX lockout
        if (!Check_Diff_Bias && shutdown_now)
        {
            Check_Diff_Bias = 1;
            digitalWrite(RX_DE, HIGH);  // allow RX pair driver to enable if FTDI_TX is low
            digitalWrite(RX_nRE, LOW);  // enable RX pair recevior to output to local MCU's RX input
            digitalWrite(TX_DE, HIGH); // allow TX pair driver to enable if TX (from MCU) is low
            digitalWrite(TX_nRE, LOW);  // enable TX pair recevior to output to FTDI_RX input
        }
    }    
}

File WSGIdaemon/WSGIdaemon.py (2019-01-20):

#!/usr/bin/env python3
# Copyright (C) 2018 Ronald S Sutherland
#
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
# Web Server Gateway Interface (WSGI) daemon 
# use web server techniques to act as a gateway interface to a serial link 
#
# at CLI
# python3 WSGIdaemon.py
#
# set the host value (near bottom) for your machine
# to try the interface open a brower with url: http://host:8000/?addr=0&cmd=id&q=true

# For info on WSGI see https://docs.python.org/3.7/library/wsgiref.html
# For info on CGI see https://docs.python.org/3.7/library/cgi.html

# The goal is to hold a serial link open while client(s) make request to access the serial link.
# it takes parameters from the query string and turns them into the serail commands I use e.g. "/0/id?" or "/0/adc 3,4,5" 

# Using python3 so make sure the serial package is installed. 
# sudo apt-get install python3-serial 

import sys
sys.path.append('wsgiac') #allow import of Access Control
from accesscontrol import  AccessControlMiddleware
import json
import serial
from time import sleep
import wsgiref.simple_server
from cgi import parse_qs, escape
import os

# claim the serial link (e.g. it is a resourse that I will provide use of)
# hardwar serial on R-Pi is/dev/ttyAMA0
# FTDI and some other usb serial is /dev/ttyUSB0
# Arduino's ATmega16u2 is a modem... what? /dev/ttyACM0
if os.uname().machine == 'i686': # Ubuntu with RPUftdi
    device = "/dev/ttyUSB0"
if os.uname().machine == 'armv6l': # R-Pi's hardware UART
    device = "/dev/ttyAMA00"
sio = serial.Serial(device,38400, timeout=3)
print("serial link " + device)

# A relatively simple WSGI application. 
def simple_app(environ, start_response):
    
    # Returns a dictionary from CGI in which the values are lists, it is the easy way
    query_string = parse_qs(environ['QUERY_STRING'])
    #given URL: http://localhost:8000/?addr=0&cmd=id&q=true&arg1=1&arg2=2&arg3=3&arg4=4&arg5=5
    #the QUERY_STRING is: addr=0&cmd=id&q=true&arg1=1&arg2=2&arg3=3&arg4=4&arg5=5
    addr = query_string.get('addr', [''])[0] # Returns the first addr value
    cmd_base = query_string.get('cmd', [''])[0] # Returns the first cmd value
    q = query_string.get('q', [''])[0] # Returns the first q value
    arg1 = query_string.get('arg1', [''])[0] # Returns the first argument value
    arg2 = query_string.get('arg2', [''])[0] # Returns the first argument value
    arg3 = query_string.get('arg3', [''])[0] # Returns the first argument value
    arg4 = query_string.get('arg4', [''])[0] # Returns the first argument value
    arg5 = query_string.get('arg5', [''])[0] # Returns the first argument value

    #check for correctness of command
    if (addr == ''):
        addr = '0' # for default of /0/id?
    if ( not (addr.isalnum() and (len(addr) == 1) ) ):
        status = '400 Bad Request'
        headers = [('Content-type', 'text/plain; charset=utf-8')]
        start_response(status, headers)
        ret = [ ("ERR: addr must be a string of len == 1 that isalnum\n").encode('utf-8') + 
                (b"ERR: bad query_string \"addr=" + addr.encode('utf-8') + b"\"\n").decode().encode('utf-8') ]
        return ret
    if (cmd_base == ''):
        cmd_base = "id" # default
    if ( not (cmd_base.isalpha()) ):
        status = '400 Bad Request'
        headers = [('Content-type', 'text/plain; charset=utf-8')]
        start_response(status, headers)
        ret = [ ("ERR: cmd must be a string that isalpha\n").encode('utf-8') + 
                (b"ERR: bad query_string \"cmd=" + cmd_base.encode('utf-8') + b"\"\n").decode().encode('utf-8') ]
        return ret

    # start putting the command togather
    command =  "/"+addr+"/"+cmd_base

    if (q == ''):
        q = 'true' # default needs a ? after the cmd_base 
    if ( not ( (q == 'true') or (q == 'false')) ):
        status = '400 Bad Request'
        headers = [('Content-type', 'text/plain; charset=utf-8')]
        start_response(status, headers)
        ret = [ ("ERR: q must be true or false\n").encode('utf-8') + 
                (b"ERR: bad query_string \"q=" + q.encode('utf-8') + b"\"\n").decode().encode('utf-8') ]
        return ret

    # baggage from looking at GPIB commands for too many years
    if (q == "true"):
        command =  command+"?"

    if (len(arg1) >= 1):
        if ( not (arg1.isalnum() ) ):
            status = '400 Bad Request'
            headers = [('Content-type', 'text/plain; charset=utf-8')]
            start_response(status, headers)
            ret = [ ("ERR: arg1 must be a string that isalnum\n").encode('utf-8') + 
                    (b"ERR: bad query_string \"arg1=" + arg1.encode('utf-8') + b"\"\n").decode().encode('utf-8') ]
            return ret
        command =  command+" "+arg1
        
        #ignore arg2 if arg1 not given
        if (len(arg2) >= 1):
            if ( not (arg2.isalnum() ) ):
                status = '400 Bad Request'
                headers = [('Content-type', 'text/plain; charset=utf-8')]
                start_response(status, headers)
                ret = [ ("ERR: arg2 must be a string that isalnum\n").encode('utf-8') + 
                        (b"ERR: bad query_string \"arg2=" + arg2.encode('utf-8') + b"\"\n").decode().encode('utf-8') ]
                return ret
            command =  command+","+arg2

            #ignore arg3 if arg2 not given
            if (len(arg3) >= 1):
                if ( not (arg3.isalnum() ) ):
                    status = '400 Bad Request'
                    headers = [('Content-type', 'text/plain; charset=utf-8')]
                    start_response(status, headers)
                    ret = [ ("ERR: arg3 must be a string that isalnum\n").encode('utf-8') + 
                            (b"ERR: bad query_string \"arg3=" + arg3.encode('utf-8') + b"\"\n").decode().encode('utf-8') ]
                    return ret
                command =  command+","+arg3

                #ignore arg4 if arg3 not given
                if (len(arg4) >= 1):
                    if ( not (arg4.isalnum() ) ):
                        status = '400 Bad Request'
                        headers = [('Content-type', 'text/plain; charset=utf-8')]
                        start_response(status, headers)
                        ret = [ ("ERR: arg4 must be a string that isalnum\n").encode('utf-8') + 
                                (b"ERR: bad query_string \"arg4=" + arg4.encode('utf-8') + b"\"\n").decode().encode('utf-8') ]
                        return ret
                    command =  command+","+arg4
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

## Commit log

2016-10-12 Lockout: with shutdown pin and a non-blocking blink
2016-10-12 RPiRtsCts: tool used to enable RTS/CTS flow control
2016-10-14 CheckDTR: use the shutdown switch to remove RX/TX lockout
2016-11-16 Hardware: add
    [16197,BOM.csv, 16197.brd, 16197.sch]
2016-12-19 Hardware: moving more to Github
    [16197,BOM.csv, 16197.brd, 16197.sch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]
2016-12-21 Hardware: assy ^1 done, issue with i2c found and the workaround
    [16197,BOM.csv]
2016-12-22 Hardware: evaluate mounting
2017-01-24 Hardware: note problem with serial at power down
2017-01-24 example is a little more refined
    [MultiDrop.sch]
2017-02-08 Hardware: ^2 dsgn in wip
    [16197.brd, 16197.sch, MultiDrop.sch]
2017-04-12 Hardware: ^2 review
    will move away from eagle, so not going to include
    [16197.brd, 16197.sch]
2017-04-13 Hardware: ^2 bom up to date
    [16197,BOM.csv]
2017-04-13 Hardware: 100 ohm termination not placed
2017-05-10 Hardware: change bom to comma separated values
    [16197,BOM.csv]
2017-05-14 Hardware: ^2 assembly
    [16197,BOM.csv]
2017-05-26 Remote: add this firmware from RPUadpt
    [16197,BOM.csv]
2017-05-27 Hardware: problem, U3 does not have power so serial from shild is blocked
2017-07-02 Hardware: ^3 on order
    [16197,BOM.csv]
2017-07-30 Hardware: ^3 assembly done
2017-08-11 Hardware: ^3 testing done, omg it bootloads once cts/rts is enabled.
    [16197,BOM.csv]
2017-08-14 Remote: document sneaky mode which it is doing now (more or less) at power up
2017-08-15 Hardware: detect BOOT_PORT with makefile for controller board firmware
2017-08-24 Hardware: ^3 build with new parts and test spi
2017-10-01 Hardware: link linux wireless cli setup for r-pi
2018-01-12 Hardware: doc of a simplified serial between Pi and AVR
    [Pi2AVR.sch]
2018-01-12 Hardware: add gnd to simple serial view
    [Pi2AVR.sch]
2018-01-13 Hardware: remove weak pull-up from simple serial view
    [Pi2AVR.sch]
2018-01-14 Hardware: add more info on pi2avr simple serial
    [Pi2AVR.sch]
2018-01-17 Hardware: add more info on simple serial, pi2avr with ioff
    [Pi2AVR_wIOFF.sch]
2018-01-18 Hardware: simple serial, pi2avr with ioff at 16MHz
    [Pi2AVR_wIOFF.sch]
2018-01-30 Hardware: notes for VSC
    [Pi2AVR_wIOFF.sch]
2018-03-29 Remote: readme show i2c-debug^1 commands, also how to enable Pi zero as a host
2018-05-28 Hardware: linux wifi ssid case
2018-09-16 Hardware: ^4 schmatic design
    [MultiDrop.sch, Pi2AVR.sch, Pi2AVR_wIOFF.sch]
2018-09-20 Hardware: ^4 layout, bom is next
2018-09-22 Hardware: ^4 bom, review is next
    [16197,BOM.csv, 16197BRD,BOM.csv, 16197CAT,BOM.csv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]
2018-10-10 WSGIdaemon: at proof of concept stage
2018-10-31 Hardware: ^4 reviewing+ 485tx_en worked thus swap K38 for K1N
    [16197SMD,BOM.csv]
2019-02-15 Hardware: ^4 assembly done
    [16197BRD,BOM.csv, 16197CAT,BOM.csv, 16197HDR,BOM.csv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]
2019-02-21 BlinkLED: copy from RPUadpt and add 328pb files from atpack 1.3.300
    [16197BRD,BOM.csv, 16197CAT,BOM.csv, 16197HDR,BOM.csv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]
2019-02-24 Remote: on ^4 the 328pb has i2c1 to use with r-pi smbus
2019-04-24 licences LGPL in lib files and GPL in the app files
    [16197BRD,BOM.csv, 16197CAT,BOM.csv, 16197HDR,BOM.csv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]
2019-04-28 Remote: refactor i2c and smbus commands
2019-05-13 Remote: use i2c command as index of function pointer array
2019-05-20 Remote: use i2c commmands for smbus commands, smbus buffer works same as past
2019-05-21 Remote: add arduino_mode
2019-06-03 uart glitch at init, optiboot does not glitch so do what it does.
2019-06-03 Remote: simple main, uart should be glitch free at init
    [main.c]
2019-06-08 Remote: found uart was not glitch free, when testing p2p mode
    [main.c]
2019-06-11 Remote: test_mode wip, having issue with i2c command echo
2019-06-18 Remote: glitch on DTR pair, so split out functions to think about them.
    also working on transceiver test mode
    [main.c]
2019-07-05 Remote: shutdown, manual works more like i2c cmd
2019-07-11 Hardware: use 100 ohm on both ends of rpubus for evaluation

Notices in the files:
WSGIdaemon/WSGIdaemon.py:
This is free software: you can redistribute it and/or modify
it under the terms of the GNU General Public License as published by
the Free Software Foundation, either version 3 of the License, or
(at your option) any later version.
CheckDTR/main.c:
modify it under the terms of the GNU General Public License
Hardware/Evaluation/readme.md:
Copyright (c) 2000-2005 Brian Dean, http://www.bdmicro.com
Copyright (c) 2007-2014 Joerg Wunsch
